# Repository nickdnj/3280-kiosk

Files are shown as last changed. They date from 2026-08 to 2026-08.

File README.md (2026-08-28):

# 3280 Kiosk

An interactive exhibit kiosk for the Vintage Computer Federation museum's
**Concurrent 3280**. A portrait display in a self-contained enclosure, mounted on
the front of the machine's closed factory door. Driven by **three physical
buttons only: BACK / HOME / NEXT. No touchscreen.**

**Rev 1 is a standalone product.** The kiosk is built, wired and bench-tested on
a table before it ever touches the 3280; the reversible mounting adapter is a
separate subsystem designed after that. The machine is not opened, not drilled,
not modified. → **[Rev 1 design study](mechanical/rev1-standalone-kiosk.md)** ·
**[interactive version](mechanical/rev1-design-study.html)**

> ⚠️ **This is a concept — our guiding light, not a shipped product.** Everything
> here describes where we're driving to. The on-screen app is a *concept-review
> build* (cabinet imagery is AI concept art); the hardware folders are still
> empty. Treat every artifact as "the target," not "the deliverable," until the
> team says otherwise.

This repo spans three disciplines:

| Area | Path | Status |
|---|---|---|
| On-screen app | `src/kiosk-app/` | Concept build — clickable, imagery is concept art |
| Button/kiosk controller | `src/controller/` | Concept / placeholder |
| Electronics | `electronics/` | v0 BOM + salvage recon list |
| Mechanical | `mechanical/` | **Rev 1 standalone-kiosk design study** (24″ display, ~15.4 × 28.7 × 3.5″) |

Team: **Software Project Team**, provisioned by AgentArchitect (2026-08-22).

## Going to the museum or the warehouse?

Field materials, all phone-readable:

- **[Measurement field sheet](mechanical/measurement-checklist.md)** — the ME-1
  checklist. Fill the blanks on site.
- **[Salvage shopping list](electronics/salvage-recon.md)** — what to scavenge,
  with monitor acceptance criteria and the powered test to run before de-casing.
- **[Rev 1 design study](mechanical/rev1-standalone-kiosk.md)** — the current
  mechanical design, drawn against measured cabinet dimensions.

> The cabinet is measured (71 × 24 × 34, box 67-7/8″). Monitor outlines, weights
> and thicknesses in the design study are **estimates from typical current
> product**, not measured units — confirm against the actual monitor before
> cutting anything.

## Planning docs

`docs/00-project-brief.md` → `01-prd.md` → `02-architecture.md` →
`03-ux.md` → `04-dev-plan.md`. Work is tracked as
[GitHub issues](https://github.com/nickdnj/3280-kiosk/issues) across five
milestones.

## Start

```bash
claude
```

New here? Read `docs/00-project-brief.md`. The PRD → architecture → UX → dev-plan
flow is complete; work is now execution against the issue list.

## Run the app locally

```bash
cd src/kiosk-app
python3 build-app.py          # rebuild index.html from assets/
open index.html               # or serve the folder
```

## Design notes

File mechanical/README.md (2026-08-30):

# Mechanical — enclosure & mounting

**Rev 1: the kiosk is a self-contained product.** An enclosure holding the
display, the Pi, the power and the three buttons — built, wired and bench-tested
on a table, then hung on the front of the 3280's **closed factory door** by a
mounting adapter designed later, as a separate subsystem.

The 3280 is not opened, not drilled, not modified.

## Start here

- **[`rev1-standalone-kiosk.md`](rev1-standalone-kiosk.md)** — the Rev 1 design
  study. Monitor sizing, buttons, depth, construction, serviceability, and the
  recommendation.
- **[`rev1-design-study.html`](rev1-design-study.html)** — the same study as an
  **interactive review tool**. Front elevation with a live 22/24/27/32 size
  switcher, kiosk front view, button plate, side section, rear. Open it locally
  (`open mechanical/rev1-design-study.html`) or use the published link in the
  project README.

**Recommendation: 24″-class display, buttons at 38″ AFF. Kiosk 15″ W × 30″ H ×
3-5/8″ D, ≈ 23.8 lb — a 3 mm black ACM face on a solid-pine box with a tacked
MDF back, the face plate CNC-cut to order rather than fabricated on site.**

The plate's window is cut **3/16″ smaller than the monitor's lit rectangle**, so
the ACM masks the last 3/32″ of picture on every side and **no bezel is ever
visible**: illuminated LCD in a crisp routed opening, and nothing else. A 1/4″
black foam light seal behind the plate kills the shadow line. There is no
shroud. That decision, and what it costs, is in
[`fab-rev1/README.md`](fab-rev1/README.md).

## Scope

- **The enclosure.** Face plate, structural box, removable rear panel, internal
  frame, VESA mount, ventilation, service access.
- **The buttons.** BACK / HOME / NEXT cut straight into the face plate,
  centreline **38″ AFF — set by the ADA §308 reach range, and the datum the whole
  kiosk is placed from.** 30 mm anti-vandal switches at 3.50″ centres.
- **The mounting adapter.** *Deliberately deferred.* The enclosure carries a flat
  rear interface zone and a known weight; that's all the adapter needs to inherit.
  It must be **reversible, non-destructive, removable and visually discreet** —
  this is a museum artifact, and that is a hard requirement.

## Reference — what the machine actually is

Only the **external** dimensions matter for Rev 1.

| | | Provenance |
|---|---|---|
| Cabinet overall | 71″ H × 24″ W × 34″ D | OEM 50-045R00 |
| Cabinet box, less feet | 67-7/8″ | measured, ME-1 |
| Feet | 3-1/8″ | derived |
| Outer door | ≈ 24.3″ W × 68.2″ H, ≈ 3″–71″ AFF | 3230 drawing + derived |
| Factory paint | P.E. #464 textured | 3230 drawing |

- **[`me1-findings.md`](me1-findings.md)** — the site visit. The machine has
  **two doors, not an open card cage**. Still the governing field record.
- **[`cabinet-spec-oem.md`](cabinet-spec-oem.md)** — Concurrent's published spec.
- **[`cabinet-drawings-3230.md`](cabinet-drawings-3230.md)** — Perkin-Elmer's
  mechanical drawings for the sibling 3230.
- **[`photos/`](photos/)** — site photographs.
- **[`measurement-checklist.md`](measurement-checklist.md)** — the ME-1 field
  sheet. Mostly satisfied; **C1 no longer gates anything** under Rev 1.

## Superseded for Rev 1 — kept for provenance, live again for Rev 2

Everything below designs the kiosk as a **replacement door** integrated into the
cabinet aperture. That concept is not dead — it is deferred to Rev 2 — but
nothing in Rev 1 should be built from it.

- [`monitor-selection.md`](monitor-selection.md) — the 27″ call. *Its go/no-go
  monitor criteria still apply.*
- [`display-approach-options.md`](display-approach-options.md) — hinged carrier panel.
- [`door-construction.md`](door-construction.md), [`fab/`](fab/) — the
  de-cased-panel fabrication route. **Rev 1 keeps the monitor cased.**
- [`dimensions-assumed.md`](dimensions-assumed.md),
  [`enclosure-buy-vs-build.md`](enclosure-buy-vs-build.md).
- [`drawings/`](drawings/) sheets 01–06, and [`drawings/superseded/`](drawings/superseded/).

## Cut files — ready to order

**[`fab-rev1/`](fab-rev1/)** holds the face plate as DXF, generated and
self-checked by [`make-cutfiles.py`](fab-rev1/make-cutfiles.py) from
[`_p1.py`](fab-rev1/_p1.py): **P1**, one piece, **15 × 30″**, with the switch
cutouts routed straight in.

**[`cutlist/`](cutlist/)** turns the same module into a Home Depot buy plan and
a nine-crosscut cut list; **[`build-kit/`](build-kit/)** turns it into a
22-page wordless build cookbook. One source of truth, three outputs.

⚠️ **P1 is not releasable yet.** Two numbers gate it — the ⌀30.5 mm switch
cutout, and the monitor's measured lit rectangle. The box is gated on neither.

## Can we just buy an enclosure? — no

**[`ikea-build/`](ikea-build/)** — *shelved 2026-08-29,* kept for one finding
that keeps mattering: **no off-the-shelf shallow cabinet can work.** ADA §307.2
allows the kiosk **4.000″ of total projection**; the shallowest wall cabinets
made are 6¾″ deep, and picture frames shallow enough to pass are thin MDF that
will not carry 24 lb or hold a panel-mount switch. Too deep or too flimsy, with
nothing in between.

The directory also holds a costed IKEA-pine variant and a 15-page illustrated
assembly manual. Neither is the build route — **the box is ½″ Baltic birch per
sheets 300 / 301 / 302**.

## Still to produce

- `cad/` — enclosure and internal frame models (source + STEP).

- `mounting.md` — the reversible adapter, after the kiosk bench-tests clean.

## The sequence

1. **Choose the monitor** — buy or salvage, run the power-cut test, and check
   it against the three fit limits (chin ≤ 0.92″, long-edge bezel ≤ 0.60″, body
   ≤ 2.12″). Then measure the **lit rectangle**: that is what P1's window is cut
   from. ← *gate, and now it gates the face plate too*
2. Build the enclosure. Bench, no 3280 involved.
3. Install monitor, Pi, buttons, wiring, software.
4. Bench-test as a complete kiosk.
5. **Then** design and build the reversible mounting adapter.
6. Rev 2, if desired, revisits the replacement-door concept.

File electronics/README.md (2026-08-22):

# Electronics — the kiosk's electrical hardware

Everything that carries a signal or a volt in the kiosk: the three buttons, the
display, the single-board computer, power, and the wiring that joins them.

## Scope

- **Buttons.** Three arcade/industrial momentary pushbuttons (BACK / HOME /
  NEXT), their harness, and pull-up/debounce approach.
- **Display.** Portrait panel — model, interface (HDMI/DSI), power, backlight,
  brightness for museum lighting.
- **Compute.** SBC selection, storage, and how it drives display + reads buttons
  (see `../src/controller/`).
- **Power.** Single-cord entry, distribution, on/off, surge, and safe shutdown.

## What's here now

- **[`salvage-recon.md`](salvage-recon.md)** — the warehouse shopping list:
  what to look for, acceptance criteria (especially for monitors), the powered
  test to run before de-casing anything, and what to write down.
- **[`bom.md`](bom.md)** — v0 bill of materials, salvage-first, marked
  Have / Salvage / Buy.

## Deliverables still to produce

- `bom.csv` — machine-readable BOM with part numbers once parts are chosen.
- `wiring/` — pinout tables and wiring diagrams (button → GPIO, display, power).
- `schematics/` — schematic + any adapter boards (KiCad preferred; export PDFs).
- `assembly.md` — how it goes together and how it's tested.

Empty for now — populated during the hardware design phase. Keep proprietary or
purchased datasheets out of git; link to them from `bom.md` instead.

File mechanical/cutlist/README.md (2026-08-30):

# The box — 15 × 30, whole numbers

> ⚠️ **Concept.** Nothing cut. Prices seen at Home Depot **West Long Branch,
> 2026-08-29**.

**Zero rips. Nine crosscuts. Every dimension a multiple of ¼″.**

```bash
python3 make-cutlist.py            # 23 checks, all passing
```

The box reads its geometry from **[`../fab-rev1/_p1.py`](../fab-rev1/_p1.py)** —
the same module the DXF and the print stencil are generated from. There is one
source of truth now; the box cannot disagree with the face plate.

---

## 1. Buy — $68.86, spares included

| | Model | Qty |
|---|---|---|
| **1×4 × 8 ft Kiln-Dried Whitewood** (actual .750 × 3.5) | 914681 | ×2 |
| **1×3 × 8 ft Kiln-Dried Whitewood** (actual .750 × 2.5) | 914649 | ×3 |
| **½″ × 2 × 4 MDF Project Panel** | 109097 | ×1 |
| Titebond II · 120 + 180 grit · #6 × 1¼ screws | | |

**Whitewood, because it is a true ¾″.** That is what makes the cut list land on
halves and quarters — a 0.719″ finger-jointed board gives a 13.562″ cavity
instead of 13.500″. The trade is straightness: whitewood arrives knottier and
more bowed, so **sight down every board in the rack** and reject the bent ones.
If you would rather have the straighter stock, `--ply 0.719` re-derives
everything for finger-jointed primed pine.

## 2. Cut — nothing is ripped

The board's **width becomes the box depth**. A 1×4 is 3.5″ wide, so the tube is
3.5″ deep by crosscut alone; the 1×3 gives the button rail, rear cleats and VESA
rails at its full 2.5″ width.

```
1x4, full 3.5" width     P2  3-1/2 x 30       x2
                         P3  3-1/2 x 13-1/2   x2
1x3, full 2.5" width     P7  13-1/2           x1
                         P8  28-1/2           x2
                         P9  28-1/2           x2
MDF, cut by Home Depot   P4  13-1/4 x 28-1/4
                         P10 4 x 3
```

**Home Depot cuts the MDF.** The rear panel is deliberately ¼″ undersize and
lands on a 2½″ ledge, so their ±1/8″ cannot matter. You never handle a sheet
good.

**Crosscut P2 first, dry-assemble, and measure the real cavity** before cutting
anything else.

## 3. The tightest number in the box — 1/16″, and it is not where you'd look

The face plate window is centred on the plate, and the **picture** is centred on
the window. So the **casing is not centred.** In portrait, a monitor's thick
"chin" bezel lands on a *side* edge, and centring the picture pushes the casing
sideways by half the chin-to-thin difference — **0.248″** on the nominal
monitor.

That turns a comfortable 0.315″ per side into **0.0665″ on the chin side.** It
fits. It is checked on every run. But it is the number that decides whether a
given monitor goes in the box at all, so it is a **buy criterion**, not a build
detail:

| | limit | nominal |
|---|---|---|
| thick bezel — the chin, a SIDE edge in portrait | **≤ 0.92″** | 0.85 |
| bezel on the long edges — top and bottom in portrait | **≤ 0.60″** | 0.35 |
| body thickness at its deepest | **≤ 2.12″** | 1.80 |

The chin budget shrinks as the panel grows: **0.97″** at a 23.6″ diagonal,
**0.92″** at 23.8″, **0.87″** at a true 24.0″. All three are realistic for a real
monitor, so nothing is excluded — but check the one you are buying.

`MON_OW` is an estimate until you own the monitor. **Measure the actual panel
before cutting P3.**

## 4. Build

1. **Tube** — P2 sides over P3 top and bottom. Glue and screw, **pilot every
   hole**; pine end grain splits.
2. **Button rail** — P7, front-flush, centreline **24″** below the top edge.
   It takes the press load so the face plate can't flex under a thumb.
3. **Rear cleats** — P8 ×2, **turned 90°** so they lie ¾″ deep and sit entirely
   behind the monitor rather than alongside it.
4. **Inserts** — 15 on P1's pattern, **½″ in from the edge**. At the old 5/8″
   a 0.375″ insert broke out of a ¾″ board edge; at ½″ it spans 0.3125–0.6875
   and sits entirely inside. **Epoxy them.**
5. **Rails** — P9 ×2 on the VESA centres. Monitor, Pi tray, wiring.
6. Switches into P1. Then the **foam light seal** onto the back of P1 — 1/4″
   black closed-cell neoprene, 1/8″ out from the window edge, all the way round.
7. P1 on, then the back panel.

> The face plate must **never** clamp the monitor. The P9 rails set the
> monitor's position 1/8″ behind the ACM; the foam is 3/16″ thick and lands at
> 33 % compression. If the plate is fighting the panel, move the rails.

**23.8 lb.** Enclosure **3.618″** deep, leaving the mounting adapter **0.382″**
of the ADA §307.2 4.000″ cap.

> ⚠️ **MDF is safe only because P9 exists.** The monitor hangs on the VESA rails;
> P4 is a cover and no fastener enters an MDF edge.

## 5. No front cleats — that was a bug fix

Every earlier version, **including the released drawing package**, put cleats
behind the face plate to receive P1's screws. They never fitted: the released
½″ wall plus 1.000″ cleat eats 1.500″ per side, and the monitor only has 1.250″
of margin. It fouled by 0.250″ per side, and the top cleat fouled the monitor's
top edge by the same.

All 15 of P1's holes already land in solid material without them — ten in the
side boards' front edges, two in the top and bottom boards, three in the button
rail. P5 and P6 are deleted. There is a permanent check that passes this plan
and **fails the released configuration**.

## 6. What this supersedes

The whole released drawing package is now stale — the envelope itself moved.

| | was | now |
|---|---|---|
| Plate | 15.370 × 28.690 | **15 × 30** |
| Window | 12.170 × 21.240 | **11½ × 20-9/16** — now *smaller* than the picture |
| Button datum below top | 25.440 | **26** |
| Kiosk bottom AFF | 34.750 | **34** |
| Mount holes in from edge | 0.625 | **0.500** |
| Enclosure depth | 3.250 | **3.618** |
| Front cleats P5 P6 | 1.000 sq | **deleted** |

Buttons stay at **38″ AFF** — that never moves, it is the ADA datum everything
else is placed from.

Rev 2b then changed the window again — **11½ × 20-9/16, smaller than the lit
area** — so the plate now masks the bezel instead of framing it. See
[`../fab-rev1/README.md`](../fab-rev1/README.md).

**The SendCutSend quote must be redone.** $61.43 was for 441 sq in; this is 450.

## 7. Alternatives

`--allow-rip`, `--stock ply`, `--board 5.5`, `--back tacked`, `--ply 0.719`.

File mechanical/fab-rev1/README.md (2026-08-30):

# Rev 2b cut file — 15 × 30, and the window now overlaps the LCD

> ⚠️ **Not released, and now gated on the monitor.** The window is cut from the
> monitor's **lit rectangle**, which nobody has measured yet. Print the stencil,
> build the box, buy the monitor, measure it, re-run, *then* order.

**One part.** 15 × 30″ in **3 mm aluminium composite (ACM), matte black both
sides**, CNC routed. Generated by [`make-cutfiles.py`](make-cutfiles.py) from
**[`_p1.py`](_p1.py)** — the single source of truth that the cut file, the
stencil and the box all read. Change geometry there and nowhere else.

**Every layout dimension is a multiple of 1/16″.** 23 of them, checked on each
run. The only number that isn't is the ⌀30.5 mm switch cutout, which is metric
and set by the hardware.

| | |
|---|---|
| **File** | [`P1-face-plate.dxf`](P1-face-plate.dxf) — preview: [`P1-face-plate.svg`](P1-face-plate.svg) |
| **Outside** | **15 × 30″**, R1/4 corners |
| **Screen window** | **11-1/2 × 20-9/16″**, R1/4, set 1-3/4 in from each side and 1-1/2 down from the top. **Provisional** — see below |
| **Buttons** | 3 × ⌀1.2008″ (30.5 mm) at 3-1/2″ centres, **x = 4, 7-1/2, 11**, centreline **26″** below the top edge |
| **Mounting** | 15 × ⌀3/16″ — five per side at **1/2″** in, two on the centreline, three on the button rail at y = 24″ |
| **Placement** | bottom **34″ AFF**, top **64″**, buttons **38″ AFF** |

## Ordering at SendCutSend

1. **Upload `P1-face-plate.dxf`.**
2. **Material:** *Aluminum Composite (ACM)* → **0.118″ (3 mm)** → **matte black**.
3. **Quantity:** 1.
4. **Secondary services:** none. Confirmed with SendCutSend's material page —
   ACM is *"not anodizable or powder coatable; the surface finish comes from the
   manufacturer,"* and **CNC routing is the only service offered for it**. So
   there is nothing to decline: the options simply aren't there.
5. **Engraving is not available on ACM.** Labels are a separate step — see below.

Well inside their 44 × 31″ instant-quote maximum. CNC routed to ±0.005″.

### Quoted 2026-08-29

| | | |
|---|---|---|
| **ACM Black .118″, no services** | **$61.43** | ships in ~3 days |
| 6061-T6 .125″, deburred, matte black powder | $214.72 | ships in ~2 weeks |

The aluminium version was priced and rejected. It is not a bad part — solid 6061
is stiffer and powder coat wraps the cut edges — but **the stiffness argument is
already answered by the button rail**, which takes the press load so the panel
can't flex under a thumb. Buying stiffness twice is not worth 3.5×, and the
budget is better spent on the monitor and the mounting adapter, both still open.
The extra 0.007″ of thickness was *not* the objection: it takes overall depth to
3.257″, still inside the ADA §307.2 cap of 4.000″.

## The window is now smaller than the picture

Until Rev 2b the window was cut **generous** — a quarter inch of slack per side
that landed on the monitor's own black bezel. Black on black; nothing shows.

That was wrong, and it is the kind of wrong you only see once it is built. A
bezel is not the same black as a matte ACM panel, it has a different sheen, it
usually carries a moulded logo and a power LED, and there is always a shadow
line at the transition. What you would have got is a monitor visible inside a
hole. What a museum instrument looks like is **illuminated LCD in a crisp routed
opening, and nothing else.**

So the rule is inverted. **The window is cut 3/16″ smaller than the lit
rectangle in each direction** — the ACM masks the outer **3/32″ of picture on
every side** and the bezel never appears at all.

The masked strip is about **8 pixels** of 1080 per side. At three to six feet
that is invisible; the kiosk UI has margins far larger than that anyway.

### What it costs

The face plate is no longer independent of the monitor. It used to be safe to
cut before the monitor arrived, because the monitor was aligned to the window by
the internal VESA frame. Now the window is derived *from* the monitor, and the
derivation is unforgiving: across the range of panels sold as "24 inch", the
right window height varies by **0.35″** — four times the whole overlap. Cutting
this window for the wrong panel either exposes bezel or crops visibly.

**So the monitor gate now comes first.** It always was first in the build
sequence; it just didn't block this part before.

### Measure it like this

1. Power the monitor. Display a **full-screen white image**.
2. Measure the **lit rectangle** with a tape — not the advertised diagonal, not
   the outside of the casing.
3. Put the two numbers into `ACT_W` / `ACT_H` in `_p1.py`, set
   **`ACT_MEASURED = True`**, and re-run. The window follows automatically,
   rounded to land on tape marks.

Until that flag is set, `make-cutfiles.py` stamps the SVG **NOT FOR RELEASE**
and prints a banner. That is deliberate.

Step **0** of the build cookbook is this measurement, with a drawing.

## The light seal — and why there is no shroud

Behind the plate, around the window, goes **1/4″ wide × 3/16″ thick black
closed-cell neoprene foam tape**, set **1/8″ out from the window edge**. About
65″ of it.

Its only job is to kill the light leak and the shadow line between the ACM and
the bezel. It is **not a gasket and not structure**:

- The **VESA rails set the monitor's position** — 1/8″ back from the ACM. The
  foam is 3/16″ uncompressed, so it lands at **33 % compression**: enough to
  seal, nowhere near enough to push the panel.
- **Never let the plate clamp the glass.** If the foam is doing work, the
  monitor is in the wrong place; move the rails, not the plate.
- **The foam must never touch the LCD.** The 1/8″ inset guarantees that: the
  picture ends 3/32″ out from the window edge, so the foam starts 1/32″ beyond
  the glass and lands wholly on the bezel. `_p1.py` checks both edges.

**No shroud.** A hood behind the window would add parts, collect dust and make
service worse, and it buys nothing a 1/8″ setback and a black plate don't
already give. Against a matte black face the opening reads as a deep black
window on its own.

## ⚠ And still confirm this number

**⌀30.5 mm is the cutout for a "30 mm" anti-vandal switch.** Most want
30.2–30.5 mm and cutting the larger size is the safe direction — the nut and
washer cover the slack. **But this is a one-piece part now, so a wrong cutout
means recutting the whole face.** Check it against the datasheet of the switch
you are actually buying, along with:

- **panel thickness range includes 3 mm**
- **actuation force ≤ 5 lbf** (ADA §309.4)

If your switch wants a different cutout, change `BTN_HOLE` in the script and
re-run.

**Do not order ahead of this check.** There are now **two** gates on P1: the
switch cutout above, and the measured lit rectangle. Both are cheap to clear and
neither is recoverable after the part is routed.

## Why one piece

An earlier version split this into a face plate plus a separate button plate.
That was over-engineered. The separate plate bought insurance against the switch
cutout, and paid for it in cost, stiffness and assembly:

- Cutting both a 12.17 × 21.24 window **and** an 11.87 × 3.00 button aperture out
  of one 3 mm sheet left a **1.35″ web** as the only thing joining the side rails
  below the screen. One piece leaves **2.25″** above the buttons and **2.65″**
  below — a much stiffer part.
- One part on the invoice instead of two, six fewer holes, no second set of
  cleats, and no plate to align square in an aperture.
- The wear argument didn't hold up: anti-vandal switches are rated for millions
  of cycles, and when one fails you replace **the switch**, through the same hole.

The insurance is better bought by **confirming the cutout before ordering** than
by designing around not knowing it.

## What the drawing assumes

- **The button centreline lands 26″ below the top edge.** With the kiosk bottom
  at **34″ AFF** that puts the buttons at **38″ AFF** — the ADA datum the whole
  design is placed from. Both numbers are now whole. Don't change the plate
  height without redoing that arithmetic; `_p1.py` checks it on every run.
- **Mount holes moved from 5/8″ to 1/2″ in from the edge.** At 5/8 a 0.375″
  brass insert broke out of a 3/4″ board's front edge. At 1/2 it spans
  0.3125–0.6875 and sits entirely inside. That was a real defect, not a tidy-up.
- **The screen window is deliberately undersize** — it laps 3/32″ over the
  picture on every side, so no bezel is visible. See above. This is the change
  that made P1 depend on the monitor.
- **The window is centred on the plate, so the picture is too — and the casing
  therefore is not.** In portrait, a monitor's thick "chin" bezel ends up on a
  **side** edge, and centring the picture shifts the casing sideways by half the
  chin-to-thin difference. On the nominal monitor that is 0.248″, which leaves
  only **1/16″** between the casing and the cavity wall on the chin side.
  It fits, but it is the tightest number in the box, and it turns the chin into
  a buy criterion: **chin ≤ 0.92″**. `make-cutlist.py` checks it.
- **The cleat row** — three holes between the window and the buttons — lands on a
  plywood rail that takes the press load, so the panel doesn't flex when a
  visitor pushes a button. It sits above the switch bodies, which protrude about
  an inch behind the plate.

## Cardboard mock-up — print it 1:1 first

**[`P1-face-plate-stencil.pdf`](P1-face-plate-stencil.pdf)** tiles this part
across **eight US Letter pages at full size**, plus an instruction sheet. Print it, tape the sheets on the
registration marks, cut the voids, and trace the shape onto cardboard.

**Print the PDF, not the HTML.** The page box is embedded at exactly 8.5 × 11,
so "Actual size" prints true 1:1. Printing HTML from a browser is where scale
errors come from. [`stencil-letter.html`](stencil-letter.html) is the source.

1. Print at **Actual size / 100%** — *not* "Fit to page" — and **Margins: None**.
2. **Measure the red bar on sheet 1. It must be exactly 4.000 inches.** If it
   isn't, the printer scaled the page; nothing downstream will line up.
3. Tape on the registration crosses in the shaded overlap bands (0.80″
   horizontal, 3.20″ vertical). The 1″ grid is the real check — lines must run
   straight across every joint and the printed `x,y` coordinates must agree on
   both sides of the tape.
4. Cut the heavy dashed outlines (window and buttons). The small circles are
   mounting holes — **mark only**. Cut the outside profile **last**.

Hold the cardboard against the 3280 with its **bottom edge 34″ above the
floor**; that puts the button centres at 38″ AFF. Proportion is the argument
this design turns on, and a photograph of cardboard on the real machine settles
it in a way no drawing can. Take one straight on from six feet and one from
about 45°.

Regenerate with `python3 make-stencil.py`.

## Labels

There is no text in the DXF, and **SendCutSend does not engrave ACM** — routing
is the only service they offer on it. So lettering is a separate step, and the
native answer is **cut vinyl from a sign shop**: this is sign material, and it is
how every road sign is lettered. Durable, cheap, and replaceable when a docent
decides BACK should have said PREVIOUS.

## Regenerating

```bash
python3 make-cutfiles.py
```

Prints a self-check on every run: contour closure, holes clear of the window,
feature spacing and minimum hole size against the 0.118″ material, the part
inside the service maximum, the window clearing every panel sold as "24 inch",
the window still lapping the picture on all four sides, the foam landing on
bezel rather than glass, and the button datum still landing at 26″.

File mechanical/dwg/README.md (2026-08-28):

# Rev 1 manufacturing drawing package

Twelve B-size (17 × 11) sheets, third-angle projection, ANSI-style title blocks.

**[`3280-kiosk-rev1-drawing-package.pdf`](3280-kiosk-rev1-drawing-package.pdf)** —
the whole package as one file. This is what you send to a shop. Fonts are
embedded, so it looks the same everywhere.

**[`index.html`](index.html)** — the same sheets in the browser, with a print
stylesheet (one sheet per page, Letter landscape, *Fit to page*).

| Sheet | | |
|---|---|---|
| **000** | Cover, drawing index, general notes | material and finish schedule, the ADA derivation, the museum constraint |
| **100** | General arrangement | front / side / top, plus the kiosk drawn on the 3280 with the ADA reach band |
| **101** | Exploded view and BOM | 21 numbered items, balloons, source sheet per part |
| **102** | Section A-A | rotated 90° CW; internal stack and the full depth chain |
| **200** | **P1 face plate** | the cut drawing — fully dimensioned, feature schedule |
| **300** | P2 side panel, P3 top/bottom | plus a horizontal section through the monitor zone |
| **301** | P4 rear panel, P9 VESA rail, P10 Pi tray | slot detail and the shim-to-suit note |
| **302** | P5–P8 cleats and button rail | insert locations and the clamp-and-spot method |
| **400** | Hole and fastener schedule | every hole tagged, located, and matched to an item |
| **500** | Electrical | power distribution and the button circuit, with GPIO assignment |
| **600** | Assembly sequence | twelve steps, bench test before the machine is touched |
| **700** | Inspection dimensions | nominal, tolerance, method, and why each one matters — with sign-off |

## Regenerating

```bash
python3 make-package.py     # writes 000.svg … 700.svg
python3 check-sheets.py     # nothing outside the printable area
../make-pdfs.sh             # rebuild the PDF deliverables
```

The SVGs are the reviewable artifact — they diff cleanly in git, so a revision
shows up as changed geometry rather than a changed blob. **The PDF is the
handoff.** Rebuild it when you issue a revision, not on every commit.

All geometry lives in [`_geom.py`](_geom.py), which mirrors
[`../fab-rev1/make-cutfiles.py`](../fab-rev1/make-cutfiles.py). Change a
dimension there and re-run both — the DXF and the drawings cannot drift apart.
[`_sheet.py`](_sheet.py) is the sheet framework: frame, zones, title block,
dimensions, leaders, balloons, section hatching.

## Status

**Concept package — not released for production.** Two things gate release:

1. **⌀30.5 mm** on sheet 200 is nominal for a 30 mm anti-vandal switch. Verify it
   against the datasheet of the switch actually bought. This is a one-piece part.
2. **The monitor.** Sheet 301's depth is shimmed to suit, and the go/no-go
   criteria on sheet 700 — powers itself back on after a mains cut, matte only —
   are not optional.

The mounting adapter is deliberately **not** in this package. See sheet 000
note 10.

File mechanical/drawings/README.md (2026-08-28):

# Drawings

> ## ⛔ SUPERSEDED FOR REV 1
> The kiosk is no longer a replacement door integrated into the cabinet. It is a
> **self-contained enclosure surface-mounted on the closed factory door** — see
> [`../rev1-standalone-kiosk.md`](../rev1-standalone-kiosk.md) and the
> [interactive design study](../rev1-design-study.html).
> This document describes the **Rev 2** concept and is kept for provenance.
> Don't build from it.

All six sheets are generated from **one shared geometry block** in
[`make-drawings.py`](make-drawings.py). Change a dimension there and re-run:

```bash
cd mechanical/drawings
python3 make-drawings.py        # 01–06
python3 make-monitor-fit.py     # 07
```

| | Sheet | What it settles |
|---|---|---|
| 01 | [Front elevation](01-front-elevation.svg) | The whole thing at real scale; ADA band, screen and button heights |
| 02 | [Carrier panel](02-carrier-panel.svg) | Every feature dimensioned, with a schedule — the fabrication sheet |
| 03 | [Plan section](03-plan-section.svg) | Depth budget, swing envelope, **the C1 requirement** |
| 04 | [Door replacement](04-door-replacement.svg) | How it mounts, and why it's reversible |
| 05 | [Assembly stack](05-assembly-stack.svg) | Carrier panel + cased monitor + Pi |
| 06 | [Recessed vs proud](06-recessed-vs-proud.svg) | The open aesthetic choice — for the docents |
| 07 | [Monitor fit](07-monitor-fit.svg) | Why 27″ and not 24″ |

## Geometry these are built on

```
cabinet     24.00" W x 71.00" H x 34.00" D      OEM 50-045R00
base         3.125"                             derived (71.00 - 67.875 measured)
opening     19.75" clear                        measured
frame offset 2.125" uniform, all four sides     assumption, 2026-08-27
aperture    19.75" x 63.625"   (5.25" AFF)      derived
door        24.30" x 68.175"   (2.98" AFF)      derived, 0.15" overhang all round
monitor     27" 16:9 portrait, 13.94 x 24.68    chosen
buttons     34" AFF     screen centre ~49" AFF  chosen
C1 required 2.48"                               STILL UNMEASURED
```

⚠️ **[`superseded/`](superseded/)** holds the pre-measurement set. Don't build
from those.

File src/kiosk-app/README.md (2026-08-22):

# Kiosk App — on-screen UI (concept build)

> **Concept, not shipped.** This is the concept-review build we're driving
> toward. It's clickable and real, but the cabinet imagery is AI concept art and
> the screen copy is an early draft. A visible "Concept" marker sits on the
> kiosk render and the enlarged view — keep it until the piece is built.

The portrait touch-free display software for the Concurrent 3280 exhibit kiosk.
Operated by **three physical buttons only** (BACK / HOME / NEXT) — there is no
touchscreen. A docent (or visitor) steps through a short deck of screens: the
machine's story, what it did, and a look inside the real card cage.

## What's here

- `index.html` — the built, fully self-contained app (all images inlined as
  base64 data URIs). This is the file the kiosk actually loads. ~4.8 MB.
- `build-app.py` — the builder. Reads the raw assets under `assets/`, inlines
  them, and writes `index.html` by token replacement. **Edit content here and
  rebuild — do not hand-edit `index.html`.**
- `assets/` — source images (renders, poster art, montage photos, logos) at
  web resolution, before inlining.

## Build

```bash
cd src/kiosk-app
python3 build-app.py      # regenerates index.html from assets/ + the CARDS deck
```

## Origin

Started life as a shareable **concept-review Artifact** (published to
claude.ai/code) so the docent team — led by Rick Lewis — could react to the
idea before any hardware existed. Rick's review shaped the current content spec:
cut copy to ~30%, 3–5 short bullets per screen, a strong graphic, big
sans-serif type readable at 3–6 ft, and technical facts contextualized for a
general audience. See `docs/` for the full brief.

## Next (for the software team)

- Decouple content from the single HTML blob (data file + template) so non-devs
  can edit screens.
- Kiosk hardening: fullscreen, no cursor, no scrollbars, disable gestures/context
  menu, auto-restart on crash, attract-loop / idle reset to HOME.
- Wire the on-screen nav to real GPIO buttons via `../controller/`.
- Optional anonymous usage tracking (Rick's ask) — which screens get viewed.

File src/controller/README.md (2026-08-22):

# Controller — buttons → app bridge

The software that runs on the kiosk's single-board computer: it launches the
kiosk app in a locked-down fullscreen browser and maps the three physical
buttons to app navigation.

## Responsibilities

- **Boot to kiosk.** On power-up, bring up the display, hide all OS chrome, and
  launch `../kiosk-app/index.html` fullscreen (kiosk/kiosk-mode browser).
- **Read the buttons.** Debounced GPIO input for BACK / HOME / NEXT.
- **Drive navigation.** Translate button presses into app actions (previous
  screen / return to HOME / next screen). Likely via synthetic key events or a
  tiny local WebSocket the app listens on.
- **Stay up.** Watchdog / auto-restart on crash; idle timer that returns to
  HOME after N minutes of no input (attract state).

## Undecided (for the architecture phase)

- Compute platform: Raspberry Pi (4/5) vs. other SBC. Drives GPIO choice,
  power budget, and the mounting in `../../electronics/` and `../../mechanical/`.
- Button interface: direct GPIO vs. a USB HID adapter.
- App↔controller transport: injected key events vs. local socket.

Nothing is built here yet — this folder is a placeholder the software team fills
in after the architecture doc lands.

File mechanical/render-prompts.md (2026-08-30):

# Image-generation prompts — kiosk concept renders

> ⚠️ **Concept art.** Anything produced from these is a *visualisation of the
> target*, not a photograph of a built object. Label it that way wherever it is
> used, per the project's concept rule.

Proportions below are derived from [`fab-rev1/_p1.py`](fab-rev1/_p1.py). Image
models follow **percentages and ratios** far better than inch dimensions, so
every prompt states both.

**The single most important line in all of these: the kiosk is exactly twice as
tall as it is wide.** If a render comes back squarer than that, it is wrong and
everything else about it will look wrong too.

---

## Shared spec — paste this at the top of any of the four prompts

```
SUBJECT: a small wall-mounted interactive museum kiosk. Self-contained
rectangular enclosure. NOT a tablet, NOT a touchscreen, NOT a floor-standing
totem.

PROPORTIONS — follow these exactly:
- The enclosure is 15 inches wide by 30 inches tall by 3-5/8 inches deep.
- It is EXACTLY TWICE AS TALL AS IT IS WIDE. A precise 1:2 rectangle.
- Depth is about a quarter of the width — a shallow slab, not a box.
- Corners are softly rounded, radius about 1.7% of the width. Nearly square.

MATERIALS:
- Front face: matte black aluminium composite panel, 3 mm, CNC routed.
  Dead flat, completely non-reflective, fine even satin texture. No gloss,
  no mirror, no highlights. Crisp machined edges.
- Body: solid pine, painted satin black, faint wood grain readable through
  the paint under raking light.
- Fasteners: small black button-head machine screws, flush.

LIGHTING AND CAMERA: soft even studio light, one large softbox front-left and
a subtle fill right. Neutral seamless mid-grey background. Straight-on
orthographic framing, camera centred on the object, no perspective distortion,
no wide angle. Sharp throughout. Photorealistic product photography.

DO NOT INCLUDE: any logo, brand mark, lettering or label on the enclosure;
any glossy or reflective surface; a touchscreen; more or fewer than three
buttons; visible cables; visible seams other than those described; people;
a floor stand or pedestal.
```

---

## 1 · FRONT

```
[paste the shared spec, then:]

FRONT VIEW, straight on.

A matte black rectangular face plate fills the whole front, 15 x 30 inches,
exactly twice as tall as wide.

SCREEN OPENING: a single portrait rectangular cutout, 77% of the enclosure
width, centred left to right with equal 11.5% margins. Its top edge sits 5% down
from the top of the enclosure; its bottom edge sits 26.5% up from the bottom.
Behind it a portrait computer monitor is switched on, sitting about 1/8 inch
back. CRITICAL: no monitor bezel, frame, chin, logo or power LED is visible
anywhere — the face plate laps over the edge of the picture, so the cutout is
filled edge to edge with live illuminated image right up to the routed edge.
The opening reads as a clean machined window in solid panel with a shallow
shadowed reveal. It must not look like a monitor sitting inside a hole.

WHAT IS ON THE SCREEN: a portrait museum exhibit page. Large white sans-serif
headline across the upper third, three or four short lines of white body text
below it, generous spacing, near-black background. Softly self-illuminated,
legible, not blown out. Keep the text generic and unreadable at small size.

BUTTONS: exactly three round pushbuttons in a horizontal row low on the face,
below the screen opening. Centreline sits 13% up from the bottom of the
enclosure. They are 30 mm brushed stainless steel anti-vandal buttons —
diameter about 8% of the enclosure width — with flush domed heads and a thin
knurled ring where each meets the panel. Spacing between centres is 23% of the
width, so the outer two sit well inboard of the edges. All three identical and
unlabelled.

SCREWS: fifteen very small black button-head screws around the perimeter of
the face plate, set 3% in from the edge — five evenly spaced down each long
side, one top centre, one bottom centre, and a row of three just above the
buttons. Subtle, flush, easy to miss.
```

---

## 2 · BACK

```
[paste the shared spec, then:]

REAR VIEW, straight on.

The back of the same 15 x 30 inch enclosure — again exactly twice as tall as
wide.

A satin black painted solid pine frame about 3/4 inch wide runs around the
whole perimeter. Set INSIDE it and slightly RECESSED is a flat rear panel of
1/2 inch MDF, painted the same satin black, with a fine uniform surface and no
grain. The recess is shallow — about 1/2 inch — and reads as a clean deliberate
step with a soft shadow line, not a gap.

FASTENERS: six small knurled black thumbscrews holding the rear panel to the
frame — three evenly spaced down each long side, none top or bottom. Knurled
heads standing slightly proud, clearly meant to be turned by hand.

ONE OPENING ONLY: a small rectangular fused IEC C14 power inlet, low on the
rear panel and slightly left of centre, black, flush-mounted, with its three
recessed pins visible.

Otherwise the back is completely plain. No vents, no labels, no cables, no
brackets, no other holes.
```

---

## 3 · SIDE

```
[paste the shared spec, then:]

SIDE VIEW (left profile), straight on.

A tall narrow slab. The silhouette is 30 inches tall and only 3-5/8 inches
deep — a depth-to-height ratio of about 1:8. Emphasise how SHALLOW it is: this
is a flat panel with a little depth, not a cabinet.

Reading front to back across that 3-5/8 inches:
- At the very front, a crisp 1/8 inch black edge — the aluminium composite
  face plate, its machined edge catching a thin highlight.
- Then the painted satin black pine body making up nearly all the depth, with
  faint wood grain showing through the paint under raking light.
- At the very back, a fine shadow line where the recessed rear panel sits.

Softly rounded vertical corners top and bottom. No fasteners visible from
this angle. No mounting hardware — the back is flat and bare.

Light it from the front-left so the front edge and the body separate clearly
and the shallow depth is unmistakable.
```

---

## 4 · INSTALLED IN CONTEXT (optional, and the most useful one)

```
[paste the shared spec, then:]

THREE-QUARTER VIEW of the kiosk mounted on the front of a large vintage
minicomputer cabinet, in a museum gallery.

THE CABINET behind it: a 1970s-80s minicomputer, about 6 feet tall, 2 feet
wide and just under 3 feet deep. Beige-tan textured factory paint, slightly
aged. A tall louvered front door with fine horizontal vent slots. Plain,
industrial, no visible branding. It stands on the floor on a low plinth.

THE KIOSK is mounted flat on the closed front door of that cabinet, centred
left to right, its bottom edge about waist height — 34 inches above the floor,
so the buttons fall at 38 inches. The kiosk occupies roughly the middle of the
cabinet's height, with the tan machine clearly visible above and below it.
The kiosk is visually subordinate: the historic machine dominates the frame.

The kiosk's screen is on, showing a portrait exhibit page with large white
text on near-black.

Museum lighting: soft overhead, gentle falloff, a polished concrete or
plain floor. A neutral gallery wall behind. Photorealistic, eye-level camera
at about 6 feet away, slight angle from the left. No people.
```

---

## Notes

**If the model gets the proportion wrong** — and it usually will on the first
try — reply with only this: *"The enclosure must be exactly twice as tall as it
is wide, a precise 1:2 rectangle. Regenerate with that corrected and everything
else unchanged."*

**Finish colour is not decided.** These prompts assume satin black throughout,
which makes the kiosk read as one object. Two alternatives worth rendering
before anyone commits — it is a curatorial call, not an engineering one:

- *Tan body:* replace every "satin black painted solid pine" with **"beige-tan
  painted solid pine, matching the vintage cabinet behind it"**. The box
  disappears into the machine and only the black face and screen read.
- *Natural wood body:* replace it with **"natural pine with a clear satin
  finish, warm and lightly grained"**. Reads as deliberately maker-built.

The face plate stays matte black in all three — that part is ordered.

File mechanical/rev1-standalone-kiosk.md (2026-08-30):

# Rev 1 — Standalone Kiosk

**The kiosk is now its own product.** A self-contained enclosure holding the
display, the Pi, the power and the three buttons — built, wired and bench-tested
on a table, then hung on the front of the 3280's closed factory door by a
mounting adapter designed *later*, as a separate subsystem.

The 3280 is not modified. It is not opened. It is not part of the build.

> **Interactive design study:** [`rev1-design-study.html`](rev1-design-study.html)
> — front elevation with a live size switcher, kiosk front view, side section,
> and the comparison tables below.

**Recommendation up front: 24″-class display (23.8″ actual), finished kiosk
15″ W × 30″ H × 3-5/8″ D, ≈ 23.8 lb.**

> ⚠️ **Superseded numbers below.** This study sized the kiosk at 15-3/8 ×
> 28-11/16 × 3-1/4 on a ½″ Baltic birch box. The envelope has since been rounded
> to a whole **15 × 30** on a solid-pine box with a tacked MDF back, and the
> window re-derived to lap over the picture. The reasoning here still holds; the
> live dimensions are in [`fab-rev1/_p1.py`](fab-rev1/_p1.py), which every other
> artifact is generated from.

**Placement: buttons at 38″ AFF — and the buttons are the datum.** ADA reach sets
the button height; the button height sets where the kiosk sits; everything else
follows. Kiosk bottom **34″**, top **64″**, 7.15″ of headroom under the door.
See §5.

---

## 1. Why the pivot

Everything in `mechanical/` before this document designed a **replacement door**:
our panel hung on the 3280's original hinges, sized to the cabinet aperture,
gated on an unmeasured closing clearance (C1).

That design has four problems Rev 1 doesn't:

| Integrated door | Standalone kiosk |
|---|---|
| Can't be tested until it's on the machine | Bench-testable start to finish |
| Blocked on C1, still unmeasured | C1 is irrelevant |
| Reuses original hinges — load on an artifact | Load path is a designed, reversible adapter |
| Failure means the machine has no door | Failure means a box comes off the wall |

The old work is not wrong and is not deleted. It is **superseded for Rev 1** and
is a live candidate for Rev 2.

## 2. What Rev 1 keeps from the measured work

Only the **external** dimensions matter now:

| | | Provenance |
|---|---|---|
| Cabinet overall | 71″ H × 24″ W × 34″ D | OEM 50-045R00 |
| Cabinet box, less feet | 67-7/8″ | measured, ME-1 |
| Feet | 3-1/8″ | derived (71 − 67.875) |
| Outer door | ≈ 24.3″ W × 68.2″ H, ≈ 3″–71″ AFF | 3230 drawing + derived |
| Factory paint | P.E. #464 textured | 3230 drawing |

**Everything internal is out of scope** — the aperture, the inner perforated
panel, the card cage, the rack rails, C1. The kiosk sits on a flat ≈24″-wide
door face and never learns what's behind it.

**The kiosk should not be 24.3″ wide.** It is an interpretation device added to a
historic machine, and it should read that way. Subordinate, not flush.

---

## 3. Monitor size study

16:9, run portrait. Nominal sizes are marketing; the table uses **actual**
diagonals (a "24-inch" panel is 23.8″).

Bezel allowance: +0.35″ on three sides, +0.85″ chin — typical of a current thin-
bezel monitor. Face-plate reveal: 1.25″ all round. Button band: 0.75″ gap +
4.00″ band + 1.25″ bottom border.

### Screen geometry

| | **22″** | **24″** ✅ | **27″** | **32″** |
|---|---|---|---|---|
| Actual diagonal | 21.5″ | **23.8″** | 27.0″ | 31.5″ |
| Landscape active | 18.74 × 10.54 | **20.74 × 11.67** | 23.53 × 13.24 | 27.45 × 15.44 |
| Portrait active (W × H) | 10.54 × 18.74 | **11.67 × 20.74** | 13.24 × 23.53 | 15.44 × 27.45 |
| Portrait outline, cased | 11.74 × 19.44 | **12.87 × 21.44** | 14.44 × 24.23 | 16.64 × 28.15 |

### Resulting kiosk

| | **22″** | **24″** ✅ | **27″** | **32″** |
|---|---|---|---|---|
| Finished kiosk W × H | 14.24 × 26.69 | **15.37 × 28.69** | 16.94 × 31.48 | 19.14 × 35.40 |
| Share of 24.3″ door width | 59% | **63%** | 70% | 79% |
| Share of 71″ cabinet height | 38% | **40%** | 44% | 50% |
| Kiosk top, buttons at 38″ AFF | 61.4″ | **63.4″** | 66.2″ | 70.2″ |
| Headroom under the 71.15″ door top | 9.71″ | **7.71″** | 4.92″ | **1.00″** |
| Highest button the geometry allows | 47.7″ | **45.7″** | 42.9″ | **39.0″** |
| Screen centre | 50.5″ AFF | **51.5″ AFF** | 52.9″ AFF | 54.8″ AFF |
| Est. total weight | ~20 lb | **~23 lb** | ~27 lb | ~34 lb |
| Min. enclosure depth | 2.7″ | **2.9″** | 3.1″ | 3.4″ |
| Pixel density (1080 px across) | 102 ppi | **93 ppi** | 82 ppi | 70 ppi |
| Panel tech at this size | IPS | **IPS** | IPS | **often VA** |

**No size has a hard geometric problem.** With the buttons at a properly-chosen
38″ (§5) all four fit the door. What separates them is how much placement freedom
each one leaves: the 22″ and 24″ can put the buttons anywhere in the comfortable
34–44″ band, the 27″ loses the top inch of it, and the **32″ loses half of it**
and keeps only an inch of headroom — inside normal build tolerance.

*Earlier drafts of this study called the 32″ a geometric failure. That was an
artefact of an arbitrary 40″ button height, not a property of the machine.*

### Readability check

The governing constraint is cap height, not resolution. Comfortable reading at
6 ft wants roughly **0.35″ cap height** — about a 0.5″ em.

On the 24″ (20.74″ tall across 1920 px) that's a **46 px** body size, giving
~47 characters per line at 1080 px wide. That is a good measure for the 3–5
bullets the content bar allows. The 22″ lands at ~42 characters — workable, but
it starts to constrain the writing.

**Resolution is not a differentiator.** All four are legible at 3–6 ft; a 1080p
24″ at 93 ppi is crisp at arm's length and dead sharp at exhibit distance. Don't
pay for 1440p unless it's what the salvage pile offers.

---

## 4. Recommendation — 24″

**Proportion is the deciding argument.** At 15.4″ wide the kiosk is 63% of the
door — clearly an added object, clearly not trying to be the machine. The 27″ at
70% and the 32″ at 79% start to read as a monitor wearing a cabinet, which is
exactly the impression a museum exhibit should not give.

**Weight is the second argument, and it may be the more important one.** The
mounting adapter is undesigned and unconstrained. It has to carry the kiosk off
a hollow sheet-metal door **without a single fastener into the artifact**.
23 lb of strap-and-bracket load is a solvable problem. 34 lb is where you start
having to transfer load to the cabinet frame, and the mount stops being simple.

**Availability.** 24″ 1080p IPS is the highest-volume monitor ever made. It's
the most likely thing in the warehouse, the cheapest thing to buy, and the
easiest thing for a docent to replace in 2033 without calling anyone.

**Depth.** 2.9″ minimum vs. 3.1″ for the 27″ — small, but it compounds with the
mount, and every eighth of an inch the kiosk stands off the machine is visible.

### If a 27″ falls out of the salvage pile

Take it. It is not a bad answer — it's a *slightly worse* answer, and the
enclosure design is parametric enough that switching costs one face plate. The
27″ upgrades the screen centre to a slightly better 54.9″ and buys real estate
for images. Just budget the extra 4 lb into the mount.

**22″ is the fallback if the mount turns out to be harder than expected.**
20 lb is genuinely easy to hang.

**32″ is out — but not on geometry.** It fits with an inch to spare. It goes on
weight (~34 lb against a mount that has no fasteners into the artifact), on
proportion (79% of the door), on the VA-panel risk — visitors approach an exhibit
from the side, and a VA panel at 45° looks bad in exactly that situation — and on
the placement freedom it costs.

### Two go/no-go criteria carried over

1. **It must power itself back on after a mains cut.** The exhibit is on an AC
   timer (EL-4). Many monitors return to standby and need a button press —
   that's a black screen every morning. Test before committing: switched strip,
   kill power, restore, confirm it comes back with no input.
2. **Matte only.** Overhead lights and daylight; glossy panels mirror them.

---

## 5. Button placement — ADA drives the geometry

Three controls, no touchscreen: **BACK · HOME · NEXT**. They are the **datum**:
where a visitor's hand goes decides where the kiosk sits, and everything above it
follows.

### The rule

**ADA 2010 §308 puts operable parts between 15″ and 48″ above the finished
floor.** Unobstructed forward reach and unobstructed side reach give the same 48″
maximum, so the approach doesn't change the number. The 3280's face is flat and
floor-standing with no knee clearance underneath, so a visitor in a wheelchair
makes a parallel approach and reaches sideways — still 48″.

| Provision | Requirement | Where it lands here |
|---|---|---|
| §308.2.1 / §308.3.1 unobstructed reach | 15″ min, 48″ max AFF | Sets the legal window for the button centreline |
| §309.4 operable parts | one hand; no tight grasping, pinching or twisting; **≤ 5 lbf** | A 30 mm anti-vandal momentary switch is typically well under 1 lbf — **check the actuation force on the spec sheet**, some heavy industrial switches are stiff |
| §305 clear floor space | 30″ × 48″ at the control | **A museum floor requirement, not an enclosure one.** Confirm the approach is kept clear when the exhibit is sited |
| §307.2 protruding objects | leading edge above 27″ → **4″ max** projection | Constrains the mount — see below |

**48″ is a ceiling, not a target.** Designing at the maximum satisfies the letter
of the standard and serves tall standing adults. It fails seated visitors and
children, who are the people the reach range exists for.

### Rev 1 target — 38″ AFF

- **10″ below the ADA maximum.** That margin absorbs mount tolerance, floor
  variation, and the fact that nobody has built this yet.
- **At or just above elbow height for a shorter standing adult**, and a natural
  reach-down for a taller one.
- **Comfortably inside a seated visitor's reach**, and reachable by a child of
  about eight.

**It improves the screen, too.** Buttons at 38″ put the 24″ screen centre at
**51.5″**. Adult seated eye height is roughly 47–51″, so the screen is very nearly
centred on a seated visitor, while a standing adult looks down about 11° — normal
reading posture. *The ADA-driven placement is better for everyone than the 40″
this study first drew.*

### The placement math

The button centreline sits **3.25″** above the bottom of the enclosure
(1.25″ bottom border + half the 4.00″ band), and the door face runs from about
3″ to **71.15″** AFF. For a button height `B` and a kiosk height `KH`:

```
kiosk bottom = B − 3.25″
kiosk top    = B + KH − 3.25″  ≤  71.15″
             →  B ≤ 74.40″ − KH
```

| | **22″** | **24″** ✅ | **27″** | **32″** |
|---|---|---|---|---|
| Kiosk height | 26.69″ | **28.69″** | 31.48″ | 35.40″ |
| Highest button the geometry allows | 47.7″ | **45.7″** | 42.9″ | 39.0″ |
| Legal button window | 15–47.7″ | **15–45.7″** | 15–42.9″ | 15–39.0″ |
| Of the 34–44″ comfort band | all | **all** | 34–42.9″ | **34–39.0″** |
| Headroom at 38″ buttons | 9.71″ | **7.71″** | 4.92″ | **1.00″** |

### ⚠ What it costs the mount

With the buttons at 38″ the kiosk's bottom edge sits at **34.75″ AFF** — above
the 27″ threshold — so **§307.2 caps the projection into a circulation path at
4″**. With the recommended 3 mm ACM face (§7) the enclosure is 3.25″ deep,
**leaving 0.75″ for the mounting adapter** — a plywood face instead would cut
that to 0.5″.

**Worth asking, not worth assuming.** §307.2 exists to stop someone with a cane
walking into an object their sweep misses. The 3280 is floor-standing and
cane-detectable, and a visitor is stopped by the cabinet before the kiosk is in
reach — so the hazard the rule targets may not apply here. **That is the museum's
accessibility coordinator's call, not ours.** Design the adapter to 4″ total, and
ask.

### Hardware and layout

```
        ┌──────────── 15.37" ────────────┐
        │                                │
        │   ( BACK )  ( HOME )  ( NEXT ) │  ← 4.00" band
        │      └────3.50"────┘           │
        └────────────────────────────────┘
                 centreline 38" AFF
```

| Decision | Call | Why |
|---|---|---|
| Switch | 30 mm anti-vandal stainless, momentary, 30.5 mm hole | Big public target, industrial durability, ~$10, standard hole means any replacement fits. **Verify ≤ 5 lbf** per §309.4 |
| Spacing | 3.50″ centre-to-centre, 7.18″ overall span | Room for a legible engraved label under each; far enough apart that a mis-press is a mis-press, not a fat finger |
| Height | Centreline **38″ AFF** | See above |
| Location | **Cut straight into the face plate**, below the monitor | ↓ |
| Surface | Flat, in the plane of the face — **not** angled | ↓ |
| Labels | Engraved / cut into the plate, not stickers | Stickers peel; this is a 10-year exhibit |

**Consider making the three tactilely distinguishable** — different cap shapes, or
a tactile mark on HOME. Not required by §309, but it costs nothing at purchase
time and it helps visitors with low vision far more than a label does.

**Why they're in the face plate, not on their own plate.** An earlier version put
them on a separate plate behind an aperture, as insurance against getting the
switch cutout wrong. **That was over-engineered.**

*Stiffness was the real cost.* Cutting both a 12.17 × 21.24 window **and** an
11.87 × 3.00 aperture out of one 3 mm sheet left a **1.35″ web** as the only
material joining the side rails below the screen. One piece leaves **2.25″ above
the buttons and 2.65″ below**. It also meant a second part on the invoice, six
more holes, a second set of cleats, and a plate to align square in an aperture.

*And the wear argument didn't hold.* Anti-vandal switches are rated for millions
of cycles, and when one fails you replace **the switch**, through the same hole.
The plate only needs replacing if the hole itself is damaged, which essentially
doesn't happen.

The insurance is better bought by **confirming the cutout before ordering** than
by designing around not knowing it.

**A cleat row sits between the window and the buttons** — three fixings onto a
plywood rail, so the panel takes the press load instead of flexing every time
somebody pushes a button. It clears the switch bodies, which stand about an inch
proud behind the plate.

**Why not angled.** An angled lower surface adds a bevelled joint, adds depth at
the bottom of the enclosure, and complicates the mount's load path. At 38″ AFF a
flat vertical face is comfortable for a standing adult. Note it as a Rev 2
option if observation says otherwise.

**No visible fasteners on the front.** The face plate is captured from behind.
Nothing on the visitor-facing surface is a screw a bored twelve-year-old can
turn.

## 6. Enclosure depth

**Target: 3.25″ with the recommended 3 mm ACM face (§7). Floor: 3.0″.
2.5″ is not realistic.** A plywood face instead makes it 3.5″.

Side-section stack, front to back:

```
  0.118"  face plate — 3 mm ACM on internal cleats
  0.10"   bezel clearance
  1.80"   monitor body at its thickest (VESA boss / driver hump)
  0.73"   air + service gap
  0.50"   rear panel
 ───────
  3.25"   finished depth      (3.50" if the face is 1/2" plywood)
```

### What actually forces the depth

1. **The monitor's thickest point — 1.6″ to 2.3″.** Non-negotiable, and the only
   real number in the stack. This is why the enclosure gets deeper with screen
   size even though the panel itself doesn't.
2. **Cable bend at the monitor's connectors — 0.75″ to 1.75″.** This is the one
   you can design away, and it's the difference between 3.5″ and 4.5″. Route the
   HDMI and DC leads **downward into the button bay** instead of straight back,
   and use right-angle plugs. The button bay has 4″ of free depth in a 5″-tall
   band and nothing in it but the Pi.
3. **Face plate + rear panel.** A 3 mm ACM face and a 1/2″ ply rear come to 0.62″
   together; a plywood face makes it 1.0″ — **and that 3/8″ comes straight out of
   the mounting adapter's budget.**
4. **The mounting adapter**, TBD, adds to the *stand-off*, not the enclosure.

### What does NOT force the depth

**The Raspberry Pi.** A Pi 4 is 0.65″ tall. It does not live behind the monitor —
it lives in the button bay below it, on a slide-out tray, where there is 4″ of
depth doing nothing. Anyone who designs this enclosure around fitting a Pi behind
the panel will build it an inch too deep.

**The monitor stays cased.** De-casing buys ~1.2″ of depth and costs the panel's
EMI shielding, its thermal design, its warranty, its power board's enclosure, and
any hope of a volunteer replacing it. Not worth it. This reverses the earlier
de-cased-panel route in [`door-construction.md`](door-construction.md).

| Depth | Verdict |
|---|---|
| 2.5″ | **No.** Requires a sub-1.4″ monitor, a 1/8″ face, and zero service gap. |
| 3.0″ | Achievable at 22–24″ with a slim monitor, right-angle cables, down-routing. No margin. |
| **3.25″** | **The design target**, with a 3 mm ACM face. Works at 22/24/27 with 0.7″ of service air, and leaves **0.75″ for the mount** under the 4″ cap. |
| 3.5″ | What a plywood face costs you. Still fine — the mount's budget drops to 0.5″. |
| 4.0″ | Needed for 32″, or any monitor with a rear-facing connector cluster and straight cables. **Leaves nothing for the mount.** |

---

## 7. What it's made of, and where to buy it

### First — what these materials actually are

| | | |
|---|---|---|
| **ACM** | *aluminium composite · "Dibond"* | Two thin sheets of aluminium glued either side of a plastic core — a metal sandwich about **1/8″ thick**. Stiff, dead flat, colour baked on at the factory. **Nothing to sand, nothing to paint.** Every storefront and road sign is this stuff. |
| **HPL** | *high-pressure laminate · "Formica"* | The material on a kitchen counter. **It is not a board** — it's a 1/32″ skin with no stiffness of its own, so it has to be glued onto plywood or MDF first. That is the word "bonded" doing a lot of quiet work. |
| **Compact laminate** | *solid phenolic · Trespa, Fundermax* | The same material as Formica, pressed thick enough to stand on its own (1/4″–1/2″). Restroom partitions, lab benches. Beautiful and permanent, but heavy and sold in architectural quantities. |
| **Baltic birch** | *void-free plywood* | Very good plywood — many thin layers, no hidden gaps. Machines beautifully. But it's wood: to look finished it wants sanding, sealing and spraying, and **that is where volunteer builds come unstuck.** |

### The three routes

| | **A — Plywood, cut and sprayed** | **B — Plywood box, ACM front** ✅ | **C — Modify a bought enclosure** |
|---|---|---|---|
| What you do | CNC-cut 1/2″ Baltic birch, rabbet corners, spray satin graphite | Same plywood box, but the **visible front is 3 mm black ACM**, cut to shape, screwed to internal cleats | Buy a signage or instrument housing and cut it for the panel |
| The hard part | **The finish.** Ply edges telegraph; a brushed coat reads homemade from ten feet | **There isn't one.** The face arrives already finished | **Nothing off the shelf is 15″ × 29″ × 3-1/4″ portrait** |
| Needs | CNC access *and* somewhere to spray | Ordinary woodworking — the front is cut by someone else | Luck |
| Material | ~$80–140 | ~$120–200 | $150–400 |
| Weight | ~13 lb enclosure | **~12 lb** — ACM is lighter than the ply front it replaces | 30 lb+ in steel |

**Recommend B.** The single biggest risk in a volunteer-built enclosure is the
**finish**, and B removes it from the critical path entirely: the visible surface
arrives flat and durable, and the crew builds a plywood box behind it — a thing
any woodworker gets right on the first try.

### The move that actually makes this easy — don't buy a sheet, send the file

**[SendCutSend](https://sendcutsend.com/materials/acm/) will CNC-route the face
plate out of 3 mm matte black ACM and mail it to you.** Upload the drawing file,
they cut to **±0.005″**, ships in 2–4 days. Maximum part is **30″ × 44″** — our
face plate is 15.4 × 28.7, well inside.

This takes the hardest job away from the volunteer crew: **no CNC access needed
at CDL, no 4 × 8 sheet to buy and mostly throw away, no jig for the screen
window, and the three button holes arrive cut to size.**

### One small thing that decides the material

Panel-mount buttons have a **maximum panel thickness** — model-specific, commonly
6–11 mm. **3 mm ACM clears every one of them.** A 1/2″ plywood-and-Formica face
is 12.7 mm, at or over the limit for most switches, meaning counterboring the
back of all three holes by hand.

**Two limits on ACM worth knowing:** it can't be tapped or bent, so fastening goes
through clearance holes into threaded inserts in the plywood cleats (already the
plan); and cut edges show the black plastic core — invisible on black, a visible
dark line on white, so order it **black both sides**.

### Shopping list

| Part | What to order | Where | Rough cost |
|---|---|---|---|
| Face plate | 3 mm ACM, **matte black both sides**, one piece with the button holes cut in | [SendCutSend](https://sendcutsend.com/materials/acm/) | quote on upload, qty 1 |
| Box — sides, top, bottom, rear | 1/2″ Baltic birch, ~8 sq ft | [MakerStock](https://makerstock.com/collections/baltic-birch-plywood) · [Cherokee](https://www.cherokeewood.com/store/1-2-baltic-birch-plywood-cut-to-size/) · [Jeff Mack](https://jeffmacksupply.com/en-us/products/1-2-thick-baltic-birch-select-a-size) | $40–90 |
| Buttons × 3 | 30 mm anti-vandal, momentary, stainless. **Check the datasheet for panel range including 3 mm and actuation force ≤ 5 lbf** (§309.4) | [APEM AV](https://www.apem.com/panel-switches/pushbutton-switches/av-anti-vandal-pushbutton-switches) · [RJS](https://www.rjselectronics.com/category/panel-mount/pushbutton-metal-switches/metal-pushbutton-switches-anti-vandal/) · [Adafruit](https://www.adafruit.com/category/235) | $25–40 |
| Threaded inserts | #8 for plywood, ×15 — **never screw into a plywood edge** | McMaster-Carr | ~$12 |
| Rear-panel fasteners | Quarter-turn or captive thumbscrews, ×6 | McMaster-Carr | $20–30 |

**Other ACM sources:** [Curbell Plastics](https://www.curbellplastics.com/product-category/material/aluminum-composite-material-acm/dibond-panels/) ·
[OnlineMetals](https://www.onlinemetals.com/en/buy/3mm-aluminum-composite-panel-black/pid/mp-00040256) ·
[Midwest Airbrush](https://www.midwestairbrush.com/collections/acm-aluminum-panels-black) (small pieces).
**HPL:** [Wilsonart vertical grade, black matte](https://www.amazon.com/Wilsonart-Sheet-Laminate-Vertical-Grade/dp/B01FV20Z6A) ·
[Ledgeband](https://ledgeband.com/collections/laminate-sheets).
**Compact:** [Fundermax](https://fundermax.us/product/interior-thin-laminate-panels/) ·
[Wilsonart Compact](https://www.wilsonart.com/laminate/specialty-laminate/compact).

Costs are estimates — confirm at the link. Curbell and OnlineMetals block
automated requests; they load fine in a browser.

### ✅ The cut files exist — [`../fab-rev1/`](../fab-rev1/)

**One part.** `P1-face-plate.dxf` — 15.37 × 28.69″, screen window 12.17 × 21.24,
three ⌀30.5 mm button holes at 3.50″ centres, fifteen ⌀0.1875 mounting holes.

Upload it, pick **ACM → 0.118″ (3 mm) → matte black**, quantity **1**. No
secondary services. Full ordering notes in
[`../fab-rev1/README.md`](../fab-rev1/README.md).

**The window is 0.25″ oversize per side on purpose** — "24 inch" covers
23.6″–24.0″ diagonals and this clears all of them without cropping, with the
margin falling on the monitor's own black bezel. The monitor is aligned *to the
window* on an internal VESA frame, which is why P1 is safe to cut before the
monitor arrives.

**⚠ Confirm ⌀30.5 mm against your switch's datasheet before ordering.** It's the
only dimension here tied to a part nobody owns yet, and since this is now a
one-piece part, getting it wrong means recutting the whole face.

## 8. Serviceability

Everything must be replaceable by a museum volunteer with a screwdriver.

| Part | How it comes out |
|---|---|
| **Rear panel** | Captive thumbscrews or 1/4-turn fasteners into threaded inserts. No loose hardware to drop inside a museum artifact. |
| **Monitor** | On a VESA 100 plate bolted to the internal frame. Rear panel off → four bolts → monitor out backwards. **The face plate never comes off.** |
| **Raspberry Pi** | Slide-out tray in the button bay. Unplug two, slide out. |
| **Buttons** | Button plate is captured from behind. Rear panel off → plate drops in. Switches are standard 30.5 mm hole. |
| **Power** | One appliance inlet at the bottom rear. One cord leaves the kiosk. |

**The rule:** nothing that fails routinely should require touching the face plate
or the mount. The kiosk should never have to come off the 3280 for service.

---

## 9. Attachment interface — deliberately not designed

The rear of the enclosure carries a flat, unobstructed **mounting interface
zone**, marked on the drawings as:

> **REVERSIBLE 3280 MOUNTING ADAPTER — DESIGN TBD**

Constraints it will have to satisfy, recorded now so the enclosure doesn't
foreclose them:

- **Reversible, non-destructive, removable, visually discreet** (MR2). No holes,
  no cuts, no permanent modification to the door or the cabinet.
- Must carry ~23 lb in shear plus the moment from a ~1.75″ centre-of-mass
  stand-off, with a safety factor for someone leaning on it.
- **Total projection from the door face should be ≤ 4″** (ADA §307.2 — the kiosk's
  leading edge is at 34.75″ AFF, above the 27″ threshold). With the recommended
  3 mm ACM face the enclosure is 3.25″, so **the adapter's budget is 0.75″**. See §5 — whether the rule binds here is a
  question for the museum's accessibility coordinator, but design to it and ask.
- Candidates, unevaluated: edge brackets hooking the door's return flange;
  compression straps around the cabinet; a full-door backing plate captured at
  top and bottom; clamps on the door's existing hardware.
- Anything that loads the original **hinges** needs to be checked against them.

**Deliberately deferred.** The enclosure's job is to have a flat back and a known
weight. That is enough for the adapter to be designed against later, and
designing it now would be guessing.

---

## 10. Sequence

1. **Choose the monitor** — buy or salvage, run the power-cut test. ← *gate*
2. **Build the enclosure** — bench, no 3280 involved.
3. **Install** monitor, Pi, buttons, wiring, software.
4. **Bench-test as a complete kiosk** — run it for a week on a table.
5. **Then** design and build the reversible mounting adapter.
6. **Rev 2**, if desired, revisits the replacement-door concept.

Steps 1–4 have no dependency on the 3280 at all. **C1 no longer gates anything**,
and neither does the door height, the aperture, or the inner panel.

---

*Recorded 2026-08-28. Supersedes for Rev 1: the 27″ call in
[`monitor-selection.md`](monitor-selection.md), the hinged-carrier route in
[`display-approach-options.md`](display-approach-options.md), the de-cased-panel
route in [`door-construction.md`](door-construction.md) and [`fab/`](fab/), and
drawings 01–06 in [`drawings/`](drawings/). Those describe the Rev 2 concept.*

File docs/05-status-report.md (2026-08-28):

# 3280 Kiosk — Project Status Report

**As of 2026-08-28** · repo [nickdnj/3280-kiosk](https://github.com/nickdnj/3280-kiosk)
· written as a **handoff for a team joining in parallel**

> ## ▲ Rev 1 pivot — 2026-08-28
> **The mechanical design changed after this report was written.** The kiosk is
> no longer a replacement door integrated into the cabinet; it is a
> **self-contained enclosure surface-mounted on the closed factory door**, built
> and bench-tested standalone, with the reversible mount deferred to its own
> subsystem. Read
> [`../mechanical/rev1-standalone-kiosk.md`](../mechanical/rev1-standalone-kiosk.md)
> **before** acting on anything mechanical below.
>
> What this changes: **C1 no longer gates anything.** The 27″ recommendation
> becomes **24″**. The aperture, inner panel and hinge reuse are all out of scope.
> Everything below about the software track, the measured external dimensions,
> the provenance levels and the traps is unaffected.

---

## 0. Read this first

An interactive exhibit kiosk built into the Vintage Computer Federation's
**Concurrent 3280** minicomputer. A portrait screen where the machine's door is,
driven by **three physical buttons — BACK / HOME / NEXT. No touchscreen.**

**Phase:** planning complete, execution barely started. 39 GitHub issues, **0
closed**. One site visit done.

**The single most important thing to know:** the machine is **not** what the
concept art shows. Roughly half the mechanical documentation in this repo was
written before we measured it and is **superseded**. §6 tells you exactly which
files to ignore. Read that before you read anything else in `mechanical/`.

**Everything mechanical is blocked on one unmeasured dimension** (§5). Everything
in the **software track is unblocked, untouched, and safe to work in parallel**
(§8).

---

## 1. The product

A docent or visitor steps through a short deck of screens telling the machine's
story. Swing the display open and the real hardware is behind it.

| | |
|---|---|
| Interaction | 3 buttons only. No touch, no keyboard, no network dependence |
| Display | Portrait, ~27″ |
| Compute | Raspberry Pi 4, Chromium kiosk, offline in production |
| Content bar | ~30% of web copy, 3–5 bullets/screen, big sans-serif, readable at 3–6 ft, verified facts only |
| Hard constraint | The 3280 is a **museum artifact** — all mounting reversible, non-destructive |
| Success | Ownership transfers to the museum. "Nick-in-the-loop forever" = failure |

Docent review (Rick Lewis) set the content bar and approved the concept:
*"YES YES YES. This is just the job."* That approval was against art that has
since turned out to misrepresent the machine — see §7.

---

## 2. What we know about the machine

**Provenance matters here.** Four different confidence levels:

### Measured — tape on the machine, 2026-08-26

| Dimension | Value | Confidence |
|---|---|---|
| Cabinet **box** height (excl. feet) | **67-7/8″** | Good |
| Front opening, clear width | **~19.75″** (19.5–20) | Good |
| Outer door width | ~23–24″ | Poor — couldn't see both tape ends |
| Two vertical runs | ~48″ and ~32″ | Readings clear, **what they span is unknown** |

### OEM — Concurrent *3280/Micro3200 Product Overview*, 50-045R00, Aug 1989, pp.73–74

| | |
|---|---|
| Cabinet | **71″ H × 24″ W × 34″ D**, ≈5.7 ft² |
| Internal stack | power → fan → CPU + 18 S-bus slots → intermediate duct → I/O chassis → fan |

Height reconciles exactly: **67-7/8″ box + 3-1/8″ feet = 71″**. A 1989 catalogue
and a warehouse tape agreeing to an eighth is strong mutual confirmation.

### Sibling model — Perkin-Elmer 3230 *Installation & Maintenance*, 47-004 R21, 1982, ch.3

The 3230 is a 56″ rack, not our 71″ cabinet — **family evidence, not gospel.**

| | |
|---|---|
| **19″ EIA rack** | Panel space 1292 mm (50.87″) × **482.6 mm (19.00″)**; 28″ upright-to-upright |
| Door | Part **13.045 F01**, 54.32″ × 24.3″, two spring latches at top, foam gasket, vertical louvers |
| **Paint** | **P.E. #464 TEXTURED** — factory spec. Texture matters as much as hue |
| Materials | CRS .104″ structure, .047″ skins |
| Cooling | Bottom blower 450 CFM, right-side plenum, five removable covers (solid / perforated) |

### Derived — from a uniform frame offset (working assumption, 2026-08-27)

```
frame offset = (24.00 − 19.75)/2 = 2.125"  uniform on all four sides
aperture     = 19.75" × 63.625"    (5.25" – 68.88" AFF)
door         = 24.30" × 68.175"    (2.98" AFF), 0.15" overhang all round
```

Self-consistent: door height 68.175″ = box 67.875″ + 2 × 0.15″, *the same
overhang the door has in width*. Two independently sourced numbers agreeing.

### Not known

- **C1 — the closing clearance.** See §5. This is the blocker.
- What the 48″ and 32″ readings measure
- Hinge type and spacing; latch mechanism
- Whether rack rails are present with a free run
- Floor → aperture bottom, confirmed rather than derived

---

## 3. The finding that changed the project

**The 3280 has two doors. There is no open card cage.**

- **Outer:** tan **louvered** door, hinged, dark trim strip, "SYSTEM #1" label
- **Inner:** **perforated zinc-plated steel** panel on a piano hinge
- **Behind:** the card cage, with Concurrent power-supply modules down one side

Every drawing produced before the site visit shows an **open front opening with a
visible card cage** and a fixed frame spanning it. **That geometry does not
exist** — the AI concept render invented it.

Consequences:

- **Mounting is solved.** Remove the outer door, store it, hang the kiosk panel
  on its hinges. More reversible than clamping rails or gripping a frame lip,
  because a cover door is *built* to come off. ME-2 and ME-3 (reversible mount,
  fixed frame) largely collapse.
- **Exposed-board risk is moot.** The boards already sit behind perforated steel.
  ME-10 / the deferred plexiglass is unnecessary.
- **MR3 breaks.** "Viewing area around the display" meant seeing the machine
  around the screen. There's a steel panel there. Partially recovered by a
  **viewing cutout in the lower third** of the door — it's 68″ tall, so there's
  room. **This is a docent decision, not an engineering one.**

---

## 4. The design as it stands

```
Remove the outer louvered door  →  store it
Carrier panel (24.30" × 68.175") hangs on the original hinges
  ├── 27" IPS 1440p matte monitor, cased, portrait, VESA 100×100
  ├── button plate below — 3 buttons + 2 spare blanks, centre 34" AFF
  ├── viewing cutout, lower third
  └── Raspberry Pi 4 behind the monitor
```

Screen centre ≈ **49″ AFF**. Buttons at 34″ AFF sit mid-band in the 15″–48″ ADA
reach range.

### Decisions, including the ones we reversed

| Decision | Reversed from | Why |
|---|---|---|
| **Cased monitor, kept whole** | De-cased bare LCD panel | De-casing is one-way and risks a good panel. A cased monitor is **docent-replaceable**, and its own housing solves the enclosure and thermal requirements |
| **27″** | 24″ | The door is 24.3″ wide, not the 14.5″ we'd assumed. A 24″ portrait panel is 12.5″ — 51% of the door |
| **Replace the existing door** | Fabricate a fixed frame | The machine already has a hinged, removable door of the right size |
| **1 panel or none to fabricate** | 4-part laser-cut aluminium package | Cascade of the above |

**27″ specifically:** IPS is near-mandatory (visitors approach off-axis, and 32″
is often VA); 1440p is 109 PPI and a Pi 4 rotates it comfortably where 4K is
sluggish; ~12 lb on original hinges vs ~17 lb for 32″.

### Two easily-missed selection criteria

1. **The monitor must power itself back on after a mains cut.** The exhibit runs
   on an AC timer. Many monitors wake into standby — that's a black screen every
   morning. **Go/no-go.**
2. **Matte only.** Museum lighting mirrors off glossy panels.

---

## 5. The blocker

**C1 = distance from the outer door plane to the inner perforated panel.**

Required: **≥ 2.48″** (carrier panel 0.125 + monitor body 1.85 + 0.5 clearance).

Not measured. No catalogue carries it. It decides **recessed vs. proud**
mounting — and the proud variant needs almost none, so a bad C1 doesn't kill the
project, it just changes how it looks.

Measure it at top, middle and bottom of the aperture and design to the smallest.

**Also worth one tape each:** the door height (confirms §2's derivation), the
foot height (currently derived), and whether rack rails have a free run.

---

## 6. ⚠️ Repo map — current vs. superseded

**Roughly half of `mechanical/` is obsolete but still present.** Do not build
from the right-hand column.

### Current

| File | What it is |
|---|---|
| `mechanical/me1-findings.md` | **The site visit. Read first.** |
| `mechanical/monitor-selection.md` | Why 27″, with the fit maths |
| `mechanical/cabinet-spec-oem.md` | Concurrent's published cabinet spec |
| `mechanical/cabinet-drawings-3230.md` | Perkin-Elmer mechanical drawings, sibling model |
| `mechanical/drawings/01…07` | Full drawing set, measured geometry |
| `mechanical/drawings/make-drawings.py` | **Generates 01–06 from one geometry block.** Edit params, re-run |
| `mechanical/measurement-checklist.md` | Field sheet; C1 and door height are what's left |
| `mechanical/photos/` | Site photographs |
| `docs/00`–`04` | Brief, PRD, architecture, UX, dev plan — **still broadly valid** |
| `src/kiosk-app/` | Working concept app + builder. **Untouched, valid** |

### Superseded — ignore

| File | Why |
|---|---|
| `mechanical/dimensions-assumed.md` | Pre-measurement guesses. Wrong cabinet, wrong door |
| `mechanical/door-construction.md` | De-cased-panel build spec. Obsolete route |
| `mechanical/fab/` (DXFs, generator, DRAWING-PACKAGE.md) | 4-part laser-cut package for a door we're no longer building |
| `mechanical/enclosure-buy-vs-build.md` | Moot — the cabinet supplies the enclosure |
| `mechanical/display-approach-options.md` | Decision made (Option C). Historical |
| `mechanical/drawings/superseded/` | Pre-measurement drawings |

**Also stale:** the 39 GitHub issues were written against the pre-measurement
plan. **ME-2, ME-3, ME-10 are likely moot; ME-4 changed completely.** Nobody has
reconciled the issue list with §3–§4 yet — *that is itself available work.*

---

## 7. Traps

Things that already cost us time:

1. **The AI concept renders are wrong about the machine.** They show an open card
   cage that doesn't exist, and dimensions off by 1–1.5″. They're flagged as
   concept art throughout, but they drove real design decisions for days.
2. **We designed a 14.5″ door for a 19″ opening** when the actual usable face is
   a 24.3″ door. Everything downstream — monitor size, panel layout, fab package
   — inherited that error.
3. **A measurement can be right and still mislead.** The 67-7/8″ height looked
   like it contradicted the OEM's 71″. It didn't — one was the box, one included
   the feet. Always ask *what* was measured, not just the number.
4. **Sibling-model documentation is not the machine.** The 3230 data is good
   evidence and clearly labelled as such, but it's a 56″ rack, not our 71″ cabinet.

---

## 8. Work available in parallel

The **software track is completely untouched and completely unblocked.** It has
no dependency on the cabinet, the monitor choice, or C1.

### Safe to take — no collision

| Issue | Story |
|---|---|
| #2 SW-A1 | Split the screen deck out of `build-app.py` into a `content.json` data file |
| #3 SW-A2 | Encode the 8-screen deck (UX §4) in that data file |
| #5–8 SW-B | Kiosk runtime: fullscreen/no chrome, key nav, idle→Home reset, "more" scaffolding |
| #12–17 SW-D | Pi OS image: boot-to-kiosk, read-only root, USB content mount, watchdog, golden image |
| #18–19 SW-E | Usage logging + summary |
| #9–11 SW-C | GPIO service, uinput key mapping — needs a Pi and buttons, not the cabinet |

`src/kiosk-app/` is a **real working app** (`build-app.py` emits a self-contained
`index.html`). Content is currently hardcoded in the Python; SW-A1 is the natural
first task and unblocks everything else in the deck.

### Do not take — actively in flight

- `mechanical/` and `mechanical/drawings/` — being reworked as measurements land
- Anything gated on C1
- Reconciling the GitHub issue list is *available* but coordinate first, since
  it touches the same milestones

### Conventions that matter

- **Commit only files you changed** — `git add <paths>`, never `git add -A`
- Docs-first: PRD → architecture → UX → dev plan → issues → build
- No demo fallback: show error states, not demo data
- Everything is labelled **concept** until built and installed
- Authoritative knowledge base is the wiki at `~/Workspaces/wiki/`
  (`projects/concurrent-3280-museum/`); propose changes via wiki-ingest, never
  write it directly

---

## 9. Sources

- Concurrent, *3280 and Micro3200 Families Product Overview*, 50-045R00, Aug 1989 —
  [bitsavers](https://bitsavers.org/pdf/interdata/32bit/3280/50-045R00_3280_ProdOverview_1989.pdf)
- Perkin-Elmer, *Model 3230 Processor Installation and Maintenance Manual*,
  47-004 R21, 1982 —
  [bitsavers](https://bitsavers.org/pdf/interdata/32bit/3230/47-004R21_3230_Maint_1982.pdf)
  ([OCR text](https://archive.org/stream/bitsavers_interdata30Maint1982_46790039/47-004R21_3230_Maint_1982_djvu.txt))
- Datapro, *Concurrent Computer Corporation Supermini Systems*, M11-230-101, Feb 1986 —
  [bitsavers](http://bitsavers.org/pdf/datapro/datapro_reports_70s-90s/Concurrent/M11-230-10_8602_Concurrent_3200.pdf)
- Site photographs, 2026-08-26 — `mechanical/photos/`
- Docent concept review — the shared artifact, updated 2026-08-27

---

*Written 2026-08-28. The machine in the warehouse is the authority; where this
document and the machine disagree, the machine wins.*

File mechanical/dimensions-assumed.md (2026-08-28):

# Assumed Dimensions — v0 (pre-measurement)

> ## ⛔ SUPERSEDED FOR REV 1
> The kiosk is no longer a replacement door integrated into the cabinet. It is a
> **self-contained enclosure surface-mounted on the closed factory door** — see
> [`rev1-standalone-kiosk.md`](rev1-standalone-kiosk.md) and the
> [interactive design study](rev1-design-study.html).
> This document describes the **Rev 2** concept and is kept for provenance.
> Don't build from it.

> ## ⚠️ SUPERSEDED IN PART — see [`me1-findings.md`](me1-findings.md)
> Site visit 2026-08-26 found the cabinet has **two doors (louvered outer +
> perforated inner)**, not the open card-cage opening every drawing here assumes.
> Height reads ≈67-7/8″ (not 69.5″); opening width ≈18.5–19″ (as assumed).
> **The door geometry mostly survives; the thing it mounts to does not.**
>
> **Status: CONCEPT / ASSUMED.** Nothing on this page has been measured. Every
> number is derived from the AI concept render plus standard 19″ rack practice,
> published so the design can be discussed, shopped for, and sanity-checked
> *before* the site visit. **ME-1 replaces this file with measured reality.**
> Do not cut material against these numbers.

**Reads with:** [`measurement-checklist.md`](measurement-checklist.md) ·
[`../docs/01-prd.md`](../docs/01-prd.md) §9 (MR1–MR19) ·
[`../docs/02-architecture.md`](../docs/02-architecture.md) §8

---

## 1. Where these numbers come from

| Source | Confidence | What it gives us |
|---|---|---|
| AI concept render (`kiosk-concept.jpg`) | **Low** — art, not a drawing | Cabinet 23.0″ W × 69.5″ H; door proportions; left hinge |
| EIA-310 19″ rack standard | **High** — if the 3280 is a 19″ rack | Rail spacing 17.75″ clear, hole centers 18.312″, 1U = 1.75″ |
| 24″ 16:9 panel geometry | **High** — arithmetic | Active area 20.92″ × 11.77″ → portrait 11.8″ W × 20.9″ H |
| Component depths (Pi 4, LCD, arcade buttons) | **Medium** — datasheet typicals | 2.5″ door depth budget |

The render's own two callouts (23.0″ × 69.5″) are the only "dimensions" we have,
and the render is not orthographic — its horizontal and vertical scales disagree
by ~40%. **Treat 23.0 × 69.5 as a claim to verify, not a measurement.**

---

## 2. Drawings

| | Drawing | What it settles |
|---|---|---|
| 01 | [Cabinet front elevation](drawings/01-front-elevation.svg) | Door size and where it sits; ADA button height |
| 02 | [Door front layout](drawings/02-carrier-panel.svg) | Every face dimension of the door; weight budget |
| 03 | [Plan section — swing & clearance](drawings/03-plan-section.svg) | Depth budget; **the C1 clearance risk**; swing envelope |
| 04 | [Reversible mount candidates](drawings/04-door-replacement.svg) | Three no-drill options and what to check for each |
| 05 | [Door assembly — exploded](drawings/05-assembly-stack.svg) | The build stack, depth budget, thermal path — see [`door-construction.md`](door-construction.md) |

Cabinet front elevation

---

## 3. The assumed dimension set

### Cabinet

| Ref | Dimension | Assumed | Basis |
|---|---|---|---|
| A1 | Overall width | **23.0″** | Render callout |
| A2 | Overall height incl. feet | **69.5″** | Render callout |
| A3 | Overall depth | **26″–36″** | Typical 19″ rack cabinet — **wide open, must measure** |
| A4 | Top cap height | 4.5″ | Proportion estimate |
| A5 | Plinth + feet height | 8.0″ | Proportion estimate |
| A6 | Front opening, clear width | **19.0″** | 23.0″ less ~2.0″ frame each side |
| A7 | Front opening, clear height | **57.0″** | 69.5 − 4.5 (cap) − 8.0 (plinth/feet) |
| A8 | Opening bottom, AFF | **8.0″** | = A5 |
| A9 | Opening top, AFF | **65.0″** | = A8 + A7 |

### Display (24″ target — MR12)

| Ref | Dimension | Assumed |
|---|---|---|
| D1 | Panel class | 24″ 16:9, run portrait |
| D2 | Active area | **11.77″ W × 20.92″ H** (1080 × 1920) |
| D3 | Panel outline (glass + backlight frame) | ~12.4″ × 21.6″ — **measure the real panel** |
| D4 | Panel thickness, de-cased | ~0.6″ (edge-lit LED) |

*27″ stretch option:* active 13.24″ × 23.53″, door grows to ~15.9″ × 32.7″.
Only viable if the measured clear opening is **≥ 21″**. At 19″ it leaves 1.5″ of
viewing window each side, which loses the concept's "window around the screen".

### Door

| Ref | Dimension | Assumed | Note |
|---|---|---|---|
| B1 | Door overall | **14.5″ W × 30.0″ H** | Derived from D2 outward |
| B2 | Black bezel block | 12.8″ × 21.9″ | 0.5″ reveal around active |
| B3 | Tan face margin, sides | 0.85″ each | |
| B4 | Badge band (top) | 2.0″ | "CONCURRENT" |
| B5 | Reveal below screen | 0.6″ | |
| B6 | Button plate | 12.8″ W × 4.0″ H | 3 buttons @ 3.2″ c-c + 2 spare blanks |
| B7 | Bottom rail | 1.5″ | |
| B8 | **Door depth, bezel face → rear shroud** | **≤ 2.5″** (stretch 2.0″) | See §5 |
| B9 | Door weight | **~14.5 lb** | ~100 in-lb at the hinge — see [`door-construction.md`](door-construction.md) §7 |

### Placement

| Ref | Dimension | Assumed | Why |
|---|---|---|---|
| P1 | Door bottom, AFF | **26.0″** | Upper-middle per ME-3 |
| P2 | Door top, AFF | 56.0″ | = P1 + B1 |
| P3 | **Button plate center, AFF** | **29.5″** | |
| P4 | Screen active center, AFF | ~43″ | Comfortable standing/seated compromise |
| P5 | Viewing window below door | 18.0″ | Card cage stays visible — the good part |
| P6 | Viewing window above door | 9.0″ | |

---

## 4. What this already resolves

**PRD open question 4 — "does the door-mounted button plate meet ADA reach, or do
we need a separate low plate?"**

Under these assumptions: **yes, comfortably, and no low plate is needed.**

The door can sit anywhere from `door bottom = 21.5″ AFF` (vertically centered in
the opening) to `35.0″ AFF` (flush with the opening top) and still put the button
plate center between **25.0″ and 38.5″ AFF** — the whole range fits inside the
15″–48″ ADA reach band with ≥ 9″ of margin at either end. At the recommended
26.0″ door bottom the buttons land at 29.5″ AFF, near the middle of the band.

This holds as long as A5 (plinth + feet ≈ 8″) and B1 (door ≈ 30″ tall) survive
measurement. If the real plinth is much taller, re-check. **Confirm A5 and A8 on
site and this question closes.**

---

## 5. Depth budget — and the one number that can break the design

| Layer | Depth |
|---|---|
| Bezel face + black bezel | 0.25″ |
| Bare LCD panel | 0.60″ |
| Standoff / air gap | 0.40″ |
| Controller board + Pi 4 | 1.00″ |
| Vented rear shroud | 0.25″ |
| **Total** | **2.50″** |

**Buttons, not the panel, set the floor.** A 30 mm arcade body needs ~1.4″ behind
the plate; 24 mm bodies need ~1.1″. Both fit inside 2.5″ — but if depth gets
tight, downsizing the buttons is the cheapest 0.3″ available.

### C1 — the critical measurement

**C1 = distance from the cabinet's front face plane to the frontmost object
inside the opening** (board edge, connector, ribbon cable, card-puller handle).

**Rule: C1 ≥ door depth + 0.5″.** Assumed here: C1 = 3.0″.

If C1 measures under 3.0″, the door has to change. Escalation ladder, cheapest
first:

1. **24 mm buttons** instead of 30 mm — buys ~0.3″.
2. **Move the Pi off the door**, run a ribbon/HDMI over the hinge — buys ~0.5″,
   but breaks A7.2 (power-only across the hinge) and MR18. Costs reliability.
3. **Stand the door proud** of the front face on the frame — the door no longer
   sits near-flush, which weakens MR19 but is otherwise harmless.
4. **Recess the frame between the boards** rather than over them — only possible
   if the opening has a usable inset.

Measure C1 at **top, middle and bottom** of the opening and design to the
smallest of the three. Cabinets rack out of true and cabling migrates forward
over forty years.

---

## 6. Mounting — three candidates, decided on site

See [drawing 04](drawings/04-door-replacement.svg). Ranked:

**A — 19″ rack rail (preferred).** If the 3280 has EIA-310 rails with a free run,
the fixed frame becomes a **19″ rack panel (~32U)** bolted on with cage nuts and
rack screws. Standards-based, zero modification, fully reversible, and the frame
stock is an off-the-shelf blank. *Risk: the card cage probably occupies the
rails — we need a free run above and/or below it.*

**B — Straddle / clamp bracket.** Brackets wrap the cabinet's front frame lip and
tighten with nylon-tipped thumbscrews. Works regardless of rail availability.
*Needs a graspable lip; nylon or felt at every contact point.*

**C — Existing fastener points.** Reuse original threaded holes or removed
door-hinge points. Cleanest result, loads into real structure. *Entirely
dependent on what's actually there; thread sizes may be obsolete.*

Combining is fine — rail-mount the top, straddle-clamp the bottom.

**Non-negotiable for all three:** no new holes, no adhesive on original surfaces,
nylon or felt at every contact point, and every original fastener removed gets
**bagged and labelled**.

---

## 7. Open risks carried into ME-1

| # | Risk | Closes with |
|---|---|---|
| R1 | **C1 too small — door can't close** | C-series measurements |
| R2 | Cabinet isn't a 19″ rack / rails occupied | B-series |
| R3 | Opening narrower than 19″ → 24″ panel crowds the window | A6, A7 |
| R4 | Plinth taller than assumed → ADA math shifts | A5, A8 |
| R5 | No graspable lip and no free rail → mounting redesign | B, E series |
| R6 | Salvaged panel outline bigger than D3 → door grows | Panel measurement (EL-5) |

---

*Superseded by measured data after ME-1 ([issue #26](https://github.com/nickdnj/3280-kiosk/issues/26)).
When that lands, this file gets a "MEASURED" column beside "ASSUMED" and the
deltas get called out.*

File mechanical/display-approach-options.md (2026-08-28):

# Display Approach — Three Live Options

> ## ⛔ SUPERSEDED FOR REV 1
> The kiosk is no longer a replacement door integrated into the cabinet. It is a
> **self-contained enclosure surface-mounted on the closed factory door** — see
> [`rev1-standalone-kiosk.md`](rev1-standalone-kiosk.md) and the
> [interactive design study](rev1-design-study.html).
> This document describes the **Rev 2** concept and is kept for provenance.
> Don't build from it.

> **Decision status: OPEN.** This is now the top-level mechanical decision, above
> the enclosure question. All three options still need C1 (ME-1 §C), but they
> differ enormously in risk, cost and who can maintain the thing in five years.

**Reads with:** [`door-construction.md`](door-construction.md) ·
[`enclosure-buy-vs-build.md`](enclosure-buy-vs-build.md) ·
[`fab/`](fab/) · [`../docs/01-prd.md`](../docs/01-prd.md) §9

---

## At a glance

Option comparison

Drawn to the assumed cabinet geometry — proportions are real, unlike the AI
concept art elsewhere in the repo. Regenerate with
`python3 drawings/make-option-comparison.py`.

**The headline finding:** A, B and C1 look *almost the same from the front.* If
the monitor is recessed behind a bezel-sized cut, Option C reads as the approved
concept. Only C2 — monitor bolted proud of the panel — looks visibly different.

## The three

| | Approach | Display | Enclosure |
|---|---|---|---|
| **A** | Custom door | **De-cased** bare LCD panel | Fabricated: P1 face + P2 shroud |
| **B** | Buy + modify | **De-cased** bare LCD panel | Leviton structured-media can |
| **C** | **VESA carrier panel** | **Cased commercial monitor, intact** | The monitor's own housing |

C splits into **C1 (recessed)** and **C2 (proud)** — same architecture, very
different result on the one axis that matters to the docents.

A and B differ only in where the box comes from. **C is a different architecture.**

---

## Option C — cased monitor on a hinged carrier panel

Don't de-case anything. Leave the monitor whole, **VESA-mount it to a flat tan
carrier panel**, hinge that panel to the fixed frame, and put the three buttons
on a small plate below it.

```
fixed frame (reversibly mounted, unchanged)
   └── hinged carrier panel — flat tan sheet, left hinge
         ├── VESA 100 x 100 pattern  → commercial monitor, portrait
         ├── button plate below the screen
         └── Pi on the back
```

### What it eliminates

- **De-casing the monitor (EL-5)** — the highest-risk step in the electronics
  track, and irreversible
- **The screen window cut** — the single hardest fabrication operation
- **P2 shroud, P4 brackets** — the monitor's own housing satisfies MR18
- **Thermal design** — the monitor cools itself, as designed and tested by its
  manufacturer
- Panel retention, foam gasketing, window-to-active-area tolerance stack

If the monitor mounts on the **front** of the carrier panel, the panel needs only
an outline, four M4 VESA holes, button holes and hinge holes — **all round holes,
drillable by hand in an afternoon.** No laser, no job shop, no CDL.

### What it costs

**Aesthetics.** A modern black monitor bolted to a 1985 minicomputer reads as
"someone stuck a monitor on it." The docent-approved concept is about the kiosk
*belonging* to the machine — tan frame, black bezel, CONCURRENT badge (MR13).
This is the real loss.

*Mostly recoverable:* cut the carrier panel with a window sized to the monitor's
**bezel outline** and let the monitor sit behind it, so only the screen shows.
That restores the built-in look — and the tolerance is forgiving, because the
monitor's own bezel overlaps the cut. Nothing like the ±0.03″ a bare panel needs.
Add a tan surround and it reads close to the concept.

**Depth.** Roughly a wash. A thin 24″ monitor is ~0.4″ at the bezel and
~1.7–2.2″ at the electronics hump. Recessed into a window, only the hump sits
back — about the same as the 2.5″ custom door.

**MR19 (low profile).** Genuinely given up if the monitor sits proud rather than
recessed.

**Visitor-reachable OSD buttons.** A cased monitor has power and menu buttons.
Cover them with the surround or disable them (NFR3).

### What it wins that the others can't

**Serviceability, and it is not a small thing.** A commercial monitor dies in
2031 and a docent buys another one and bolts it on. A de-cased panel bonded into
a bespoke door cannot be replaced by anyone but us.

The project charter says: *"every project must hand operational ownership to its
actual user before it ships — Nick-in-the-loop forever means the project failed."*
Option C is the only one of the three that honours that for the display.

It also makes salvage-first **easier**, not harder — any working monitor with a
VESA pattern qualifies, and there's no de-casing risk to gamble a good panel on.

---

## Comparison

| | A — custom door | B — buy + modify | **C — VESA carrier** |
|---|---|---|---|
| De-casing risk | ⚠️ one-way | ⚠️ one-way | ✅ **none** |
| Hardest fab op | Window cut, lasered | Window cut, in a formed box | ✅ **round holes** |
| Parts to fabricate | 4 | 1 | ✅ **1, hand-drillable** |
| Thermal | Designed + soak-tested | Designed + soak-tested | ✅ **self-solved** |
| MR18 enclosure | Designed | Designed | ✅ **self-solved** |
| Cost | ~$150 fab + panel | ~$120 can + ~$60 face | ✅ **panel + monitor** |
| Lead time | ~1 week | Off the shelf | ✅ **same day** |
| Low profile (MR19) | ✅ 2.5″ | ⚠️ 3.85″ | ⚠️ ~2.2″ recessed, worse proud |
| Looks built-in (MR13) | ✅ **best** | ✅ good | ⚠️ needs a surround |
| **Replaceable by a docent** | ❌ | ❌ | ✅ **yes** |

---

## Open questions Option C has to answer

1. **Does the display still swing?** The hinge is the defining feature of the
   whole exhibit (MR5, and the entire premise of the brief — swing it open, see
   the card cage). VESA-mounting to a *hinged carrier panel* preserves it. VESA
   mounting straight to the cabinet does **not**, and would gut the concept.
   **The carrier panel is not optional.**
2. **Where do the buttons live?** On the swinging panel (they travel with it), or
   fixed to the frame (they stay put while the screen opens)? Fixed is arguably
   better for visitors and changes what crosses the hinge.
3. **Where does the Pi live?** Behind the monitor on the carrier panel, or in the
   fixed cabinet? If it moves off the door, HDMI + USB cross the hinge instead of
   just 5 V — that reverses A7.2, and needs a service loop rated for it.
4. **Portrait rotation** — monitor rotated 90° on the VESA plate. Confirm the
   candidate's bezel and stand mount allow it cleanly.

---

## Recommendation

**Option C, with the monitor recessed into a bezel-sized window and a tan
surround.**

It removes the two highest-risk items in the project (de-casing and the window
cut), collapses fabrication to one hand-drillable panel, self-solves thermal and
enclosure, and is the only option a museum can maintain without us. Those are
decisive engineering advantages, and the aesthetic gap is mostly closable.

**But this is not purely an engineering call.** The concept Rick signed off on
("YES YES YES. This is just the job.") shows an integrated tan door, not a
commercial monitor in a frame. Changing that should go back to the docents before
it's locked — a mock-up photo would settle it in one conversation.

**Still gated on C1 either way.** Take Wednesday's measurement; then decide.
Nothing here obsoletes the [fab package](fab/) — if A or B wins, it's ready.

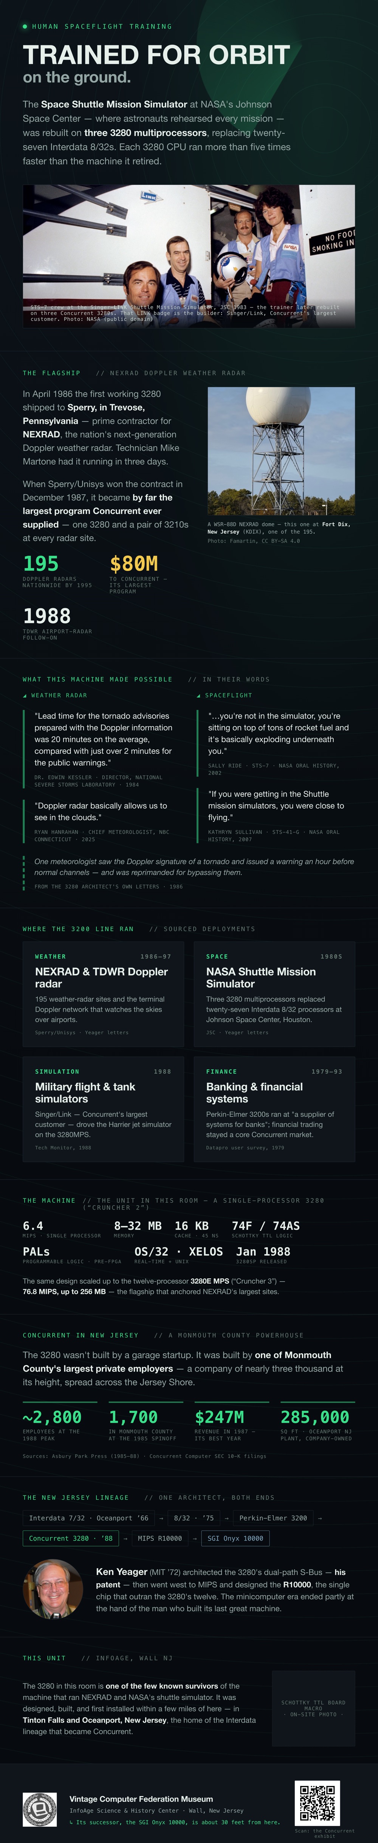
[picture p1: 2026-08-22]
src/kiosk-app/assets/posters/poster-D.jpg

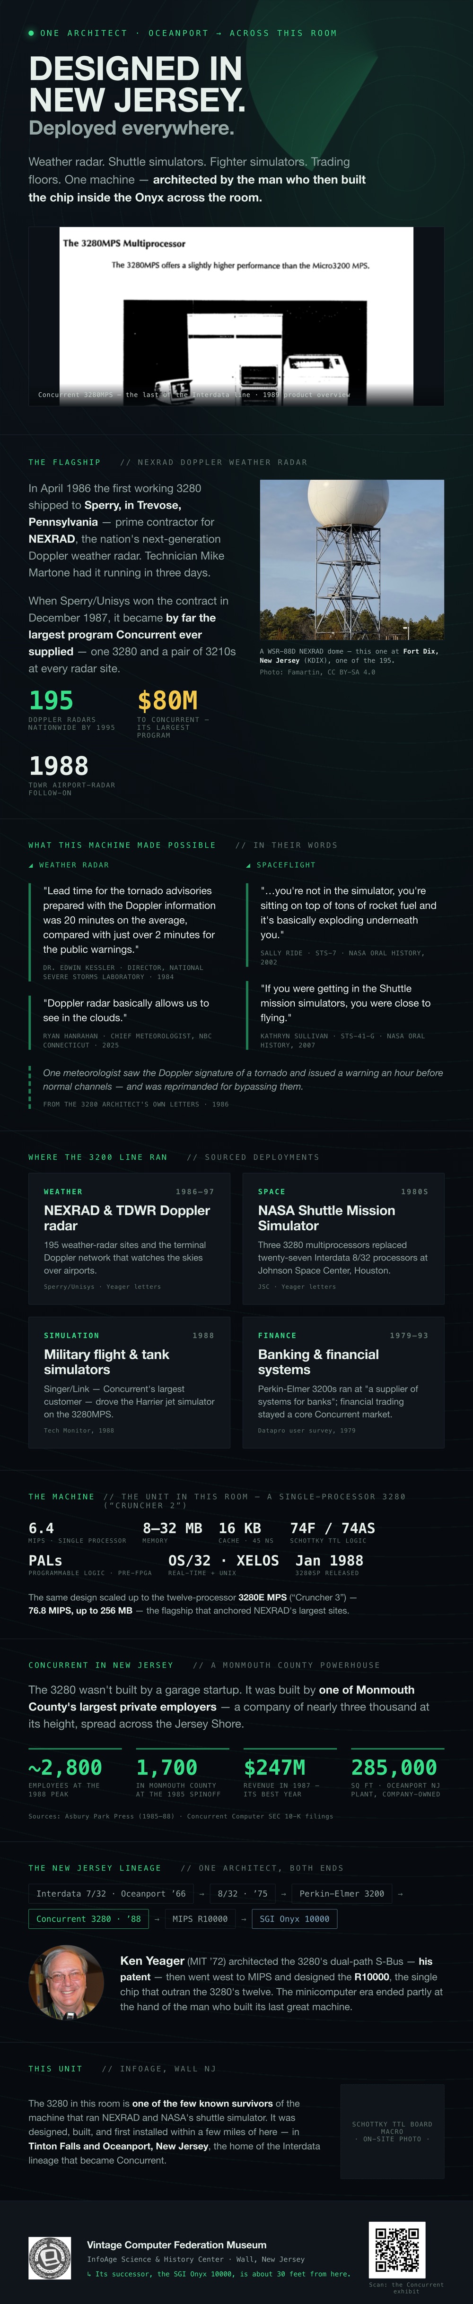
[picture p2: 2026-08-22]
src/kiosk-app/assets/posters/poster-C.jpg

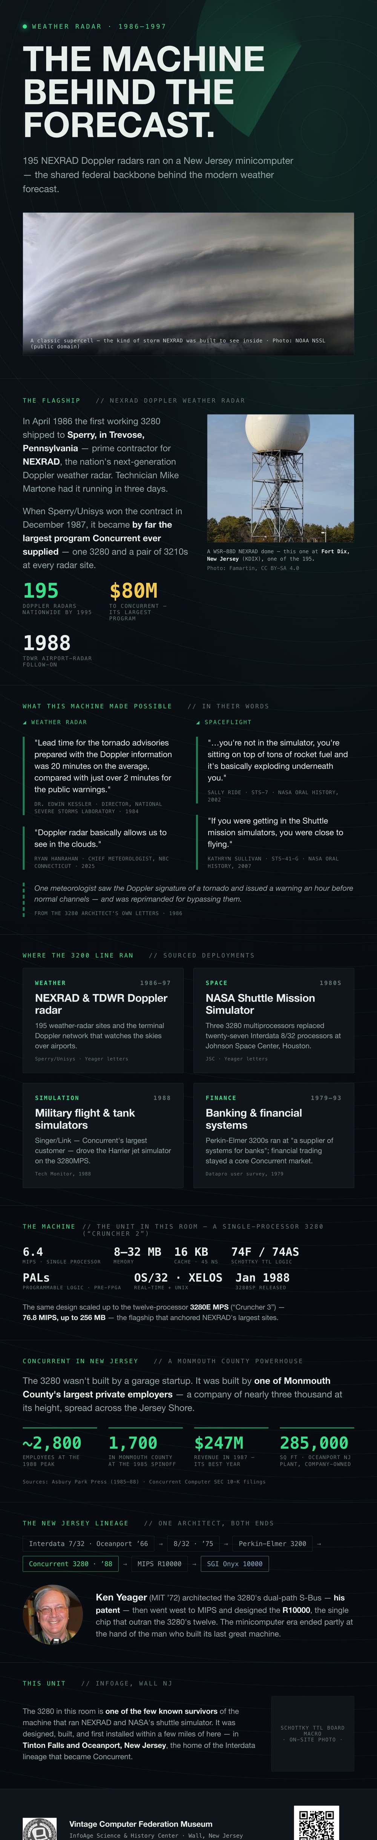
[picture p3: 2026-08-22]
src/kiosk-app/assets/posters/poster-A.jpg

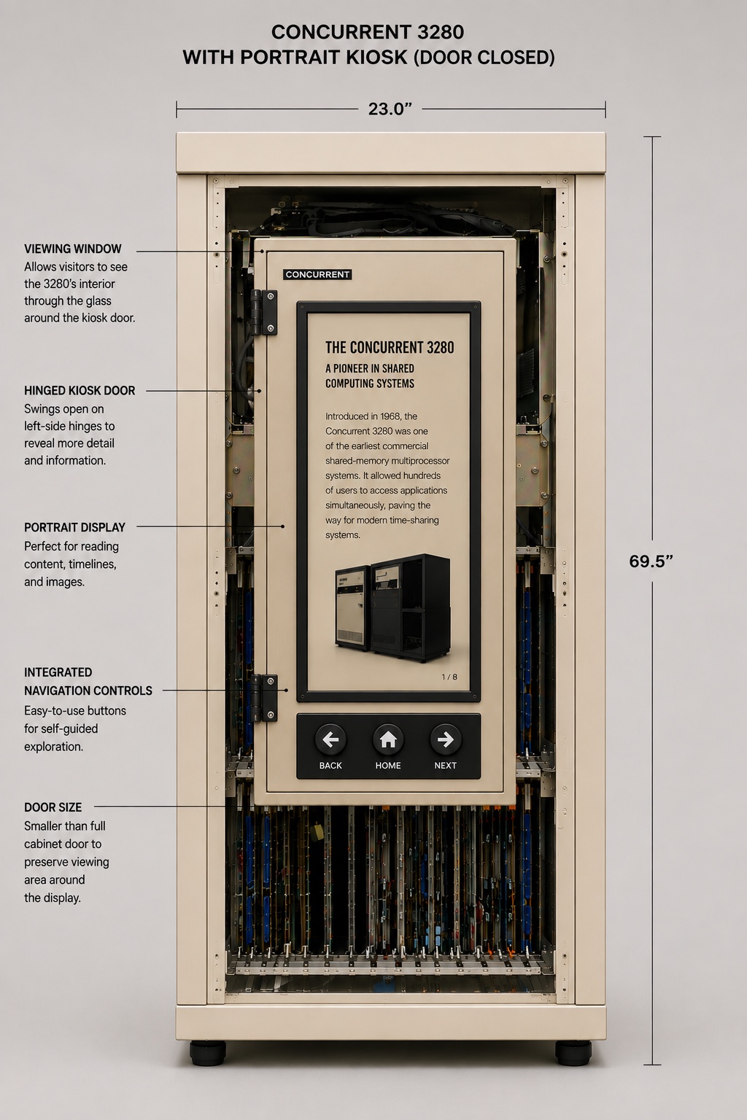
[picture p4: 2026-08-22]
src/kiosk-app/assets/renders/kiosk-concept.jpg

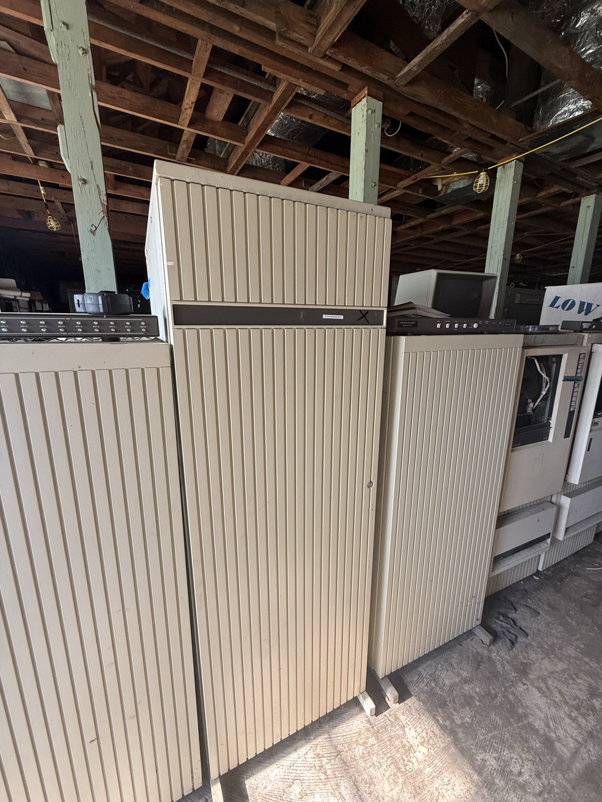
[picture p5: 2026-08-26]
mechanical/photos/me1-cabinets-in-warehouse.jpg

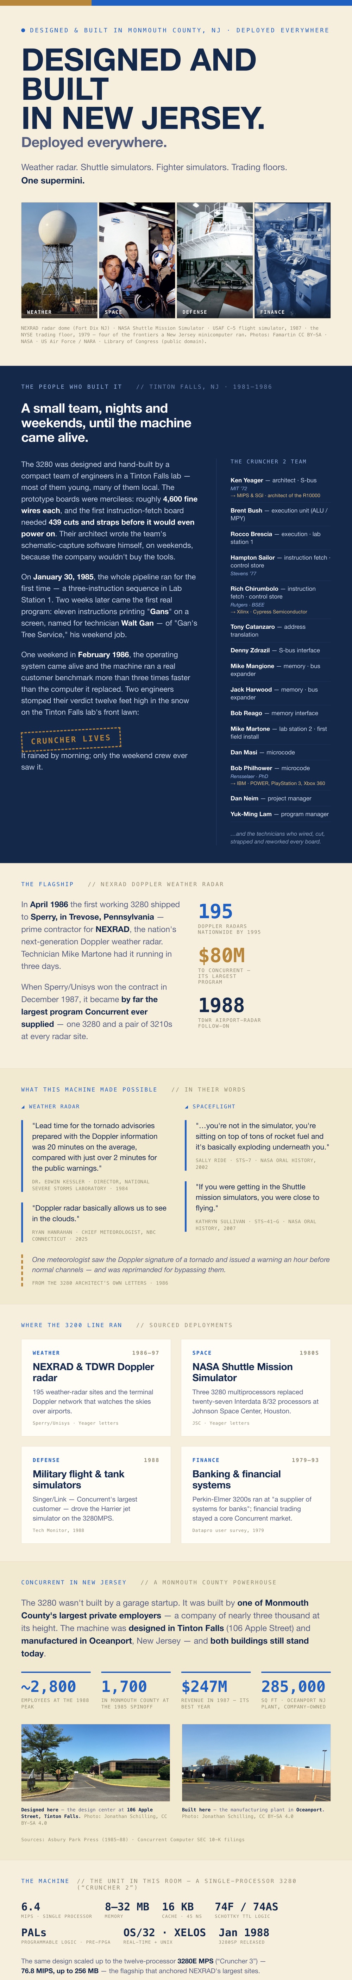
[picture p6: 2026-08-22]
src/kiosk-app/assets/posters/conceptC.jpg

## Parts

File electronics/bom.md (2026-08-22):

# Bill of Materials — v0 (pre-recon)

> **Status: CONCEPT / v0.** Salvage-first per
> [architecture §9](../docs/02-architecture.md). Quantities and sizes assume the
> 24″ panel baseline in
> [`../mechanical/dimensions-assumed.md`](../mechanical/dimensions-assumed.md) —
> both change if the measured opening or the salvaged panel differ. Prices are
> rough placeholders for the buy-new fallback; budget is not a constraint (PRD §15).

**Status key:** ✅ Have · 🔍 Salvage target · 🛒 Buy new · ⏸ Deferred

---

## Compute & storage

| Item | Qty | Status | Spec / note |
|---|---|---|---|
| Raspberry Pi 4 | 1 | ✅ Have | From the drawer. Mounts inside the door shroud (MR18) |
| Pi 4 PSU (USB-C 5 V 3 A) | 1 | 🔍 → 🛒 | Or the exhibit's own 5 V supply (see Power) |
| microSD card, primary | 1 | 🛒 Buy | 32 GB A2 endurance. **Do not salvage** (NFR4) |
| microSD card, golden spare | 1 | 🛒 Buy | Identical to primary; SW-D6 |
| Micro-HDMI → HDMI cable | 1 | 🔍 → 🛒 | Short, 1–2 ft; Pi 4 uses micro-HDMI |
| Heatsink / passive cooling | 1 | 🔍 → 🛒 | Enclosed vented shroud — passive preferred (MR14) |

## Display

| Item | Qty | Status | Spec / note |
|---|---|---|---|
| LCD panel, ~24″ 16:9 | 1 | 🔍 **Salvage — priority 1** | De-cased to bare panel + controller board (EL-5, A8.4) |
| LCD panel, backup | 1 | 🔍 Salvage | De-casing is one-way; a spare de-risks it |
| Panel controller board | 1 | — | Comes with the panel; relocate on standoffs |
| Panel power supply | 1 | 🔍 → 🛒 | Whatever the salvaged panel's board wants |

See [`salvage-recon.md`](salvage-recon.md) §1 for acceptance criteria and the
powered test to run **before** committing to a panel.

## Buttons & input

| Item | Qty | Status | Spec / note |
|---|---|---|---|
| Momentary pushbutton, 30 mm arcade | 5 | 🔍 → 🛒 | 3 mapped (BACK/HOME/NEXT) + 2 spare (ER3). All identical |
| Button harness wire | — | 🔍 → 🛒 | 22 AWG stranded, 5 colours + common |
| Crimp terminals (0.187″ spade) | 12 | 🛒 Buy | Standard arcade microswitch terminals |
| GPIO ribbon / connector | 1 | 🔍 → 🛒 | Pi header → button harness |

> 24 mm bodies (~1.1″ deep) instead of 30 mm (~1.4″) if the measured C1 clearance
> is tight — see `dimensions-assumed.md` §5.

## Power

| Item | Qty | Status | Spec / note |
|---|---|---|---|
| Mains PSU, 5 V 3–4 A | 1 | 🔍 → 🛒 | **Lives in the fixed cabinet**, not the door (A7.2) |
| USB-C cable, 3–6 ft | 1 | 🔍 → 🛒 | The only conductor crossing the hinge (MR10) |
| Strain relief grommets | 2 | 🛒 Buy | Both ends of the hinge service loop |
| Split loom / spiral wrap | 1 | 🔍 → 🛒 | Dress the service loop |
| AC timer or switched relay | 1 | 🔍 → 🛒 | Museum-hours scheduling (EL-4, NFR2) |
| IEC cord / power strip | 1 | 🔍 → 🛒 | |

## Mounting & structure *(mechanical, listed here for one-trip shopping)*

| Item | Qty | Status | Spec / note |
|---|---|---|---|
| 19″ blank rack panel | 1–2 | 🔍 Salvage | Becomes the fixed frame if mount candidate A wins |
| Cage nuts + rack screws | 12+ | 🔍 → 🛒 | Bring samples to test-fit on site (checklist §B4) |
| Sheet stock, door + frame | ~4 sq ft | 🔍 → 🛒 | Alu 0.050–0.080″ or ABS/HDPE, paintable |
| Continuous (piano) hinge | 1 | 🔍 → 🛒 | ≥ 24″. Hardest item to salvage |
| Hold-open stay or friction hinge | 1 | 🔍 → 🛒 | ~12 lb door (MR6) |
| Magnetic / ball-detent catch | 1–2 | 🔍 → 🛒 | Closed-position hold |
| Over-travel stop | 1 | — | Fabricated; protects the boards (MR7) |
| Nylon / felt contact pads | — | 🛒 Buy | **Required** at every artifact contact point (MR2) |
| Standoffs M2.5 / M3, nylon washers | — | 🔍 → 🛒 | Pi and controller board mounting |
| Tan paint + scrap for colour match | 1 | 🔍 Salvage | MR13 — grab a tan offcut if one exists |

## Deferred

| Item | Status | Note |
|---|---|---|
| Plexiglass board-protection panel | ⏸ Deferred | ME-10 / PRD §11 — later add-on |
| Spare-button LEDs + drivers | ⏸ Deferred | v1 buttons are unlit |
| WebSocket button transport | ⏸ Deferred | uinput synthetic keys chosen (A4.2) |

---

## What's actually blocking

Only two lines matter before the mechanical build can start:

1. **The panel** — its real outline, thickness and controller-board form factor
   set the door geometry. Everything in `mechanical/` waits on it.
2. **The mount hardware** — decided by what the cabinet offers (checklist §B, §E),
   not by what's in this table.

Everything else is cheap, standard, and substitutable — which is the point of the
"adaptable, standards-based parts" rule in architecture §9.

---

*Updated after each salvage run. Move items from 🔍 to ✅ as they come home, and
note make/model so a replacement can be sourced later.*

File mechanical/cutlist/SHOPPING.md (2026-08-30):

# Shopping list — 3280 kiosk box

> Generated by `make-cutlist.py`. Prices seen at Home Depot West Long Branch,
> 2026-08-29. Assumes the boards measure **0.750"** and the MDF **0.500"** —
> *measure before cutting.*

## Buy

| Item | Model | Qty | Price |
|---|---|---|---|
| 1x4 x 8 ft Kiln-Dried Whitewood Common (actual .750 x 3.5)<br>*P2 P3 -- the tube, at full width. 1 needed, 1 spare. SIGHT DOWN EACH BOARD* | 914681 | ×2 | $19.06 |
| 1x3 x 8 ft Kiln-Dried Whitewood Common (actual .750 x 2.5)<br>*P7 P8 P9 -- at full width. 2 needed, 1 spare* | 914649 | ×3 | $22.32 |
| ProWood 1/2 in. x 2 ft. x 4 ft. MDF Project Panel<br>*P4 rear cover* | 109097 | ×1 | $27.48 |
| Titebond II, 120 + 180 grit, #6 x 1-1/4 wood screws (40)<br>*assembly* | -- | ×1 | ~$20 |
| | | | **$68.86** |

**Zero rips.** Every board is used at its full width, so the only wood cuts are
**9 crosscuts** — a mitre saw does all of it.

**Home Depot cuts the MDF.** The rear panel is deliberately 0.250" undersize and
lands on a 2.500" ledge, so their ±1/8" cannot matter. Ask for:

- **P4 rear panel — 13.250 × 28.250**
- **P10 Pi tray — 4.000 × 3.000**

## Measure first

Calipers in four places on a board. If it differs, re-run:

```bash
python3 make-cutlist.py --ply <board> --rear <mdf>
```

## Cut — 1x4, at full width (3.5")

| Part | Width | Length | Qty |
|---|---|---|---|
| P2  SIDE PANEL | 3.500 | 30.000 | ×2 |
| P3  TOP / BOTTOM | 3.500 | 13.500 | ×2 |

## Cut — 1x3, at full width (2.5")

| Part | Length | Qty |
|---|---|---|
| P7  BUTTON RAIL | 13.500 | ×1 |
| P8  REAR CLEAT, VERT | 28.500 | ×2 |
| P9  VESA RAIL | 28.500 | ×2 |

## From the MDF — Home Depot cuts these

| Part | Size |
|---|---|
| P4  REAR PANEL | 13.250 × 28.250 |
| P10 PI TRAY | 4.000 × 3.000 |

## Order of operations

1. Crosscut **P2 ×2 to 30.000** — the only parts whose size never moves.
2. Dry-assemble with P3 and **measure the real cavity.**
3. Cut P3, P7, P8, P9 to what you measured, not to the tables above.
4. Glue and screw the tube. **Pilot every hole** — pine end grain splits.
5. P7 button rail, front-flush, centreline 24" below the top edge.
6. P8 rear cleats, **turned 90°** so they sit behind the monitor.
7. Threaded inserts — 15 on P1's pattern. **Epoxy them.**
8. P9 rails, monitor, Pi tray. **Then the foam seal onto the back of P1**,
   then P1, then the back panel.

## Not at Home Depot

- #8-32 brass threaded inserts for wood (15) — Rockler / McMaster
- #8-32 button-head pin-torx screws, black (15) — McMaster
- **30 mm anti-vandal switches (3)** — one of two gates on the face plate order
- **Foam tape, BLACK closed-cell neoprene or EPDM, 1/4" wide × 3/16" thick**
  — the light seal behind P1; 65" used, so a 10 ft roll is plenty.
  Check the weatherstripping aisle first. It must be black, closed-cell, and
  **no wider than 1/4"** — wider tape runs off the bezel and onto the glass.

## Before you buy the monitor

Three numbers decide whether a monitor fits this box at all. The picture is
centred on the plate, so the CASING is not — it shifts toward its thick edge.

| | limit |
|---|---|
| thick bezel — the "chin", a SIDE edge in portrait | **≤ 0.92"** |
| bezel on the long edges — top and bottom in portrait | **≤ 0.60"** |
| body thickness at its deepest | **≤ 2.12"** |

Plus: matte screen, VESA 100, and it must power itself back up after a mains
cut. Then measure the **lit rectangle** — that is what P1's window is cut from.

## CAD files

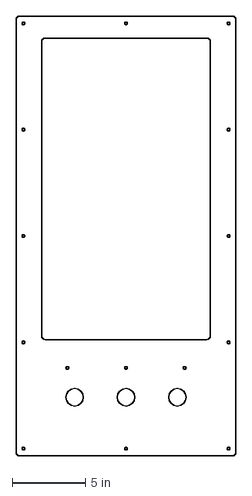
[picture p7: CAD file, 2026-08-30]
mechanical/fab-rev1/P1-face-plate.dxf
15.0 x 30.0 in

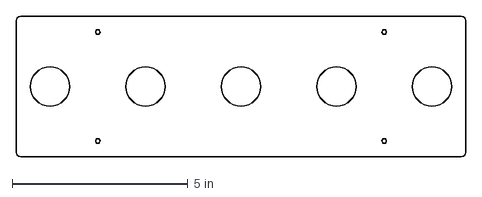
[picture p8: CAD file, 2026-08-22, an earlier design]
mechanical/fab/P3-button-plate.dxf
12.8 x 4.00 in

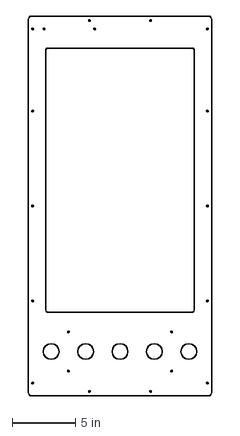
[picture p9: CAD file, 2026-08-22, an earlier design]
mechanical/fab/P1-face.dxf
14.5 x 30.0 in

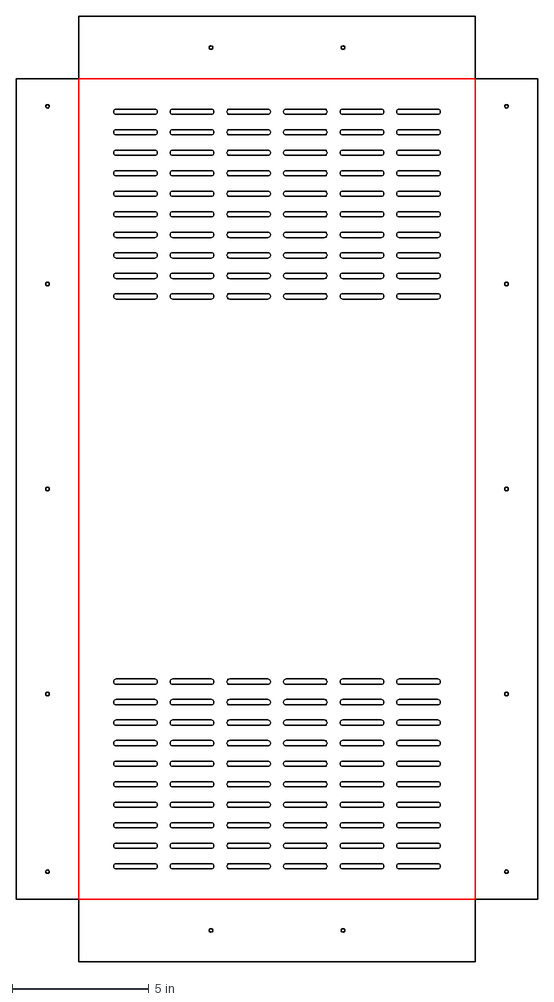
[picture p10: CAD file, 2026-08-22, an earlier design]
mechanical/fab/P2-shroud-flat.dxf
19.1 x 34.6 in

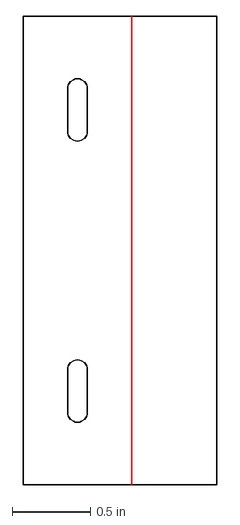
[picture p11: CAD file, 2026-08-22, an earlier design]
mechanical/fab/P4-panel-bracket.dxf
1.24 x 3.00 in

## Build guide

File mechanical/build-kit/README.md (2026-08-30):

# Build kit — the 15 × 30 box

> ⚠️ **Concept.** Nothing has been built. Everything here is generated from
> [`../fab-rev1/_p1.py`](../fab-rev1/_p1.py), so the cookbook, the DXF and the
> cut list cannot disagree.

**[`3280-K-box-cookbook.pdf`](3280-K-box-cookbook.pdf)** — 22 pages, Letter.
Print it and build from it.

```bash
./make-pdf.sh          # regenerates + verifies 22 Letter pages
python3 _kit.py        # kit contents + 13 checks, and the monitor buy criteria
```

---

## What's in the book

| | |
|---|---|
| 1 | Cover — the finished box |
| 2 | Safety: glasses and mask · work flat on a blanket · no hammer · pilot every hole · two people |
| **3** | **Step 0 — measure the monitor's lit rectangle.** Before P1 is ordered |
| **4** | **Kit A — wood as bought**, with model numbers |
| **5** | **Kit B — the eight parts**, drawn to relative scale |
| **6** | **Kit C — fasteners**, F1–F8 at 1:1 with counts |
| **7** | **Kit D — glue and finish**, plus the all-six-faces rule |
| **8** | **Kit E — the twelve tools** |
| 9 | How to measure: one end · square the line · blade on the waste side |
| 10 | The nine crosscuts, laid out on each board |
| 11–19 | Assembly, one step per page |
| **20** | **The light seal** — foam onto the back of P1, with the front-end section |
| 21 | Face plate on, then the back |
| 22 | Done — and don't hang it on the machine yet |

Wordless except where a human has to measure something. The only numerals are
dimensions, counts and part codes.

## Kit contents

**Wood** — 1×4 × 8 ft (914681) ×2 · 1×3 × 8 ft (914649) ×3 · ½″ MDF 2×4 (109097)
×1. Home Depot cuts the MDF; you never handle a sheet good.

**Parts, all crosscuts** — P2 side 3½ × 30 ×2 · P3 top/bottom 3½ × 13½ ×2 ·
P7 button rail 13½ · P8 rear cleat 28½ ×2 · P9 VESA rail 28½ ×2 · P4 rear panel
13¼ × 28¼ (MDF) · P10 tray 4 × 3 (MDF) · P1 face plate 15 × 30 (ACM, ordered).

**Fasteners and seals — 91 pieces**

| | | |
|---|---|---|
| F1 | wood screw #6 × 1¼ | ×40 |
| F2 | threaded insert #8-32 brass | ×21 |
| F3 | screw #8-32 × ½ button head | ×15 |
| F4 | thumbscrew #8-32 × ½ | ×6 |
| F5 | bolt M4 × 12 + washer | ×4 |
| F6 | switch, 30 mm anti-vandal | ×3 |
| F7 | inlet, IEC C14 fused | ×1 |
| F8 | foam tape, black neoprene, ¼ × 3⁄16, 10 ft | ×1 |

F2 and F3 are **derived from P1's hole count**, and `_kit.py` checks it — if the
face plate ever changes, the kit count follows.

**Glue and finish** — G1 PVA wood glue · G2 five-minute epoxy (the 21 inserts,
nothing else) · G3 sanding sealer or primer · G4 satin black.

**Tools** — mitre saw · tape · combination square · pencil · drill/driver ·
bits (7/64 pilot, 3/8 insert, countersink) · insert driver · clamps ×4 ·
sandpaper 120 + 180 · safety glasses · dust mask · brush.

**Also bring** — blue tape; a rag and denatured alcohol, both for squeeze-out
and for wiping the back of P1 before the foam goes on (it will not stick to a
dusty ACM face); and cardboard for the printed P1 mock-up.

## The three rules the book keeps repeating

1. **Cut P2 first, dry-fit, measure the real cavity.** Then cut everything else
   to what you measured. The tables are a prediction; the box is the truth.
2. **Pilot every hole.** Pine end grain splits, and the corner screws go into it.
3. **Seal all six faces**, inside included. A panel sealed on one side cups
   toward the unsealed one, and a cupped rear panel opens a gap at the face plate.
4. **The face plate never touches the monitor.** The P9 rails set the panel's
   position 1/8″ behind the ACM; the foam seal is 3/16″ thick and lands at 33 %
   compression. It is a light seal, not a clamp — see page 20.

## Not in the kit

The **monitor** — ungated, and it must survive a power cut and be matte.
The **Raspberry Pi and PSU**. The **mounting adapter**, still undesigned with
0.382″ of the ADA §307.2 budget left.

**Two things gate P1's release**, and both are cheap to clear:

1. The **⌀30.5 mm switch cutout**, against the datasheet of the switch you
   actually buy.
2. The **monitor's lit rectangle**, measured with a tape off a white screen.
   The window is now cut 3/16″ *smaller* than the picture so that no bezel shows,
   which means P1 can no longer be ordered before the monitor exists. Page 3.

The box itself is gated on neither. Buy the wood and start.

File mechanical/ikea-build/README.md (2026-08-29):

# Variant K — building the kiosk box out of IKEA

> ## 🗄 SHELVED 2026-08-29
> **Not the build route.** The kiosk box is built per the released package —
> ½″ Baltic birch, sheets [300 / 301 / 302](../dwg/). Variant K is kept for the
> finding in §1, which is the part that outlives it.
>
> **Why it was shelved:** the idea was only worth having if IKEA sold something
> we could use *directly*. It doesn't — §1 below is the proof — and once it
> reduced to "buy pine and cut it yourself," IKEA stopped being special. A
> quarter sheet of Baltic birch is better material than knotty IVAR pine, and
> §4 already conceded that. The $39 was never the point.
>
> **What to take from it:** §1 generalises past IKEA. *No* off-the-shelf shallow
> cabinet can work, whoever makes it, because ADA §307.2 allows the kiosk
> 4.000″ of total projection and the shallowest wall cabinets on the market are
> 6¾″ deep. When someone suggests buying an enclosure — and someone will —
> that is the number that settles it.
>
> ⚠️ **Concept.** Nothing here was cut or built.

**The short answer: you cannot buy the kiosk at IKEA, but you can buy the wood
there for $39, and one $12 shelf makes the entire box.**

Two deliverables:

| | |
|---|---|
| **[`3280-K-assembly-manual.pdf`](3280-K-assembly-manual.pdf)** | 15-page IKEA-style manual — shopping, cut plans, hardware, six assembly steps. Print it. |
| **[`_geom_k.py`](_geom_k.py)** | the geometry, with 16 self-checks. `python3 _geom_k.py` |

Everything except **P1, the face plate** — which is CNC-routed by SendCutSend
from 3 mm ACM, exactly as [`../fab-rev1/`](../fab-rev1/) already specifies.

---

## 1. Why no IKEA product can *be* the enclosure

I checked this before designing around it, because if a $60 cabinet worked, the
whole cut plan below would be wasted effort. It doesn't, and the reason is a
single number.

**ADA §307.2 caps the kiosk at 4.000″ of projection.** Its leading edge lands at
34.75″ AFF, above the 27″ threshold where the protruding-objects rule starts
applying. The enclosure takes 3.250″ and the mounting adapter gets the remaining
0.750″. That budget is what kills every candidate:

| | Depth | |
|---|---|---|
| **Our budget** | **3.250″** | |
| ENHET wall cabinet — IKEA's shallowest | 6¾″ | 2× over. Blows §307.2 on its own. |
| BESTÅ frame | 15″ | not close |
| RÖDALM / former RIBBA frames | ~2″ | too *shallow* for a 1.8″ monitor, and it's thin MDF — it will not carry 24 lb or hold a panel-mount switch |

Cabinets are too deep, frames are too shallow, and nothing sits in between. It
is not a near miss.

## 2. What IKEA *is* good for

**IVAR shelves are solid pine, ¾″ thick, untreated, and cheap.** That is real
material — not particleboard, not veneered MDF — and IKEA is one of the few
places that sells it in small flat pieces instead of 8-foot boards.

| Buy | Size | Price | For |
|---|---|---|---|
| **2 × [IVAR shelf 83×30](https://www.ikea.com/us/en/p/ivar-shelf-pine-30318163/)** (303.181.63) | 32⅝ × 11¾ × ¾″ | $12.00 ea | shelf A → the box tube · shelf B → every cleat + the Pi tray |
| **1 × [IVAR shelf 83×50](https://www.ikea.com/us/en/p/ivar-shelf-pine-80318165/)** (803.181.65) | 32⅝ × 19⅝ × ¾″ | $15.00 | shelf C → the rear panel |
| 1 × [FIXA / TRIXIG stick-on floor protectors](https://www.ikea.com/us/en/p/fixa-stick-on-floor-protectors-set-of-20-gray-00431151/) | 1⅝″ hex felt, ×20 | ~$5 | soft, non-marring bumpers on the kiosk's back — see §6 |
| | | **$39** | wood only |

Prices seen on ikea.com/us, 2026-08-28, both shelves on sale. IKEA does not cut
material for you — assume you are ripping it yourself.

**One 83×30 shelf makes the whole four-sided box.** Rip it into three 3.132″
strips: two become the full-height sides, the third yields both the top and the
bottom with 4.9″ to spare. That is a genuinely tidy result and it is why this
variant is worth writing down.

## 3. What changes, and what deliberately doesn't

Baltic birch ½″ becomes IKEA pine ¾″. **The envelope does not move** —
15.370 × 28.690 × 3.250″. P1, the ADA placement maths, sheet 100 and the
adapter's 0.750″ budget all key off those numbers, so changing them would
invalidate the released drawing package. Variant K changes only what is inside.

Three consequences fall out of the extra ¼″ of wall:

**The face plate still lands on solid wood.** P1's mount holes sit 0.625″ in from
the edge. A ¾″ wall plus a ¾″ cleat glued flush behind it presents a continuous
1.500″ landing band, so every insert has material all round it. No hole moves.

**The VESA rails are gone.** They no longer fit the depth chain, so the monitor
bolts straight through the ¾″ rear panel on 12 mm M4 standoffs. That is stiffer
than two ½″ rails, it is one part fewer, and it turns the rear panel into a
**lift-out service module** — undo six thumbscrews and the monitor, the Pi and
the tray all come out together on the bench.

The trade: you can no longer reach behind the monitor without unbolting it, and
the panel is heavy and awkward while it is loose. That is a two-person job, and
it is why the manual opens with the two-people page.

```
0.000  P1, 3 mm ACM
0.118  ─ 0.100 bezel clearance
0.218  monitor front
2.018  monitor back
       ─ 0.482 cable gap  (12 mm standoff + 0.010 shim)
2.500  rear panel front
3.250  rear panel back = back of the box
```

**Weight is a wash.** 24 lb finished, against ~23 lb for the birch build — pine
is lighter per cubic inch, and we use more of it.

## 4. The two honest downsides

**Solid softwood moves with humidity; plywood barely does.** The rear panel is
the piece at risk — 13.7″ across the grain, in a building that is not climate
controlled. Mitigations, all of them in the drawings: cut it with the **grain
running the long way** (manual page 6), it is edge-glued stock rather than a
single board, it gets 0.100″ of clearance per side across the grain against
0.050″ along, and it is sealed on all six faces. If this still worries you, buy
that one piece as ½″ Baltic birch and leave the rest IKEA — nothing else in the
design changes.

**Pine is soft, and IVAR is knotty.** Threaded inserts hold less well in
softwood edge grain than in birch ply, so **epoxy them in** rather than trusting
the threads. Lay the cuts out to keep knots away from the 21 insert positions —
the cut plan leaves enough spare material to choose.

## 5. Sequence

1. Buy the three shelves. Check each one for cup and twist **in the store** —
   sight down the length. Reject bowed ones.
2. Cut per manual pages 5–6.
3. Assemble per manual pages 9–14.
4. Bench-test the whole kiosk. No 3280 involved.
5. **Then** design the mounting adapter. Still undesigned, still has 0.750″.

## 6. About the felt pads

They go on the **kiosk's** back, never on the machine, as the soft interface
between our enclosure and the 3280's original textured paint. They are a
suggestion for the adapter designer, not a decision — the interface material is
that subsystem's call, and long-term contact with an artifact's finish deserves
the museum's opinion before anything is stuck down.

## 7. Files

```
_geom_k.py        geometry + 16 self-checks
_draw.py          line-art primitives (isometric, IKEA man, bubbles)
make-manual.py    generates the 15 pages; refuses to pass if anything falls off a page
make-pdf.sh       build + verify the PDF is 15 Letter pages
manual/*.svg      the pages
```

Change a dimension in `_geom_k.py`, run `./make-pdf.sh`, and the manual redraws.

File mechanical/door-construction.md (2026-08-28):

# Door Construction — ME-4 Spec

> ## ⛔ SUPERSEDED FOR REV 1
> The kiosk is no longer a replacement door integrated into the cabinet. It is a
> **self-contained enclosure surface-mounted on the closed factory door** — see
> [`rev1-standalone-kiosk.md`](rev1-standalone-kiosk.md) and the
> [interactive design study](rev1-design-study.html).
> This document describes the **Rev 2** concept and is kept for provenance.
> Don't build from it.

> **Status: CONCEPT / spec.** Material and method are decided (2026-08-22);
> final geometry is not. The dimensions here inherit from
> [`dimensions-assumed.md`](dimensions-assumed.md) and are **assumed until ME-1
> and the salvaged panel land.** Do not order parts against this yet — see §9.

**Decision:** the door face, rear shroud and button plate are **laser-cut 5052
aluminum, outsourced to a job shop**. Small parts are 3D printed. Finishing and
assembly happen locally.

**Reads with:** [`dimensions-assumed.md`](dimensions-assumed.md) ·
[`../docs/01-prd.md`](../docs/01-prd.md) §9 (MR5, MR8, MR12–MR19) ·
[`../docs/02-architecture.md`](../docs/02-architecture.md) §8

---

## 1. The governing idea: the door is a box

A 14.5″ × 30″ sheet of anything thin is floppy. Rigidity comes from the **closed
box section** formed when the face and the rear shroud are joined around the
perimeter — not from either part alone.

**Consequence:** the shroud is a structural member, not a cover. It gets designed
and toleranced with the face, and the two are never considered separately. A door
assembled face-first with the shroud "added later" will sag and rack.

---

## 2. Why aluminum, and why outsourced

**Why aluminum**

- **It matches the artifact.** The 3280's cabinet is painted sheet metal. An
  aluminum door has the same sheen, edge quality and sound. Wood and plastic read
  wrong at the distance a docent stands.
- **It solves the thermal problem** (§5). A Pi 4 *and* an LCD backlight inside a
  sealed 2.5″ box is a real risk. Aluminum gives a conduction path; plastic and
  wood do not.
- **It's light enough.** 5052 at these gauges lands the door around 14.5 lb —
  fine for a continuous hinge.
- **Fire behaviour** is a non-issue in an exhibit enclosure.

**Why outsourced**

Mechanical is the highest-risk track and it isn't the builder's strong domain —
electronics is. Outsourcing the sheet metal converts the hardest fabrication step
into a **CAD step**. "Cut a clean 11.8″ × 20.9″ window in aluminum by hand"
becomes "check a drawing." That is the largest single risk reduction available on
ME-4.

This does not conflict with salvage-first (architecture §9): that policy governs
*parts* — monitors, buttons, hardware. Budget is explicitly not a constraint
(PRD §15). Fabricating the one component that has to look right is a different
question from buying a monitor that could have been scavenged.

**Rejected:** steel (~16 lb, too heavy for the hinge) · acrylic (cracks at
fastener holes under public abuse) · HDPE (won't take paint — kills MR13) ·
3D-printed face (5× any consumer bed; tiling means visible seams and warp).

---

## 3. Parts

### Outsourced — laser cut

| # | Part | Material | Operations | Finish as ordered |
|---|---|---|---|---|
| **P1** | Door face | 5052-H32, **0.080″** | Cut outline, screen window, button holes, badge recess, perimeter mounting holes | Raw, deburred — painted locally |
| **P2** | Rear shroud | 5052-H32, **0.063″** | Cut flat blank + vent pattern, then **bent** to a shallow tray | Raw, deburred |
| **P3** | Button plate | 5052-H32, **0.080″** | Cut outline + 5 button holes (3 used, 2 blanked) | **Black anodized** |
| **P4** | Panel retention brackets | 5052, 0.063″ | Cut + bent L-brackets, slotted holes | Raw |

**P3 is deliberately a separate part.** Spares can be re-drilled or the plate
swapped without touching the painted tan face. It also gets a crisper black from
anodizing than from paint.

### 3D printed

| # | Part | Note |
|---|---|---|
| S1 | LCD panel retention clips | Clamp the panel chassis edge on foam |
| S2 | Pi 4 mount / standoff carrier | Positions the Pi against the shroud for thermal contact |
| S3 | Controller-board standoff carrier | |
| S4 | Hinge spacers / shims | Set the door's standoff from the frame |
| S5 | **Over-travel stop** | MR7 — protects the boards. Print in PETG, not PLA |
| S6 | Button-plate backing / light block | |

### Bought

Perimeter joining angle or standoffs, M3 fasteners, closed-cell foam gasket tape,
thermal pad, nylon washers, self-etching primer, tan topcoat, satin black.

---

## 4. The stack — front to back

| Depth | Layer |
|---|---|
| 0.080″ | **P1 face**, tan, with the screen window |
| — | Satin-black bezel band, painted on P1 around the window |
| ~0.03″ | Foam gasket — light seal + compliance against the panel glass |
| ~0.60″ | **De-cased LCD panel** |
| ~0.40″ | Standoff / air gap |
| ~1.00″ | Controller board + Pi 4 on standoffs |
| 0.063″ | **P2 rear shroud**, vented, screwed on — removable for service (MR16) |
| **2.50″** | **Total target** |

**Window sizing.** The cut window is **0.06″ smaller than the active area
overall** (0.03″ overlap per side) so the bezel hides the panel's edge transition
and any backlight leak. Cutting the window exactly to the active area leaves a
visible seam.

**Panel retention — read this before touching a de-cased panel.** A bare LCD is
held in a thin metal chassis frame and the glass is fragile. **Never screw into
the panel** unless it has factory mounting tabs. Retain it by clamping the
*chassis edges* between the face and the P4 brackets, on foam. Use **slotted
holes** in P4 — the salvaged panel's real outline is the biggest unknown in this
design and the brackets have to absorb that variation.

---

## 5. Thermal

A Pi 4 and an LCD backlight in a sealed 2.5″ enclosure is the failure that shows
up three months after install, not on the bench. Two mitigations, both required:

1. **Conduction.** A thermal pad from the Pi's SoC to the P2 shroud makes the
   **entire shroud a heatsink**. This is the main reason the shroud is aluminum.
   S2 positions the Pi to hold that contact.
2. **Convection.** Vent pattern cut into P2 while it's flat — free, the laser is
   already running. **Intake low, exhaust high**, so it chimneys. As drawn
   in [`fab/`](fab/): two fields of 6 × 10 slots at 1.60″ × 0.20″ — 38.4 sq in,
   **8.8%** of the rear face, webs 0.47″. The soak test below is the real
   acceptance criterion; if it runs hot, open the fields up or add a fan.

**Verify on the bench** (part of EL-1 / IN-2): assembled and closed, run the app
for two hours and log `vcgencmd measure_temp`. Sustained temps under 70 °C are
fine; anything approaching 80 °C means more open area or an active fan.

---

## 6. Finish

Order the parts **raw and deburred, not powder coated** — job shops can't
custom-match a 1980s tan from a standard powder palette.

1. Degrease.
2. **Self-etching primer** — mandatory on aluminum; ordinary primer will peel.
3. **Tan topcoat**, matched from the scavenged scrap panel (salvage-recon §4).
   Automotive rattle can or airbrush; several light coats.
4. **Satin black** bezel band around the window, masked.
5. Clear coat if the exhibit gets handled hard — optional.
6. **CONCURRENT badge** in the recess (MR13).

P3 arrives black anodized and needs no finishing.

---

## 7. Weight

| Item | lb |
|---|---|
| P1 face, 0.080″ alu, less window | 3.4 |
| P2 shroud, 0.063″ alu | 4.0 |
| De-cased panel + controller board | 4.5 |
| Pi 4 + wiring | 0.5 |
| Buttons + P3 plate | 1.0 |
| Fasteners, angle, brackets | 1.0 |
| **Total** | **~14.5 lb** |

Supersedes the ~12 lb figure in drawing 02. CG sits roughly 7″ from the hinge
line → **~100 in-lb** moment. A continuous (piano) hinge handles this comfortably;
two butt hinges would be marginal and would let the free edge sag over time.
**Spec the continuous hinge.**

---

## 8. Working with the job shop

Candidates: SendCutSend, OSH Cut, Ponoko. All cut 5052, bend, tap, countersink,
deburr and anodize.

**File requirements**

- **DXF, one part per file**, units in inches.
- Closed vector paths, no overlapping or duplicate lines, no construction
  geometry, no dimensions or text in the cut layer.
- Bend lines on a separate layer, with the bend direction called out.
- Minimum hole diameter ≥ material thickness — all our holes clear this easily.
- Inside bend radius ≈ material thickness for 5052; include **bend relief** at
  the corners of P2 or it will tear.

**Specify on the order:** deburr all edges (public-safety, MR15) · P3 black
anodize · P1/P2/P4 raw for local paint · countersink any fastener that must sit
flush on the face.

**Tolerance reality.** Laser cut parts come in around ±0.005″ — far tighter than
anything else in this build. **The uncertainty is the salvaged panel, not the
fabrication.** That's why P4 has slotted holes and the panel is clamped on foam
rather than dropped into a tight pocket.

---

## 9. What's still blocked

Parts cannot be ordered until three things are known:

| Blocker | Source | What it fixes |
|---|---|---|
| **Real panel outline + thickness** | EL-5, after salvage | P1 window, P4 brackets, the whole depth budget |
| **Controller board footprint + cable lengths** | EL-5 | Interior layout, where the Pi sits |
| **C1 clearance** | ME-1 §C | Whether 2.5″ depth survives at all |

If C1 comes in under 2.5″, the escalation ladder in
[`dimensions-assumed.md`](dimensions-assumed.md) §5 applies and this spec is
revised before anything is cut.

---

## 10. Build sequence

1. **ME-1** — measure the machine; confirm C1 and the opening.
2. **EL-5** — salvage and power-test the panel, then de-case it. Measure the real
   outline, thickness, and controller-board footprint.
3. **Full-size cardboard mockup.** Cut the door outline from cardboard or
   hardboard and hold it in the opening. Checks ADA reach, sightlines, swing
   clearance and how much card cage stays visible — **before** spending on
   aluminum. Cheapest de-risking step in the whole project.
4. **CAD → DXF** for P1–P4.
5. **Order.** ~1 week turnaround.
6. **3D print** S1–S6 while the order is out.
7. **Finish** P1, P2, P4 — prime, tan, black bezel band, badge.
8. **Assemble** and bench-test: thermal soak, swing travel, hold-open, button feel.
9. **ME-5** hinge and stay; then **IN-1** install.

Step 3 is not optional. A cardboard door costs an hour and catches every
proportion mistake that would otherwise arrive as finished, painted metal.

---

**Fabrication package:** [`fab/`](fab/) — order sheet, DXFs, previews and the
parametric generator. Built against assumed numbers; see its §6 release gate.

*Tracks [ME-4](https://github.com/nickdnj/3280-kiosk/issues/29). Revised when
ME-1 and EL-5 data land.*

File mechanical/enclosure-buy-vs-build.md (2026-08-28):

# Buy-and-Modify vs. Fabricate — Door Enclosure

> ## ⛔ SUPERSEDED FOR REV 1
> The kiosk is no longer a replacement door integrated into the cabinet. It is a
> **self-contained enclosure surface-mounted on the closed factory door** — see
> [`rev1-standalone-kiosk.md`](rev1-standalone-kiosk.md) and the
> [interactive design study](rev1-design-study.html).
> This document describes the **Rev 2** concept and is kept for provenance.
> Don't build from it.

> **Decision status: OPEN, gated on C1.** Both paths are live. The measurement
> that picks between them is the same one that gates everything else — the
> closing clearance behind the cabinet's front face (ME-1 §C).
> **Do not buy anything before that number exists.**

**Reads with:** [`door-construction.md`](door-construction.md) ·
[`dimensions-assumed.md`](dimensions-assumed.md) §5 ·
[`measurement-checklist.md`](measurement-checklist.md) §C

---

## 1. The candidate category

Not digital-signage enclosures — those are built around a **cased** monitor and
run 4–8″ deep before you start, in a modern black-and-silver style that fights
the cabinet.

The right category is **shallow industrial / electrical enclosures**: nVent
Hoffman, Saginaw Control & Engineering, Rittal, Bud Industries, Hammond
Manufacturing. Single-door wall boxes, NEMA 1 or 12, sold in a wide size ladder
and finished in ANSI 61 gray — which sands and repaints to tan without argument.

What makes them interesting for us:

- A **hinged door and latch are already built in**, engineered and tested
- They ship with a **removable inner mounting panel** — exactly where an LCD,
  a controller board and a Pi want to live, and it comes out on the bench
- The body is rigid, square and already assembled
- Knockouts and gasketing are solved problems

---

## 2. The clever bit: run the box backwards

The obvious reading is "the enclosure's door becomes our door." That's wrong and
it wastes the product.

**Mount the enclosure body facing *into* the cabinet.** Then:

| Enclosure feature | Becomes |
|---|---|
| Solid back panel (now facing the visitor) | **The door face** — cut the screen window and button holes here |
| Inner mounting panel | **The LCD / controller / Pi carrier**, removable on the bench |
| Its own hinged, latched door (now facing rearward) | **Rear service access** — already hinged, already latched (MR16) |
| The body | The structural box and heatsink |

The whole enclosure then hinges on its left edge to the fixed frame. You get
MR16 service access and MR18 full enclosure for free, and the one surface you
have to modify is a **flat, solid, accessible back panel** — the easiest surface
on the whole product to work.

That's a real design, not a bodge.

---

## 3. What it does *not* save you

**The screen window.** You still have to cut a ~11.7 × 20.9″ rectangle to
±0.03″ with clean, square, deburred edges — and now you're cutting it in a
**formed box** instead of in flat sheet. That is harder, not easier: no laser
bed will take a 4″-deep box, so it becomes a jigsaw-and-file job, or it goes to
a router/mill with awkward workholding.

Avoiding that cut was the single biggest reason for outsourcing in the first
place. **Buying an enclosure does not avoid it.** It saves the forming, the box
assembly, and the hinge/latch engineering — all of which were the *easy* parts.

---

## 4. What it costs

### Depth — the gating cost

| Path | Door depth |
|---|---|
| Custom fabrication (as drawn) | **2.5″** |
| Shallowest common off-the-shelf enclosure | **~4″** |
| Typical off-the-shelf | 6–8″ |

Rule from [`dimensions-assumed.md`](dimensions-assumed.md) §5: **C1 ≥ door depth
+ 0.5″.**

| Measured C1 | What it means |
|---|---|
| **< 3.0″** | Custom fab only, and the escalation ladder applies |
| **3.0″ – 4.5″** | Custom fab only. Off-the-shelf won't close |
| **≥ 4.5″** | A 4″ enclosure fits — buy-and-modify is genuinely on the table |
| **≥ 6.5″** | The whole size ladder opens up; pick on proportions, not depth |

### Weight — disqualifying for steel

A 30 × 16 × 4″ enclosure in 16 ga steel (0.060″) has roughly 9.2 sq ft of skin at
about 2.45 lb/sq ft — **~23 lb of empty box**, before the door, mounting panel,
LCD, Pi and buttons. Call it 35–40 lb assembled.

Against a design budget of 14.5 lb and ~100 in-lb at the hinge, a steel box lands
near **250 in-lb** — cantilevered off a mount that is not allowed to put a single
hole in a museum artifact.

**Steel is out.** If this path is taken it has to be an **aluminum** enclosure
(~1/3 the weight, ~10–12 lb) — a smaller part of the catalogue and more
expensive, but the only version that's safe on a reversible mount.

Fiberglass and polycarbonate boxes are light and cheap but give up the thermal
conduction path (§5 of the build spec) and read wrong next to painted sheet
metal.

### Proportions

Standard sizes won't be 14.5 × 30. The nearest common footprints — 16 × 30,
16 × 24, 12 × 24 — change how much card cage stays visible around the door, which
is a stated design value (MR3). Not fatal, but it's a real aesthetic cost and it
has to be re-checked against the measured opening.

---

## 5. The hybrid — what I'd actually recommend if C1 allows

**Buy the box. Laser-cut only the face.**

- Buy a shallow **aluminum** enclosure for the body, hinge, latch, rear access and
  inner mounting panel
- Have **one flat part** cut — a face plate with the screen window, button holes
  and fixings — sized to the enclosure's actual back panel
- Bond or fasten the face plate over the enclosure's back panel, or replace that
  panel entirely if it's removable

This keeps the hardest operation (the window) on a laser bed where it belongs,
buys everything else off a shelf, and drops the fab package from four parts to
one flat plate — the cheapest, fastest, lowest-risk part to order.

It also survives failure gracefully: if the enclosure turns out wrong, you've
lost a box, not a design.

---

## 6. Honest summary

| | Custom fab (as drawn) | Buy + modify |
|---|---|---|
| Depth | **2.5″** | 4″ minimum |
| Weight | ~14.5 lb | ~10–12 lb alu, 35–40 lb steel ❌ |
| Proportions | Exactly as designed | Whatever the catalogue offers |
| Hinge / latch / access | Design + build it | **Already solved** |
| Screen window | **Lasered, flat, perfect** | Hand-cut in a formed box |
| Finish | Prime + tan | Prime + tan (same) |
| Thermal path | Designed in | Good, if aluminum |
| Lead time | ~1 week | Off the shelf |
| Risk concentration | The order | The window cut |

Neither is clearly better. **Custom fab wins on depth, proportions and the
quality of the hard cut. Buying wins on hinge/latch/access engineering and lead
time.** The hybrid in §5 takes the better half of each.

---

## 7. Before Wednesday

**Buy nothing.** The decision needs C1.

Useful now, costs nothing:

- [ ] Price shallow **aluminum** single-door enclosures near 14–16″ W × 24–30″ H
      × 4″ D. Note the shallowest depth anyone offers in aluminum
- [ ] Confirm whether their back panel is removable or welded — removable is
      worth a lot
- [ ] Check the secondary market; industrial enclosures turn up cheap used
- [ ] Ask CDL (question 7 of the
      [drawing package](fab/DRAWING-PACKAGE.md)) whether they'd rather cut a
      window in a box or bend a tray — their answer may decide this for us
- [ ] **Look for a suitable enclosure in the warehouse on Wednesday** — salvage
      beats buying, and an aluminum box on a shelf changes the maths

Then on Wednesday, C1 decides it. Take the §4 table with you.

---

## 8. Lead candidate — Leviton STRUCTURED MEDIA enclosure

Verified against the manufacturer spec sheet (Leviton B26 SS1431, rev. Feb 2026).
This is a **low-voltage structured-wiring can**, not a breaker panel — which
removes the weight, finish and identity problems of a load center in one move.

### The parts

| Part No. | Description | Size |
|---|---|---|
| **47605-28N** | 28″ **enclosure only** ← the one we want | **28.0″ H × 14.30″ W × 3.85″ D** |
| 47605-28W | Same can + flush-mount cover | 29.32 × 15.62 × 3.85 |
| **47605-28S** | 28″ **Premium Vented Hinged Door** | 29.32 × 15.62 × 0.25 |
| 47605-28D | 28″ Economy Hinged Door | 29.32 × 15.62 × 0.25 |
| 47605-F28 | 28″ Flush-Mount Cover (flat panel) | 29.32 × 15.62 × 0.20 |
| 47612-28B | **2″ depth extender bracket** | — |
| 5L000-L0K | Lock & key | — |

42″ versions exist (47605-42x) — too tall for us.

### Why it fits

| | Our design | 47605-28N | |
|---|---|---|---|
| Width | 14.50″ | **14.30″** | ✅ essentially exact |
| Height | 30.00″ | **28.00″** | ✅ 2″ short — absorbs into the layout |
| Depth | 2.50″ | 3.85″ | ⚠️ needs **C1 ≥ 4.35″** |
| Material | 0.080″ alu | **20-ga white powder-coated steel** | ✅ paints normally |
| Weight | ~14.5 lb | ~13.6 lb can + vented door | ✅ **on budget** |

**The face layout fits the 28″ can almost exactly.** Window 20.86 + reveal 0.60 +
button plate 4.00 = 25.46, leaving ~1.3″ top and ~1.2″ bottom margin in 28.0″.
Width: an 11.71″ window in 14.30″ leaves 1.30″ each side against the 1.40″ we drew.

### What it solves for free

- **Ventilated hinged door** (47605-28S) — MR14 + MR16 off the shelf. Leviton
  explicitly recommends it "when using active equipment inside enclosure," so
  powered gear in this box is an anticipated use, not a hack.
- **20-gauge, not breaker-panel gauge** — this is why the weight works. A load
  center of the same footprint runs ~26 lb because it has to carry bus bars.
- **White powder-coat**, not galvanised — ordinary primer adheres.
- **No electrical identity problem.** A structured-media can is a data enclosure.
  Nobody mistakes it for a live panel.
- Knockouts and self-healing grommets on top/bottom/sides for the hinge cable.
- **2″ extender bracket** if we ever need more depth; **lock and key** if the
  museum wants the rear secured.

### The catch, and the fix

The can's back panel carries a **grid of module-mounting holes**. Running the box
backwards puts that grid on the visitor-facing surface.

**Fix — and it is the §5 hybrid exactly:** laser-cut **P1 only**, resized to
14.30 × 28.0, and fasten it over the can's back. It hides the hole grid, carries
the exact window and button holes, and takes the tan finish. The fab package
drops from four parts to **one flat plate**, and P2/P4 disappear entirely.

### ⚠️ Reject the plastic ones

Legrand/On-Q's 30″ enclosures (ENP3050 and similar) are **plastic**. No thermal
conduction path for the Pi (§5 of the build spec), and they won't read right next
to painted sheet metal. Leviton's 47605/49605 series is steel — check the
material on every listing.

---

## 8. Where to browse

### What to filter on

> **Aluminium** · **14–16″ W × 24–30″ H** · **depth ≤ 4″** · hinged door ·
> removable back panel · NEMA 1 or 12 (indoor — no need to pay for 4/4X)

Depth is the filter that kills most results. Sort by it first. And **check the
material on every hit** — the catalogues are overwhelmingly steel, and steel is
disqualified on weight (§4).

### Best for filtering by actual dimensions

| Site | Why |
|---|---|
| [digikey.com](https://www.digikey.com) | Parametric search on **exact L × W × H and material** — the fastest way to find out whether a shallow aluminium box in our size even exists. Carries Hammond and Bud. |
| [mouser.com](https://www.mouser.com) | Same parametric approach, different stock |
| [mcmaster.com](https://www.mcmaster.com) | Browse by dimension, dimensioned drawings on every page, CAD downloads, ships next day |

### General industrial suppliers

| Site | Why |
|---|---|
| [automationdirect.com](https://www.automationdirect.com) | Clear specs, good prices, honest photos |
| [zoro.com](https://www.zoro.com) | Consumer-friendly front end on industrial stock |
| [grainger.com](https://www.grainger.com) | Widest catalogue, priced accordingly |

### Manufacturer catalogues — best drawings

| Site | Why |
|---|---|
| [hammfg.com](https://www.hammfg.com) | Hammond. Deep range of small/shallow boxes, aluminium options, excellent drawings |
| [hoffman.nvent.com](https://hoffman.nvent.com) | Hoffman. The industry default |
| [saginawcontrol.com](https://www.saginawcontrol.com) | Often cheaper than Hoffman for the same box |
| [budind.com](https://www.budind.com) | Bud Industries |
| [polycase.com](https://www.polycase.com) | Sells direct **and offers CNC modification of what they sell** — they could cut our window |

### A third path — custom one-off enclosure houses

Worth pricing, because budget is not a constraint (PRD §15) and these remove the
hard cut entirely:

| Site | Why |
|---|---|
| [protocase.com](https://www.protocase.com) | **Custom enclosures, quantity of one, ~2–3 day turnaround, finished and painted.** Send our drawings and get back the actual box. Removes the window-cut problem completely. |
| [frontpanelexpress.com](https://www.frontpanelexpress.com) | Machined aluminium **front panels** with cutouts and engraving, one-offs, free design software. A direct fit for the §5 hybrid — buy a box, get P1 made here. |

### Laser cutting (already in the fab package)

[sendcutsend.com](https://www.sendcutsend.com) ·
[oshcut.com](https://www.oshcut.com) · [ponoko.com](https://www.ponoko.com)

### Secondary market

eBay and industrial surplus dealers — search *"aluminum electrical enclosure
hinged"*. Industrial enclosures turn up cheap and undamaged, and it beats buying
new on the salvage-first rule. **And check the warehouse first.**

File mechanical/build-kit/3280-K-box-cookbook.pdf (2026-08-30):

3280-K

## BOX — BUILD COOKBOOK

CONCEPT — NOT A SHIPPED PRODUCT

15 × 30 × 3-5/8"

## 9 crosscuts · no rips

≈ 24 lb

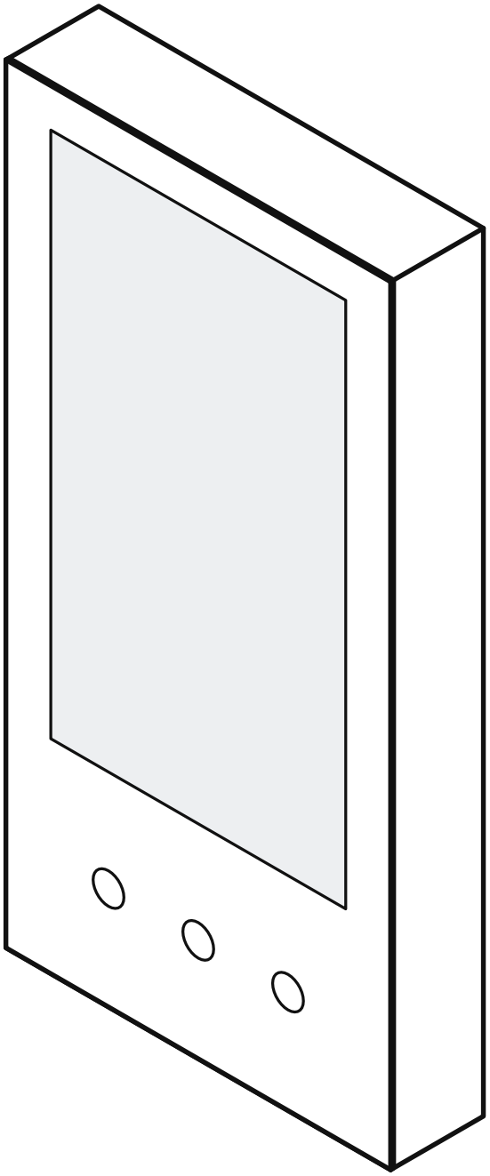
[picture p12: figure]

!

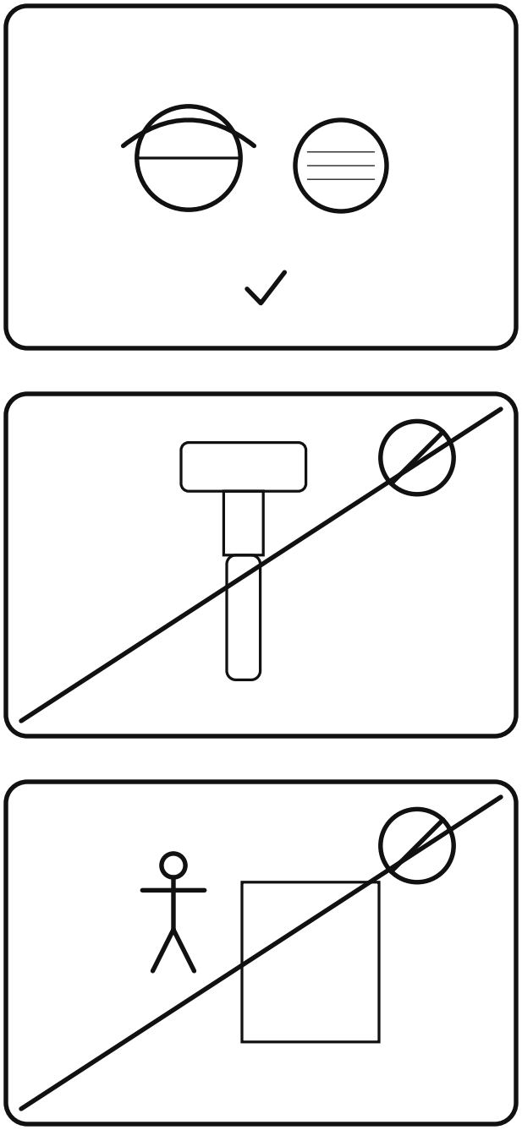
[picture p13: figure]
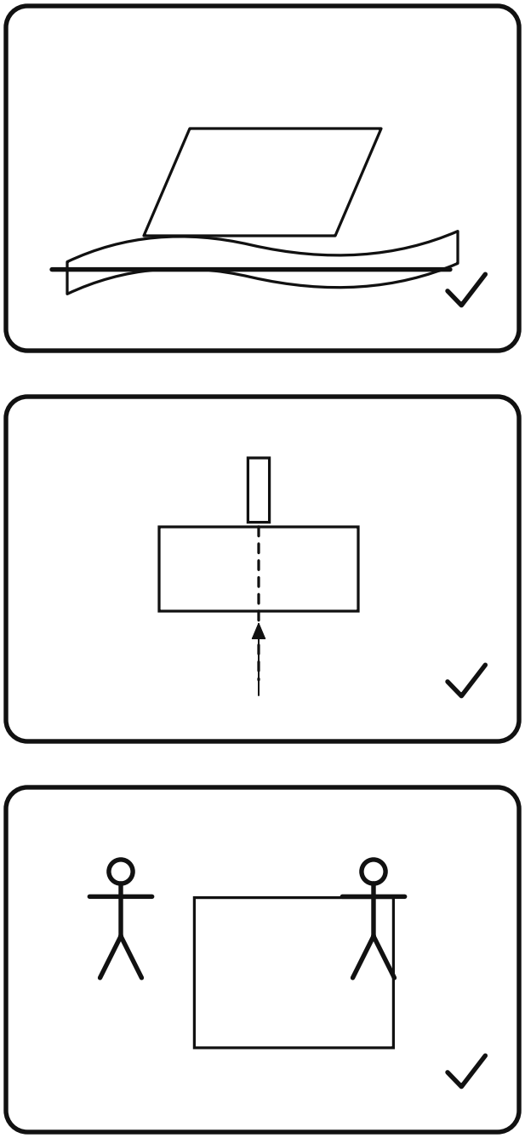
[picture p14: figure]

0

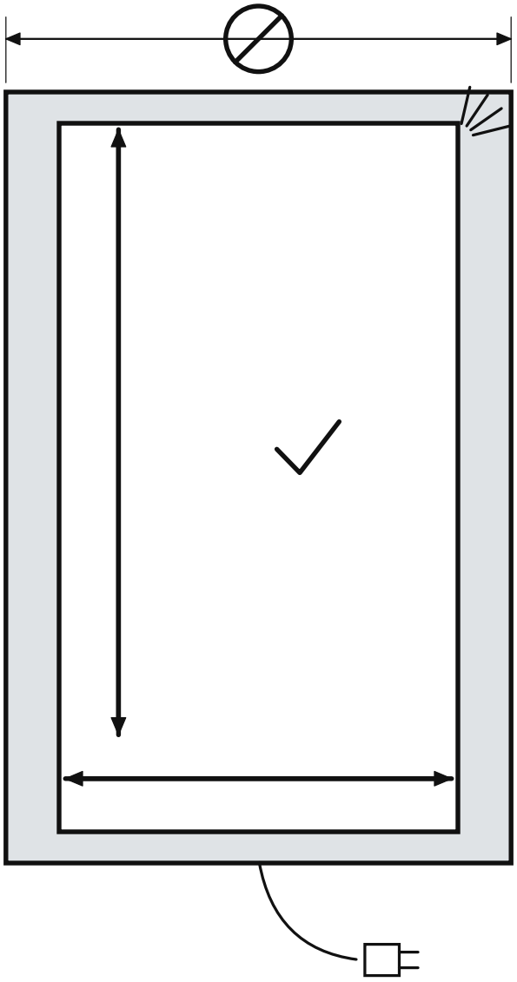
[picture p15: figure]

− 3/16 | =
− 3/16 | =

A

1×4 × 8 ft

914681 · .750 × 3.5
×2

1×3 × 8 ft

914649 · .750 × 2.5
×3

P4

P10

### ½" MDF 2 × 4

109097

### HOME DEPOT CUTS THIS

P4 13-1/4 × 28-1/4
P10 4 × 3

you never handle
a sheet good

B

2

3-1/2 x 30
1x4 ×2

3

3-1/2 x 13-1/2
1x4 ×2

7

2-1/2 x 13-1/2
1x3 ×1

8

2-1/2 x 28-1/2
1x3 ×2

9

2-1/2 x 28-1/2
1x3 ×2

4

13-1/4 x 28-1/4
MDF ×1

10

4 x 3
MDF ×1

1

15 x 30 (ordered)
ACM ×1

C

F1 | WOOD SCREW, #6 x 1-1/4, FLAT HEAD
| box, rail, cleats, rails. Pilot 7/64.

×40

F2 | INSERT, THREADED, #8-32, BRASS, FOR WOOD
| 15 front + 6 rear. Drill 3/8. EPOXY.

×21

F3 | SCREW, #8-32 x 1/2, BUTTON HEAD, BLACK
| holds P1. Pin-torx if you want it tamper-resistant.

×15

F4 | THUMBSCREW, #8-32 x 1/2
| holds P4. Tool-free service.

×6

F5 | BOLT, M4 x 12 + FLAT WASHER
| monitor to P9, VESA 100.

×4

F6 | SWITCH, 30 mm ANTI-VANDAL, MOM. SPST-NO
| VERIFY the 30.5 cutout before P1 is cut.

×3

F7 | INLET, IEC C14, PANEL MOUNT, FUSED
| lower cavity, in the back or the bottom board.

×1

F8 | FOAM TAPE, NEOPRENE, BLACK, 1/4 x 3/16, 10 ft
| light seal on the BACK of P1. 65" used.

×1

D

G1 | WOOD GLUE, PVA (Titebond II)
| every wood joint
G2 | EPOXY, 5 MINUTE, 2-PART
| the 21 inserts, nothing else
G3 | SANDING SEALER or PRIMER
| ALL SIX FACES of every part
G4 | PAINT, SATIN BLACK
| outside + visible edges

## ALL SIX FACES

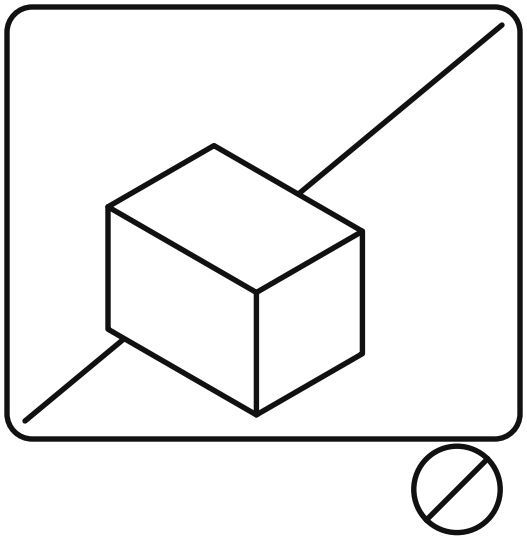
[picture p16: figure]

E

1

30

CUT

BLADE HERE

WASTE

2

1×4 #1 — 4 cuts

P2 | P2 | P3 | P3

1×3 #1 — 3 cuts

P8 | P8 | P9

1×3 #2 — 2 cuts

P9 | P7

# 9 CUTS

### CUT P2 FIRST DRY-FIT MEASURE THE REAL CAVITY

then cut everything
else to what you
measured

3

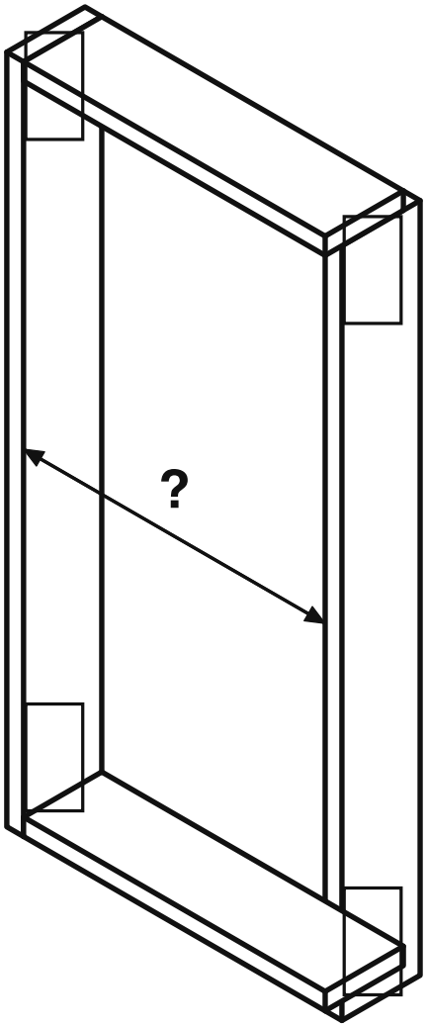
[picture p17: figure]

### CLAMP · MEASURE · THEN CUT

4

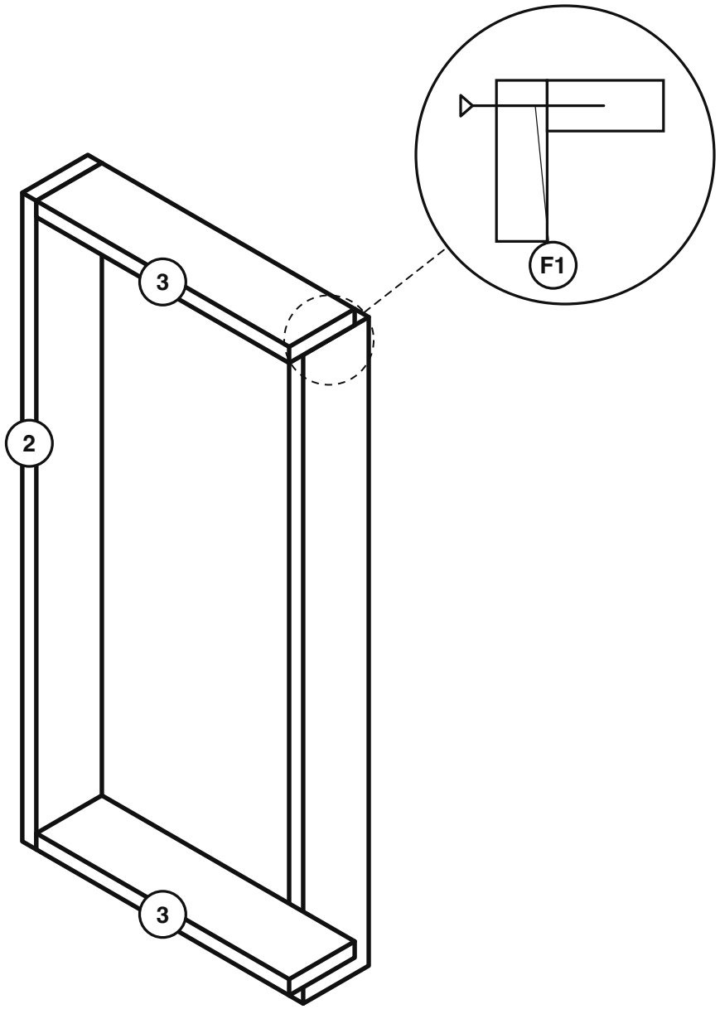
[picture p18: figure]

### PILOT 7/64 · GLUE · SCREW

5

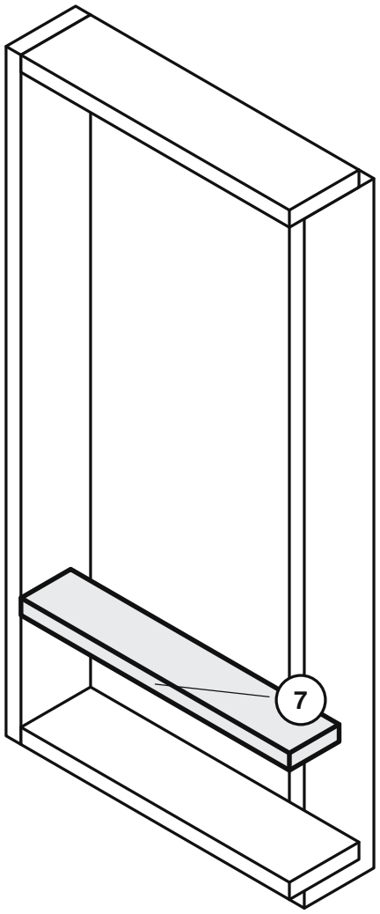
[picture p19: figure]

6

### FRONT FLUSH

6

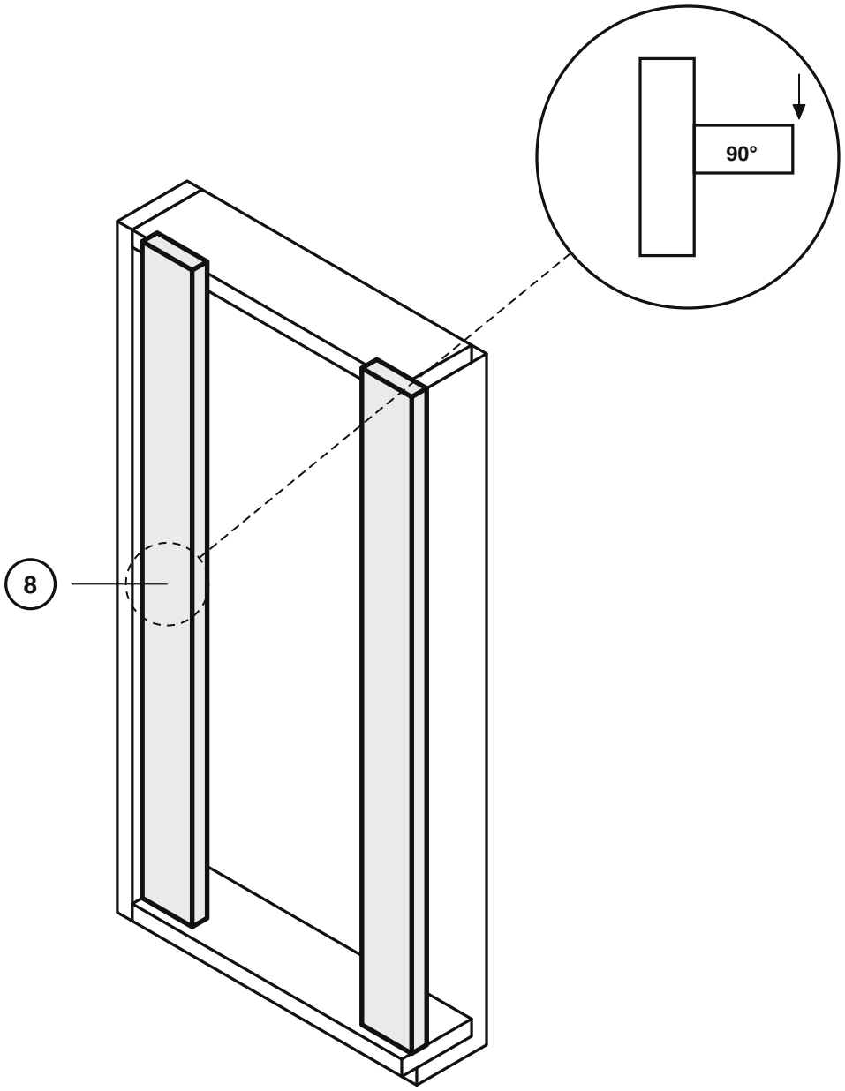
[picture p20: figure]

### TURNED FLAT — 3/4 DEEP, BEHIND THE SCREEN

7

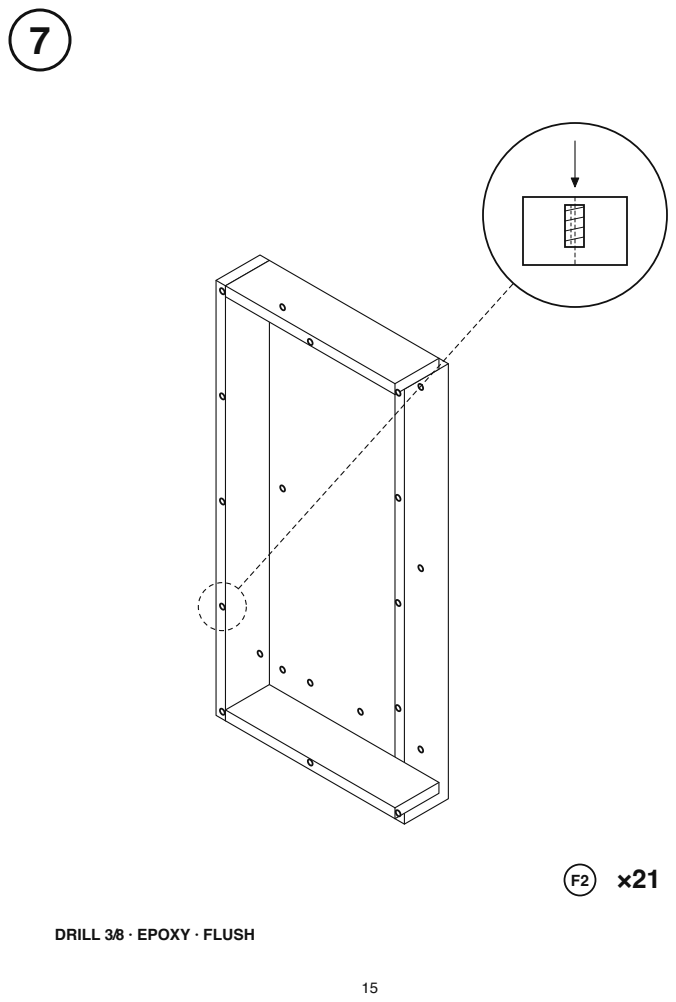
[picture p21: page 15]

DRILL 3/8 · EPOXY · FLUSH

8

### VESA 100

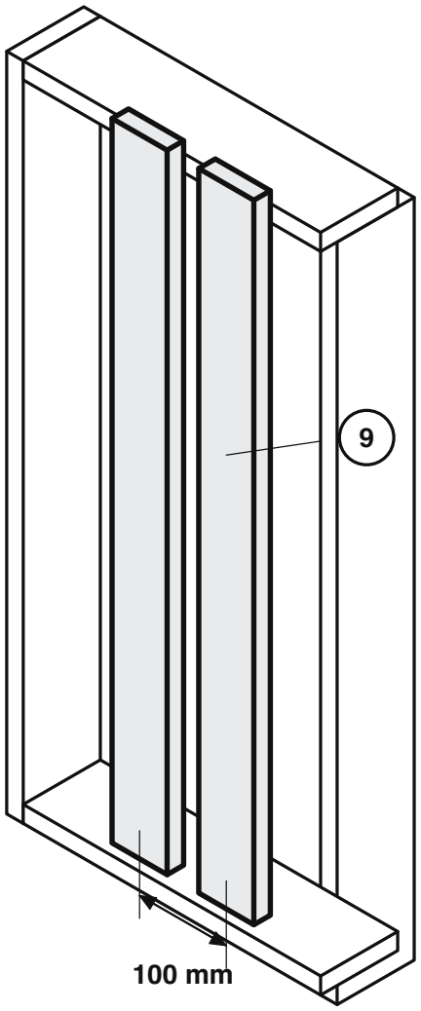
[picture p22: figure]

9

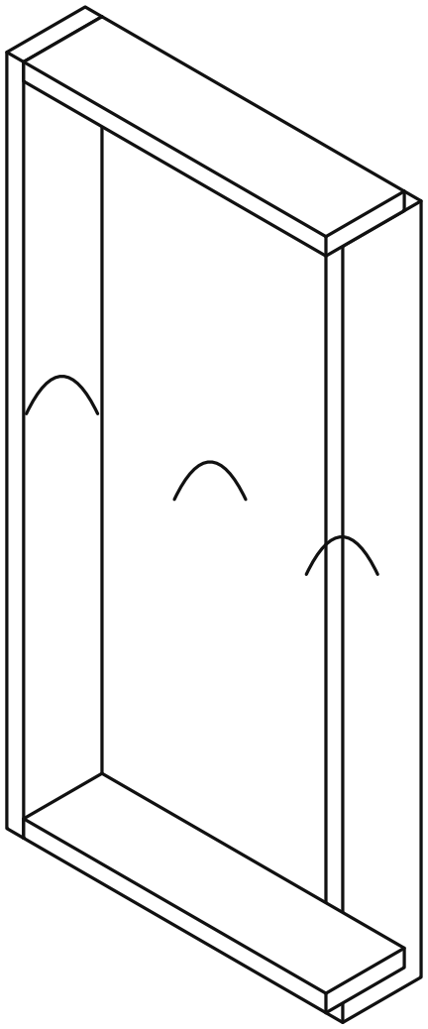
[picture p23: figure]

### SEAL ALL SIX FACES — INSIDE TOO

10

F5 ×4

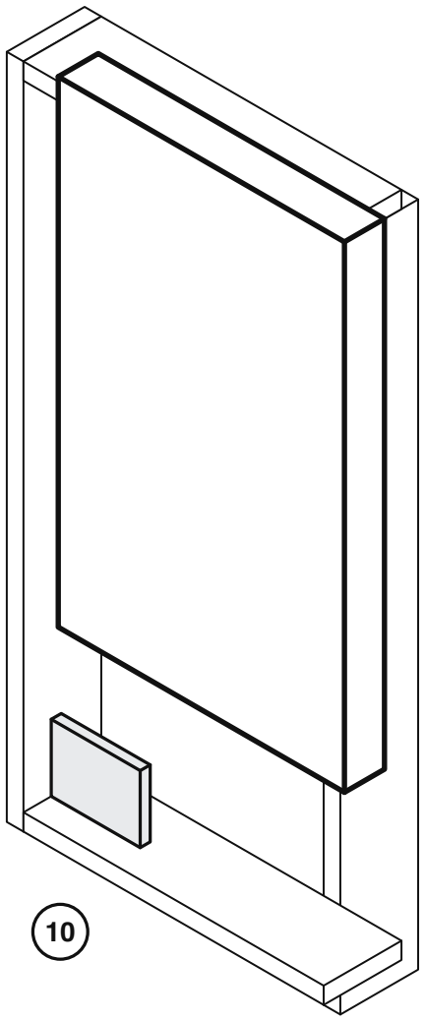
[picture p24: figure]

### MONITOR ONTO THE RAILS

11

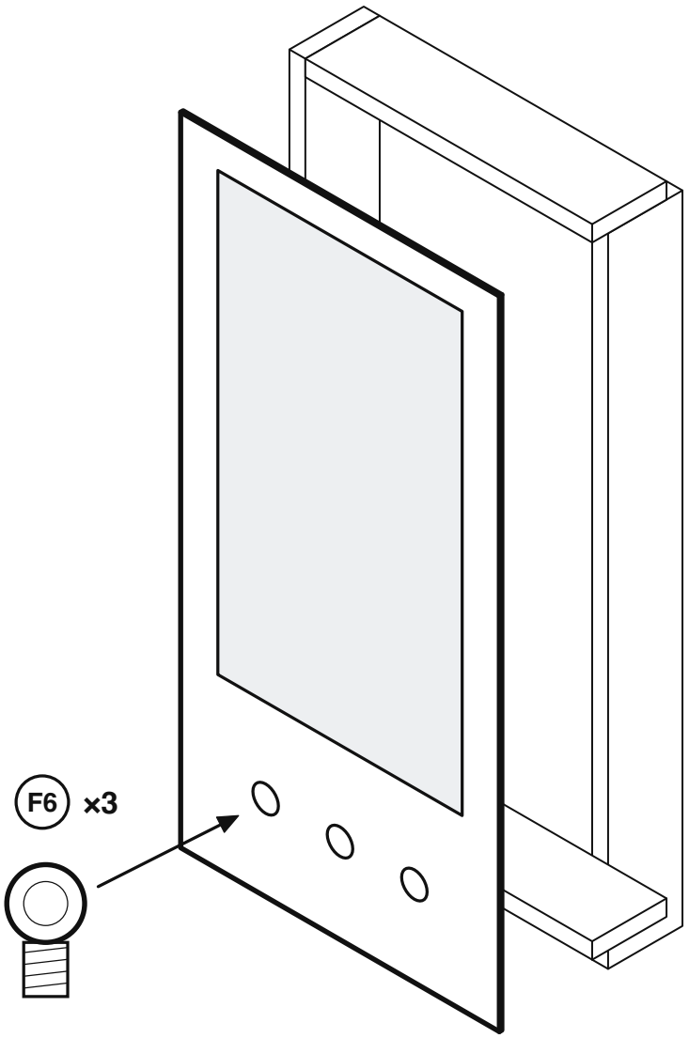
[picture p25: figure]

### SWITCHES FIRST, THEN WIRE

12

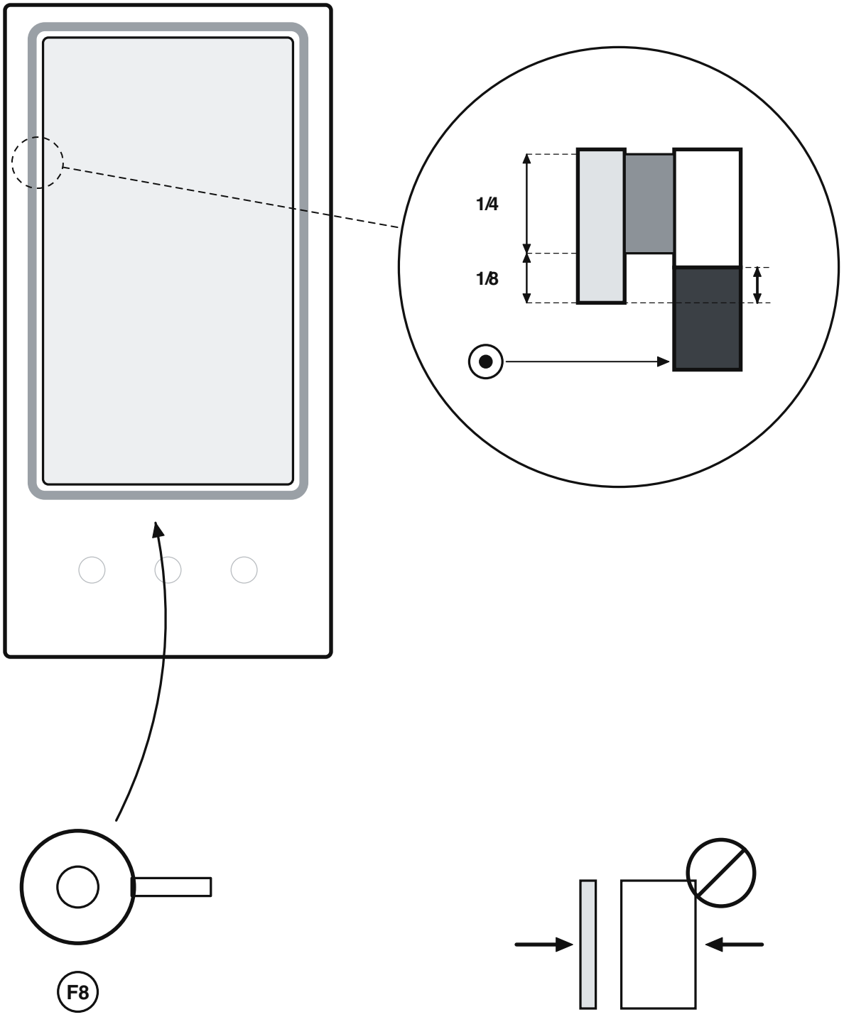
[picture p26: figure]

13

F3 | ×15
F4 | ×6

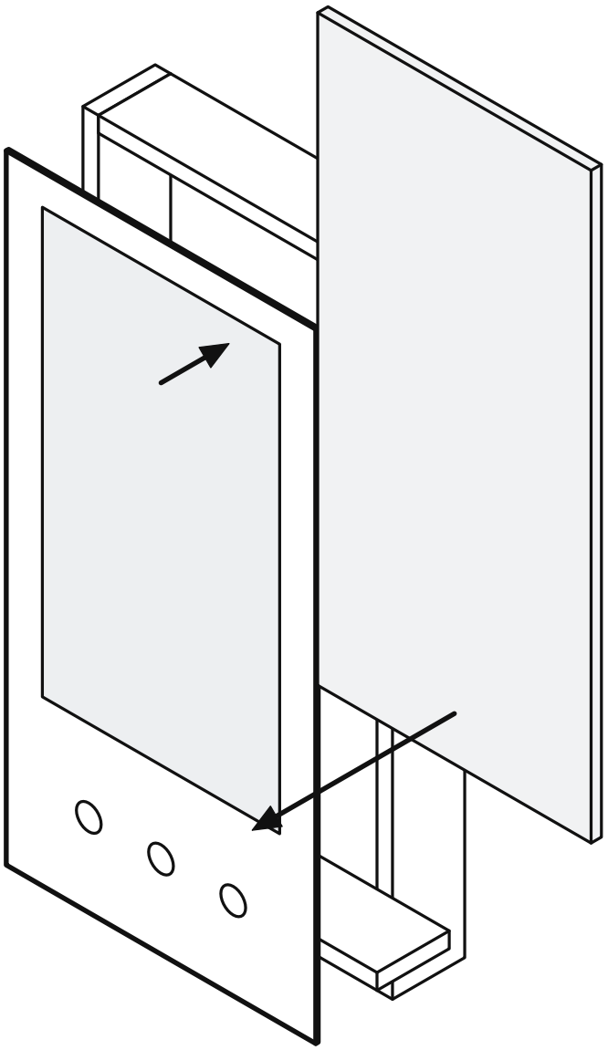
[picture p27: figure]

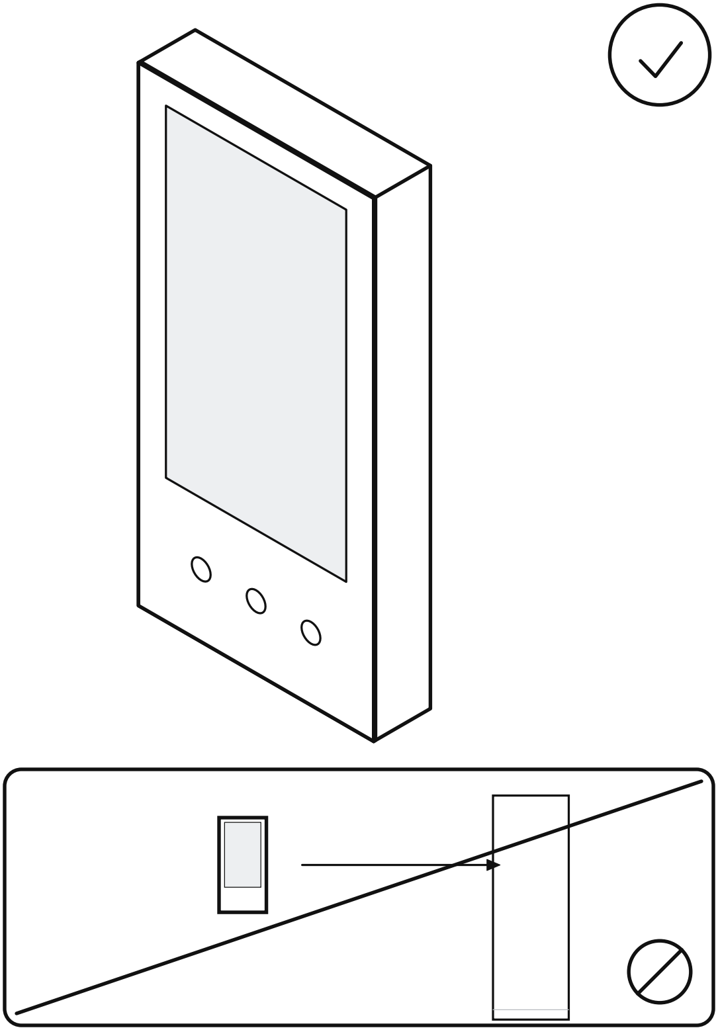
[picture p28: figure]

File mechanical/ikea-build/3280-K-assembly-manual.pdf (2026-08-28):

3280-K

## KIOSK ENCLOSURE

CONCEPT — NOT A SHIPPED PRODUCT

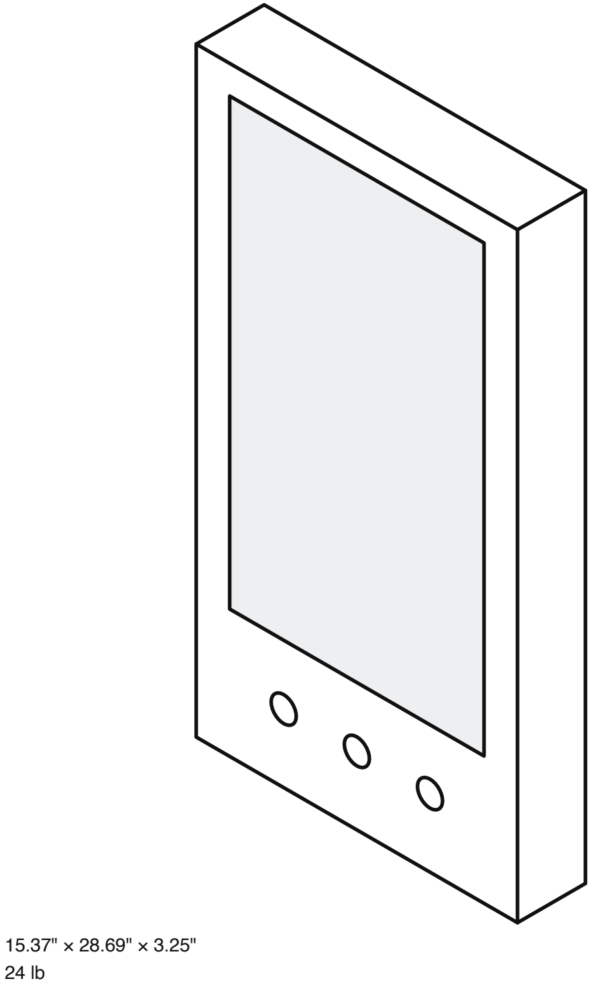
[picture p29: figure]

!

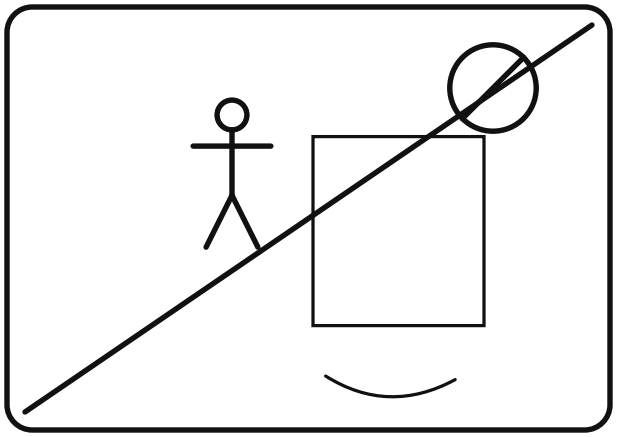
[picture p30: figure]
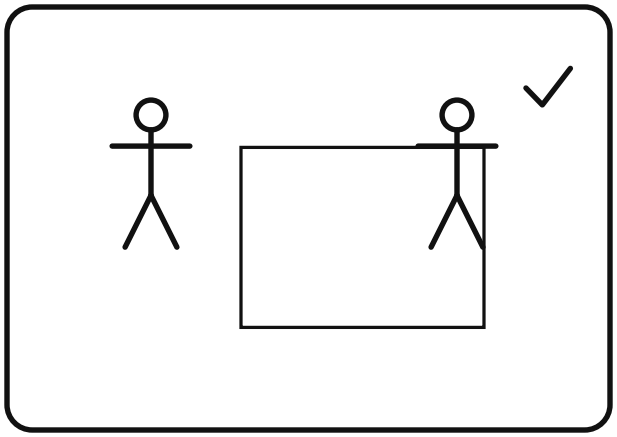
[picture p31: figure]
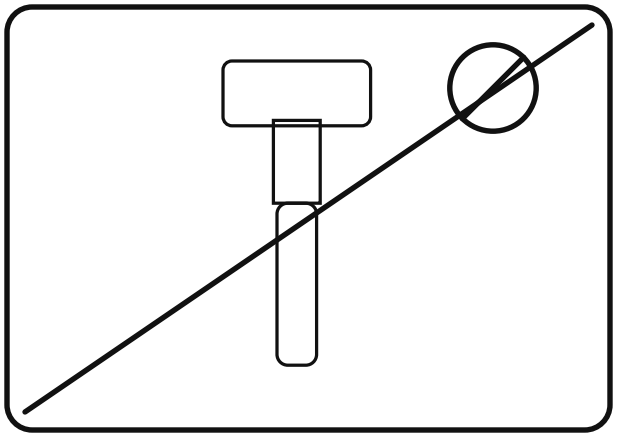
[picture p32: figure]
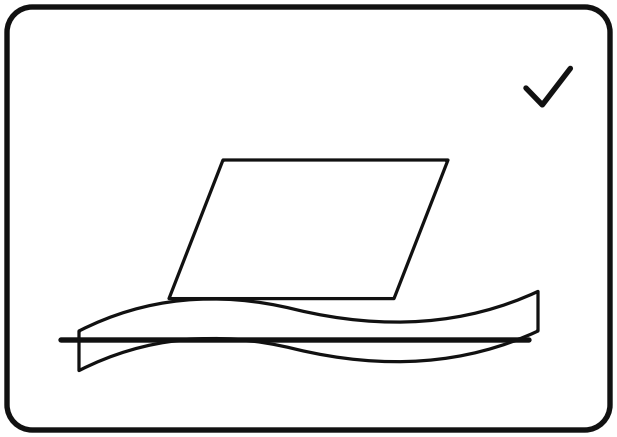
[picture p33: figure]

A

2

3.132 x 28.690 x 0.750 ×2

(A)

3

3.132 x 13.870 x 0.750 ×2

(A)

4

13.670 x 27.090 x 0.750 ×1

(C)

5 0.750 sq x 27.190 ×2

(B)

6 0.750 sq x 12.370 ×2

(B)
7 0.750 sq x 12.370 ×1

(B)
8 0.750 sq x 27.190 ×2

(B)
9 0.750 sq x 12.370 ×2

(B)

10

(B) 4.000 x 2.900 x 0.750 ×1

B

IVAR 83×30

303.181.63
$12.00 ×2

IVAR 83×30

303.181.63
$12.00 ×2

IVAR 83×50

803.181.65
$15.00 ×1

FIXA / TRIXIG

felt pads, ×20
$39.00

C

SHELF A IVAR 83×30 | 32.625" × 11.75" × 0.75"

K2

K2

K3 | K3
SHELF B IVAR 83×30 | 32.625" × 11.75" × 0.75"
K10 | K5
| K5
| K8
| K8
K6 | K6
K7 | K9
K9

D

SHELF C IVAR 83×50 | 32.625" × 19.625" × 0.75"

K4

GRAIN

E

H1 | INSERT, THREADED, #8-32, FOR WOOD | ×21
H2 | SCREW, #8-32 x 1/2, BUTTON HEAD, BLACK | ×15
H3 | THUMBSCREW / QUARTER-TURN, #8-32 | ×6
H4 | BOLT, M4 x 12 + WASHER | ×4
H5 | STANDOFF, M4 M-F, 12 mm, NYLON | ×4
H6 | SWITCH, 30 mm ANTI-VANDAL, MOM. SPST-NO | ×3
H7 | INLET, IEC C14, PANEL MOUNT, FUSED | ×1
H8 | SCREW, WOOD, #6 x 1-1/4 | ×40
H9 | GLUE, PVA, YELLOW | ×1

F

1

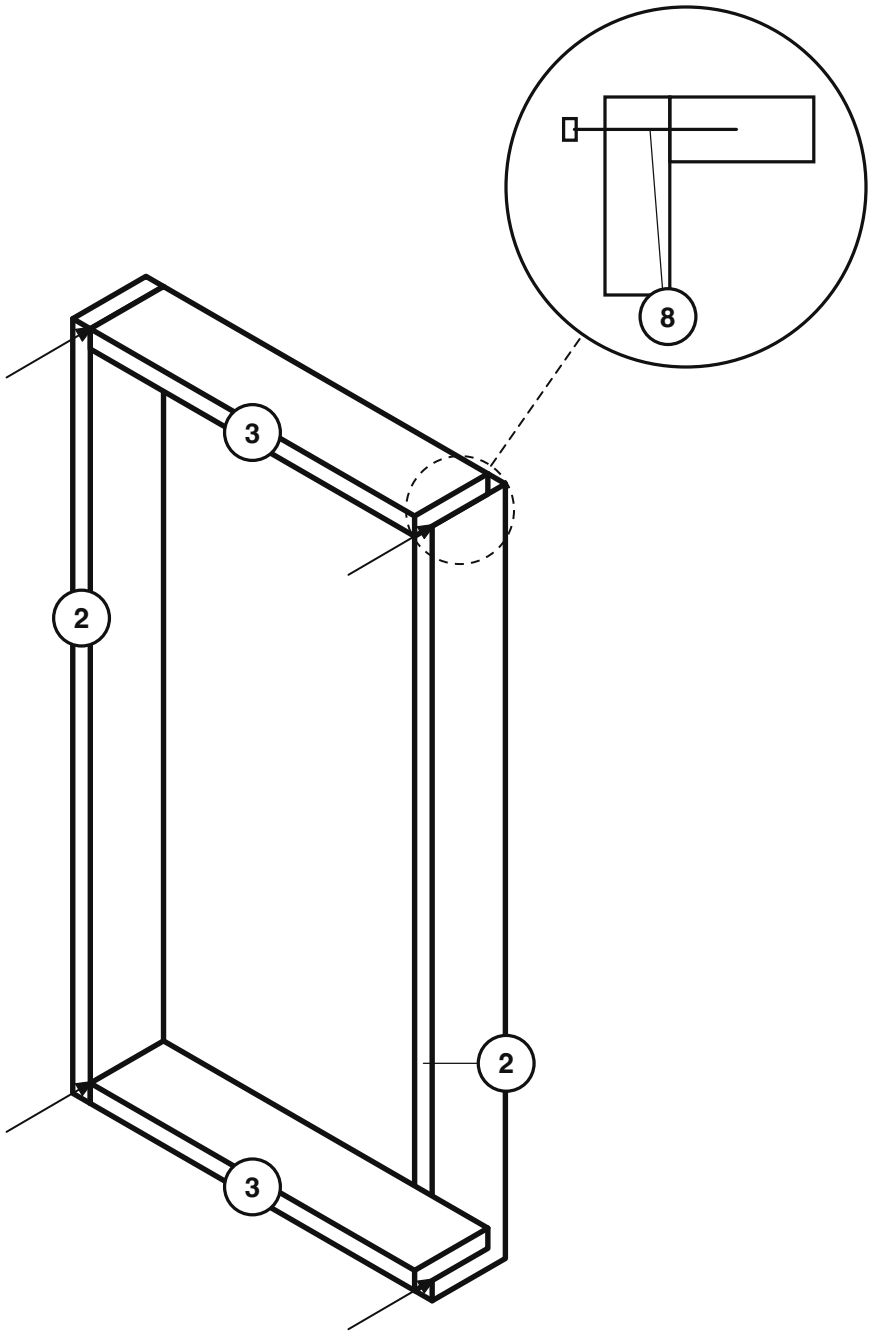
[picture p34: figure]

2

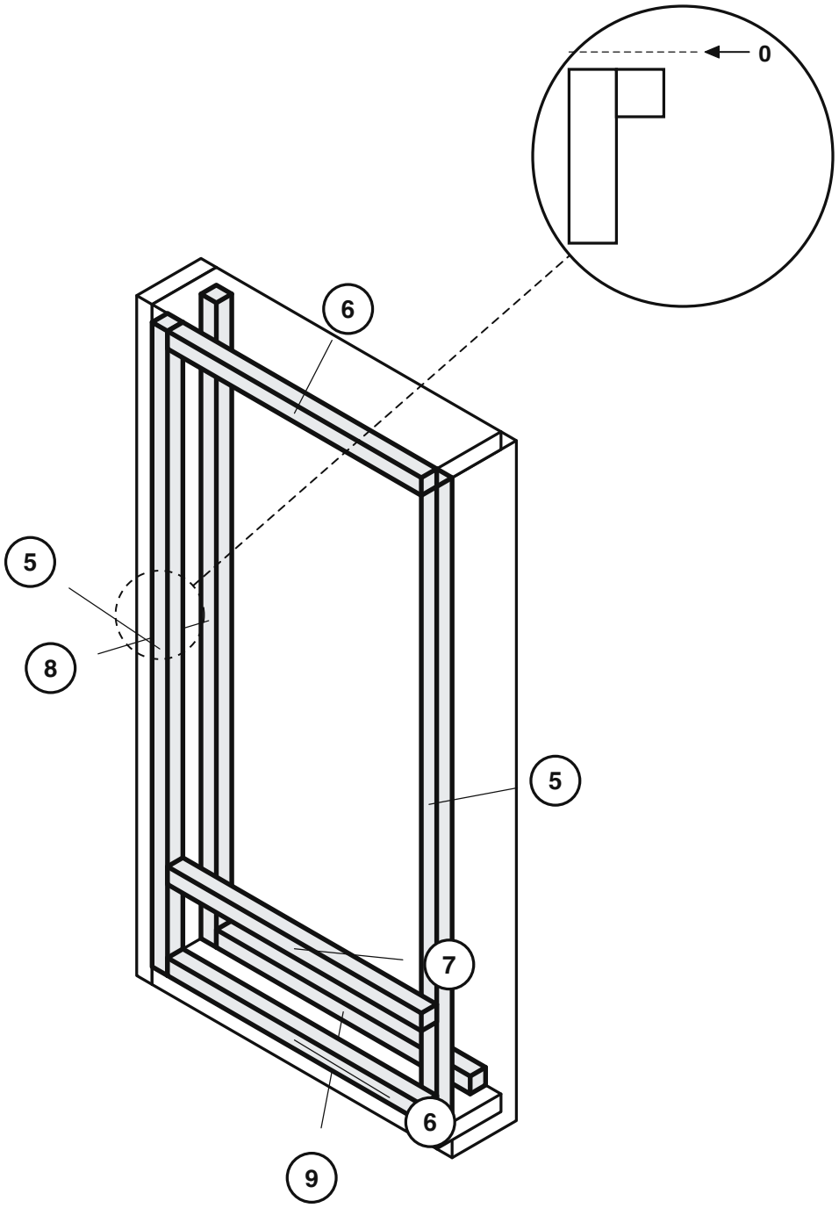
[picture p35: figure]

3

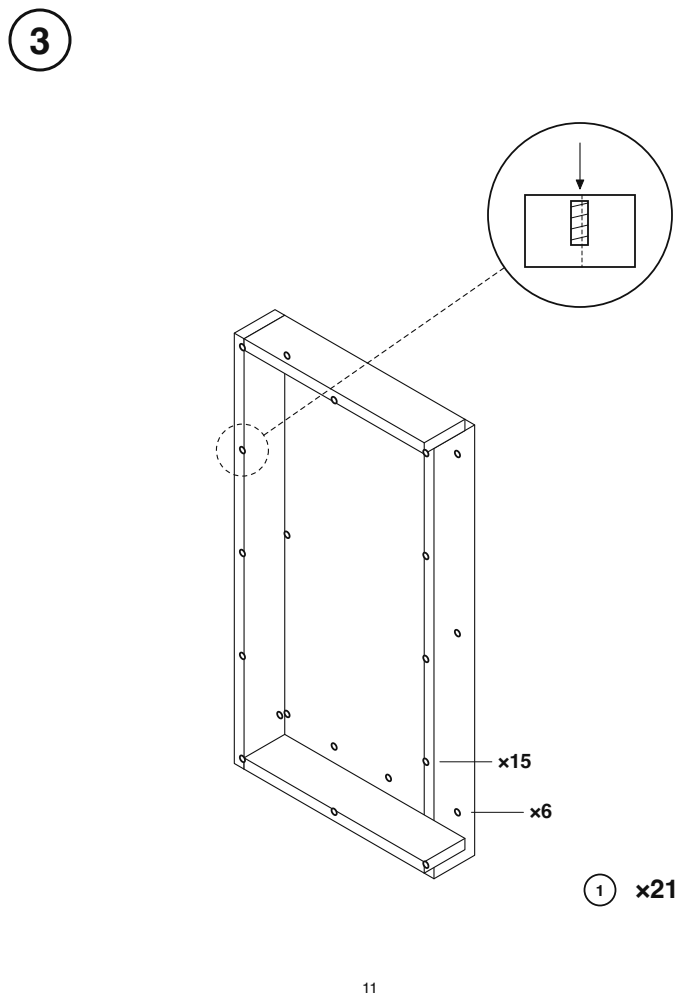
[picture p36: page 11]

4

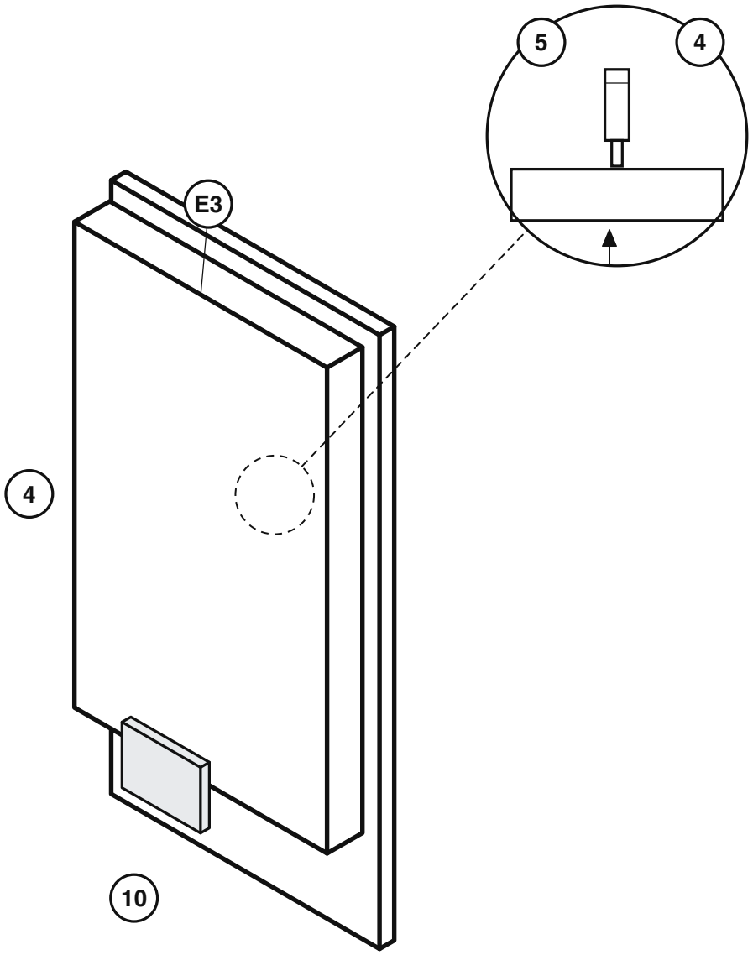
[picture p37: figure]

5

3 ×6

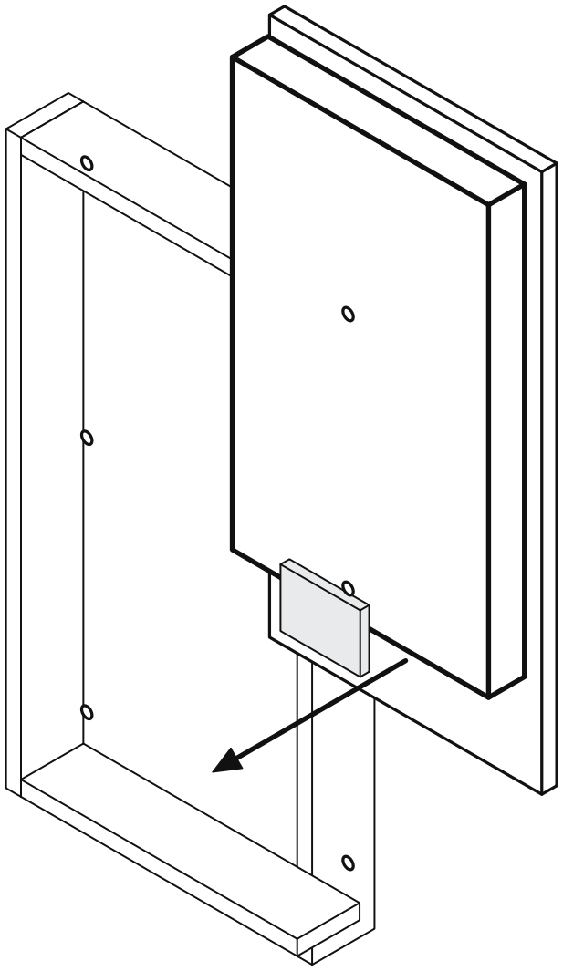
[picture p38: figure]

6

2 ×15

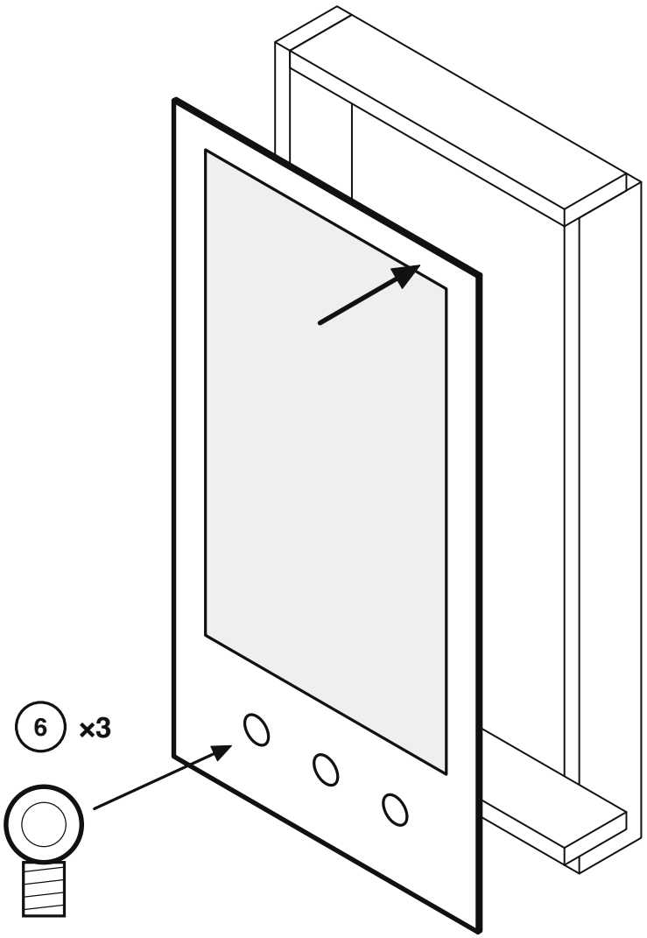
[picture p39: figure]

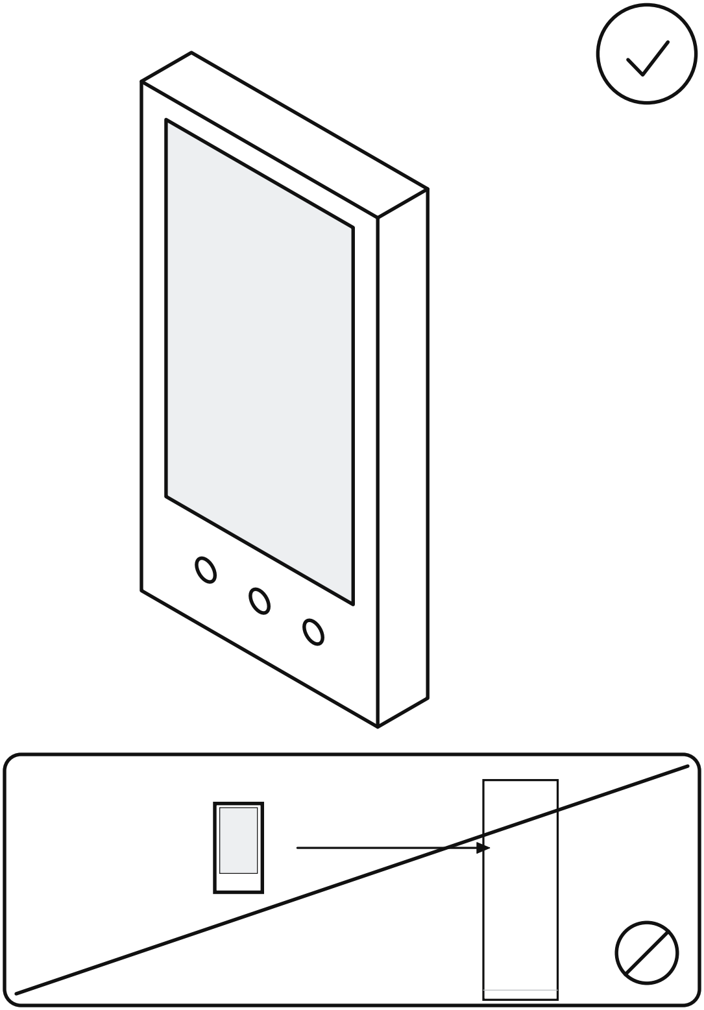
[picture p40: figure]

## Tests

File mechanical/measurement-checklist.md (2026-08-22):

# ME-1 Field Sheet — Measuring the 3280

> **Print this, or open it on your phone.** Fill the blanks in place, commit the
> filled copy, and [`dimensions-assumed.md`](dimensions-assumed.md) gets rewritten
> against it. Tracks [issue #26](https://github.com/nickdnj/3280-kiosk/issues/26).

**Date:** ______________  **Measured by:** ______________  **Present:** ______________

**Rule:** every number in inches to the nearest 1/16″. Where a dimension could
vary along its run (openings, clearances), measure it **three times — top,
middle, bottom** — and record all three. Design goes to the smallest.

---

## Take this with you

- [ ] Tape measure (25′) **and** a folding rule (rigid, for inside depths)
- [ ] Calipers (panel thickness, lip thickness, fastener diameters)
- [ ] Flashlight / headlamp
- [ ] Painter's tape + marker (label reference points, mark datum)
- [ ] **A rack screw + cage nut sample** to test-fit the rail holes
- [ ] Thread gauge or a few known screws (10-32, M6, 1/4-20)
- [ ] Phone (photos — see §G) + this checklist
- [ ] Small square or angle finder
- [ ] Bag + labels for any fastener that comes out

---

## A. Cabinet overall

| Ref | Measurement | Assumed | Measured |
|---|---|---|---|
| A1 | Overall width (outside, widest point) | 23.0″ | __________ |
| A2 | Overall height including feet | 69.5″ | __________ |
| A3 | Overall depth (front face → rear-most point) | 26–36″ | __________ |
| A4 | Top cap / header height | 4.5″ | __________ |
| A5 | Plinth + feet height (floor → opening bottom) | 8.0″ | __________ |
| A6 | Front opening **clear width** — top / mid / btm | 19.0″ | ____ / ____ / ____ |
| A7 | Front opening **clear height** — left / right | 57.0″ | ______ / ______ |
| A8 | Opening bottom, AFF | 8.0″ | __________ |
| A9 | Opening top, AFF | 65.0″ | __________ |
| A10 | Front frame face width — left / right / top / btm | ~2.0″ | ___/___/___/___ |
| A11 | Is the cabinet plumb and square? Note any rack/lean | — | __________ |

- [ ] Photographed straight-on with a tape measure in frame

---

## B. Rack rails — decides the mounting method

| Ref | Measurement | Answer |
|---|---|---|
| B1 | EIA-310 19″ rails present at the front? | ☐ Yes ☐ No |
| B2 | Rail face-to-face clear distance (expect 17.75″) | __________ |
| B3 | Hole pattern: ☐ square (cage nut) ☐ tapped 10-32 ☐ tapped M6 ☐ other: | __________ |
| B4 | Hole pitch — does a rack screw sample thread in? | ☐ Yes ☐ No |
| B5 | Rail setback from the cabinet front face plane | __________ |
| B6 | **Free (unoccupied) rail run** — from ______″ AFF to ______″ AFF | __________ |
| B7 | Is the card cage itself mounted to these rails? | ☐ Yes ☐ No |
| B8 | Rail condition — stripped holes, rust, bent sections? | __________ |

> **If B1 = No or B6 is too short for a 30″ door,** mount candidate A is out —
> fall through to B (straddle) or C (existing points).

- [ ] Photographed rail hole pattern close-up with tape for scale

---

## C. Closing clearance — ⚠ THE CRITICAL ONE

**C1 = cabinet front face plane → the frontmost object inside the opening.**
Board edges, connectors, ribbon cables, card-puller handles, anything.

| Ref | Measurement | Assumed | Measured |
|---|---|---|---|
| C1a | Clearance at **top** of opening | 3.0″ | __________ |
| C1b | Clearance at **middle** of opening | 3.0″ | __________ |
| C1c | Clearance at **bottom** of opening | 3.0″ | __________ |
| C2 | **Smallest of the three** ← design to this | 3.0″ | __________ |
| C3 | What *is* the frontmost thing? (describe + photo) | — | __________ |
| C4 | Loose cabling hanging forward of the boards? | — | ☐ Yes ☐ No |
| C5 | Can loose cabling be safely dressed back? | — | ☐ Yes ☐ No ☐ Ask VCF |

**Decision gate — now decides TWO things.** Door depth budget is **2.5″**, needs
C2 ≥ **3.0″**. C2 also picks custom fabrication vs. buying an enclosure and
modifying it (see [`enclosure-buy-vs-build.md`](enclosure-buy-vs-build.md) §4):

- [ ] C2 < 2.5″ → **stop and re-plan the door** (dimensions-assumed.md §5)
- [ ] C2 = 2.5″–3.0″ → custom fab, drop to 24 mm buttons, re-check
- [ ] C2 = 3.0″–4.5″ → **custom fab as drawn.** Off-the-shelf enclosures won't close
- [ ] C2 ≥ 4.5″ → custom fab *or* a 4″ off-the-shelf enclosure — buy-and-modify is live
- [ ] C2 ≥ 6.5″ → full enclosure size ladder available; choose on proportions

**Also on Wednesday:** look for a usable shallow **aluminium** enclosure in the
warehouse. Salvage beats buying, and steel is too heavy for the hinge.

- [ ] Photographed the card cage from a side angle showing protrusion depth

---

## D. Hinge side (left) and swing

| Ref | Measurement | Answer |
|---|---|---|
| D1 | Clear space to the LEFT of the cabinet (need ~18″) | __________ |
| D2 | What's to the left? (wall / exhibit / walkway) | __________ |
| D3 | Existing hinge points or holes on the left frame? | ☐ Yes ☐ No |
| D4 | Front frame lip — depth / thickness (for clamping) | ______ / ______ |
| D5 | Is the lip continuous along the opening? | ☐ Yes ☐ No |
| D6 | Anything that would foul a door swinging to ~100°? | __________ |

- [ ] Photographed the left frame edge / hinge area close-up

---

## E. Existing attachment opportunities

| Ref | Measurement | Answer |
|---|---|---|
| E1 | Existing threaded holes on the front frame — count, size, spacing | __________ |
| E2 | Can a straddle bracket grab the frame lip cleanly? | ☐ Yes ☐ No |
| E3 | Original doors/panels present but removed/removable? | __________ |
| E4 | Paint/finish condition at contact points (chipping? flaking?) | __________ |
| E5 | Any prior non-original modifications already on the cabinet? | __________ |

- [ ] Photographed every candidate hole/point

---

## F. Finish, environment, install context

| Ref | Measurement | Answer |
|---|---|---|
| F1 | Tan finish — is there a scrap/spare panel we can take for color matching? | ☐ Yes ☐ No |
| F2 | Nearest AC outlet — distance and location | __________ |
| F3 | Visitor approach side / traffic flow | __________ |
| F4 | Ambient light on the screen — window glare, spotlights? | __________ |
| F5 | Floor: level? carpet or hard? | __________ |
| F6 | Does the cabinet move, or is it staying put? | __________ |
| F7 | Neighbouring exhibits and their clearances | __________ |

> **F1 matters more than it looks** — a removable tan scrap taken to a paint
> store closes MR13 (finish match) cheaply. If one exists, grab it.

---

## G. Photo list (do all of these)

- [ ] Straight-on front, whole cabinet, tape measure in frame
- [ ] All four corners of the front opening
- [ ] Left frame edge / hinge area, close-up
- [ ] Rack rail hole pattern, close-up with tape
- [ ] Card cage from a side angle — **showing how far forward the boards sit**
- [ ] Anything protruding forward of the board edges
- [ ] Inside of the top cap and the bottom plinth
- [ ] Rear of the cabinet
- [ ] Every label / nameplate / serial tag
- [ ] Wide shot showing the cabinet in its exhibit context

Drop them in `mechanical/photos/` named `me1-<subject>.jpg`.

---

## H. Sign-off

- [ ] All A–F blanks filled
- [ ] All G photos taken
- [ ] C2 recorded and the decision gate ticked
- [ ] Mount candidate chosen: ☐ A rail ☐ B straddle ☐ C existing ☐ combination
- [ ] Panel size confirmed: ☐ 24″ ☐ 27″ ☐ other: __________
- [ ] Nothing was removed from the cabinet, or: removed items bagged + labelled
- [ ] `dimensions-assumed.md` updated with the measured column
- [ ] Issue #26 closed with the filled sheet linked

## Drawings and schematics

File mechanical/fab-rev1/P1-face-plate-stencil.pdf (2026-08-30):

## P1 Face Plate — 1:1 cardboard stencil

2 columns × 4 rows = 8 sheets, plus this page. Finished size 15 × 30 inches. Window 11.5 × 20.5625.

1 · PRINT
1. Print this file on US Letter. In the print dialog set Scale: 100% (not “Fit to page”) and Margins: None.
2. Check the red bar on sheet 1 with a ruler. It must measure exactly 4.000 inches. If it doesn’t, the printer scaled the page — fix the setting and print again. Everything downstream depends on this.

2 · ASSEMBLE
1. Lay the sheets out using the tile map in each header — the filled square shows where that sheet goes.
2. Each sheet has a shaded overlap band with a dashed red line and two red registration crosses. Slide the next sheet until its crosses sit exactly on top of the ones underneath, then tape.
3. The 1 inch grid is the real check. Grid lines must run straight across every joint, and the printed coordinates ( x,y from the top-left corner of the plate) must agree on both sides of the tape.
4. Tape on the front so the tape doesn’t lift when you cut.

3 · CUT
Heavy dashed = cut out and discard: the screen window and the three buttons.
Small circles with crosses = mounting holes. Mark only — don’t cut them.
Heavy solid = the outside profile. Cut this last, so the sheet stays stable while you do the interior.

4 · TRANSFER
1. Tape the assembled stencil to cardboard. Corrugated works; foam board is better if you want it to stand up.
2. Trace the outside profile and both voids, then cut the cardboard.
3. Hold it up against the 3280 with the bottom edge 34 inches above the floor. That puts the button centres at 38.000 AFF, which is where the ADA reach range put them.

The window is provisional. It is cut 3/16″ smaller than the monitor’s lit rectangle so the face plate masks the bezel entirely — you should see illuminated LCD and no monitor frame at all. That means the window size depends on the monitor, and no monitor has been measured yet. These sheets use a nominal 23.8″ panel. Good enough to judge proportion on the machine; not the number to fabricate from.

What this is for. Proportion is the argument this whole design turns on — whether the kiosk reads as an added interpretation device or as a monitor wearing a cabinet. A photograph of cardboard taped to the real machine settles that in a way no drawing can. Take one from six feet away, straight on, and from about 45° to the side.

Generated by | make-stencil.py | from the same geometry as | P1-face-plate.dxf . Grid coordinates are inches
from the top-left corner of the plate. Overlap 3.200″ vertical, 0.800″ horizontal.

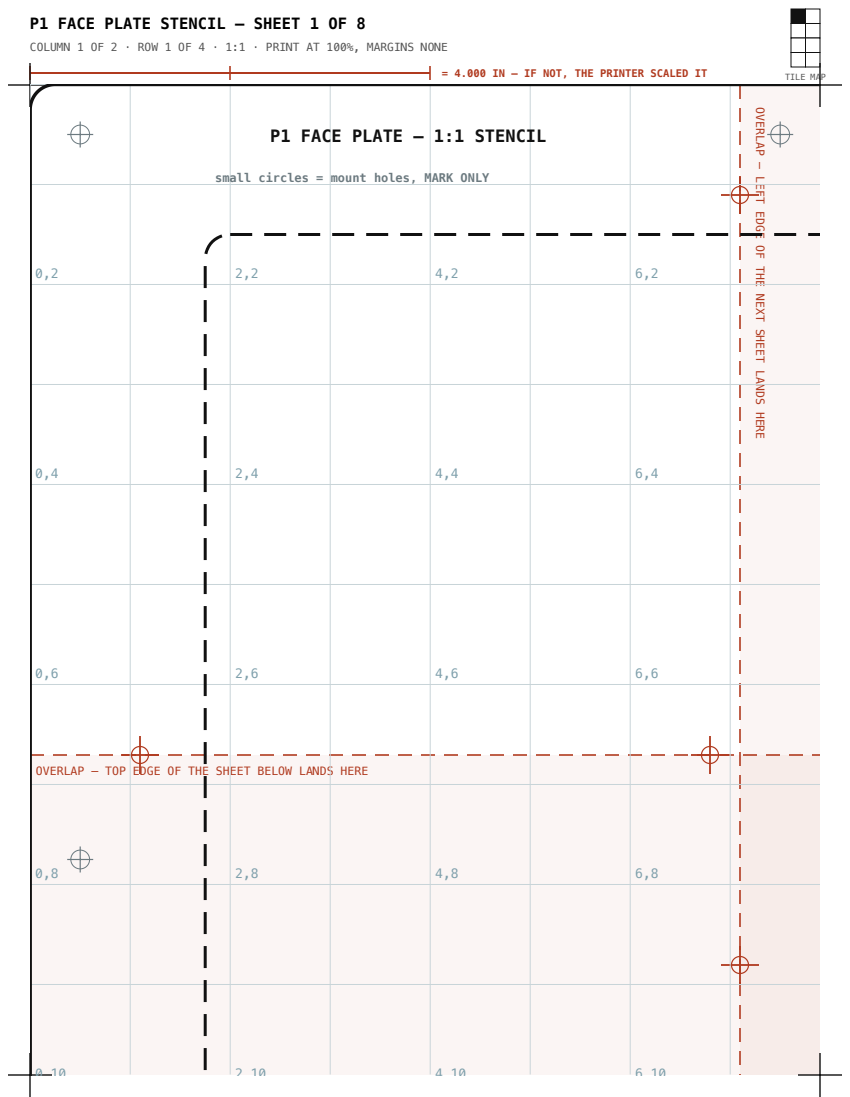
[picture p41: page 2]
= 4.000 IN — IF NOT, THE PRINTER SCALED IT; TILE MAP; OVERLAP — TOP; EDGE OF THE SHEET BELOW LANDS HERE; P1 FACE PLATE —; 1:1 STENCIL; small circles =; mount holes, MARK ONLY

P1 FACE PLATE STENCIL — SHEET 1 OF 8

COLUMN 1 OF 2 · ROW 1 OF 4 · 1:1 · PRINT AT 100%, MARGINS NONE

OVERLAP — LEFT EDGE OF THE NEX

T SHEET LANDS HERE

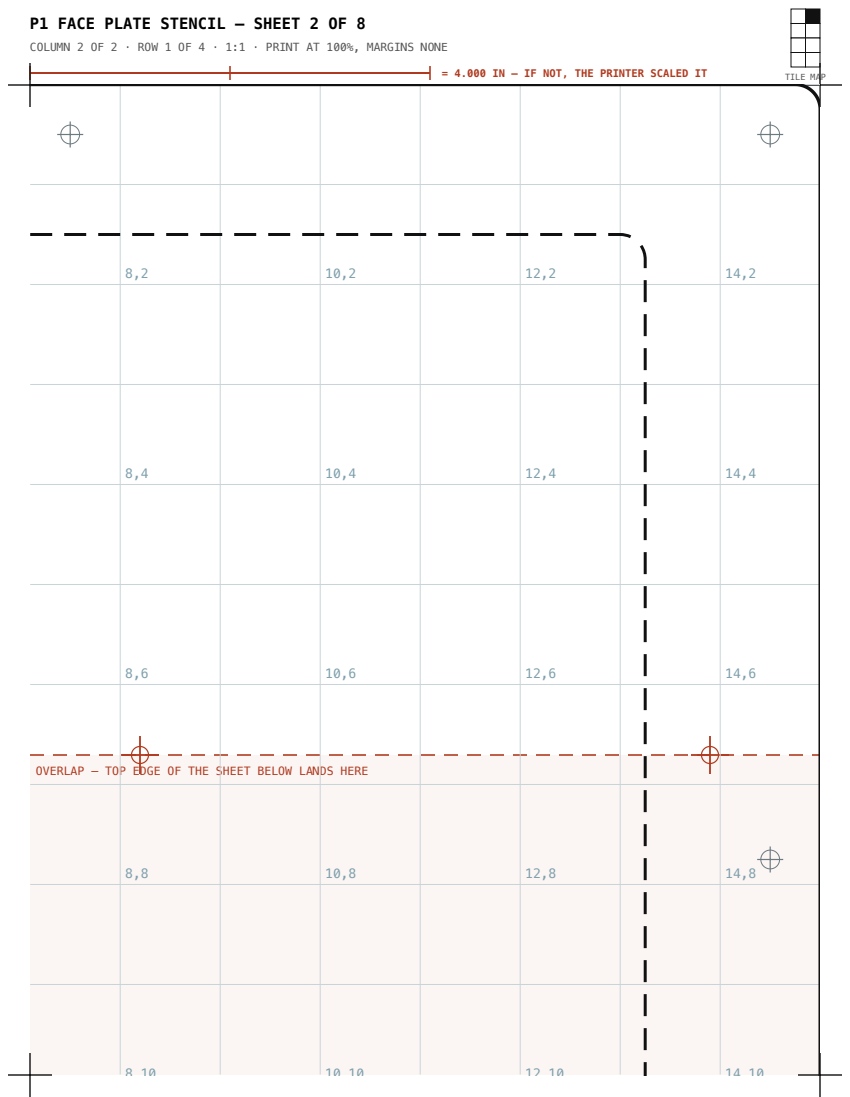
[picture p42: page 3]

P1 FACE PLATE STENCIL — SHEET 2 OF 8

COLUMN 2 OF 2 · ROW 1 OF 4 · 1:1 · PRINT AT 100%, MARGINS NONE

OVERLAP — TOP EDGE OF THE SHEET BELOW LANDS HERE

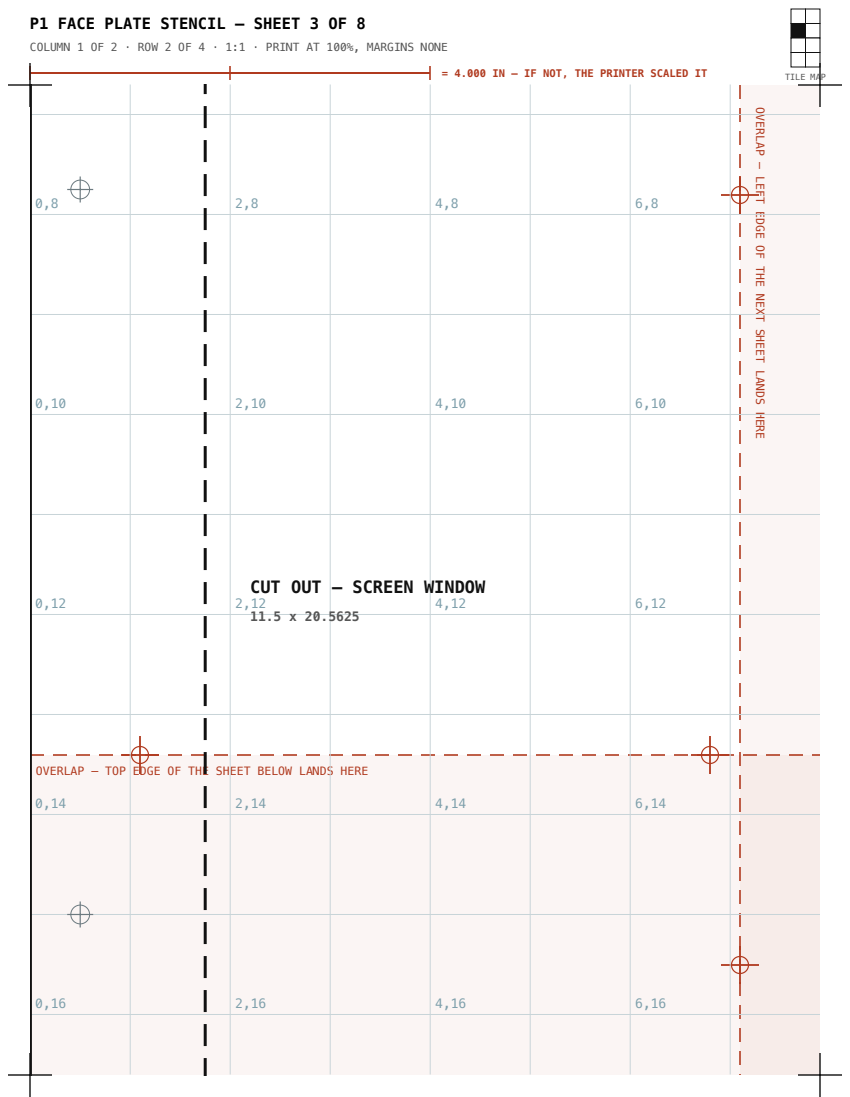
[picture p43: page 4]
OVERLAP — TOP; EDGE OF THE SHEET BELOW LANDS HERE; CUT OUT; — SCREEN WINDOW

P1 FACE PLATE STENCIL — SHEET 3 OF 8

COLUMN 1 OF 2 · ROW 2 OF 4 · 1:1 · PRINT AT 100%, MARGINS NONE

OVERLAP — LEFT EDGE OF THE NEX

T SHEET LANDS HERE

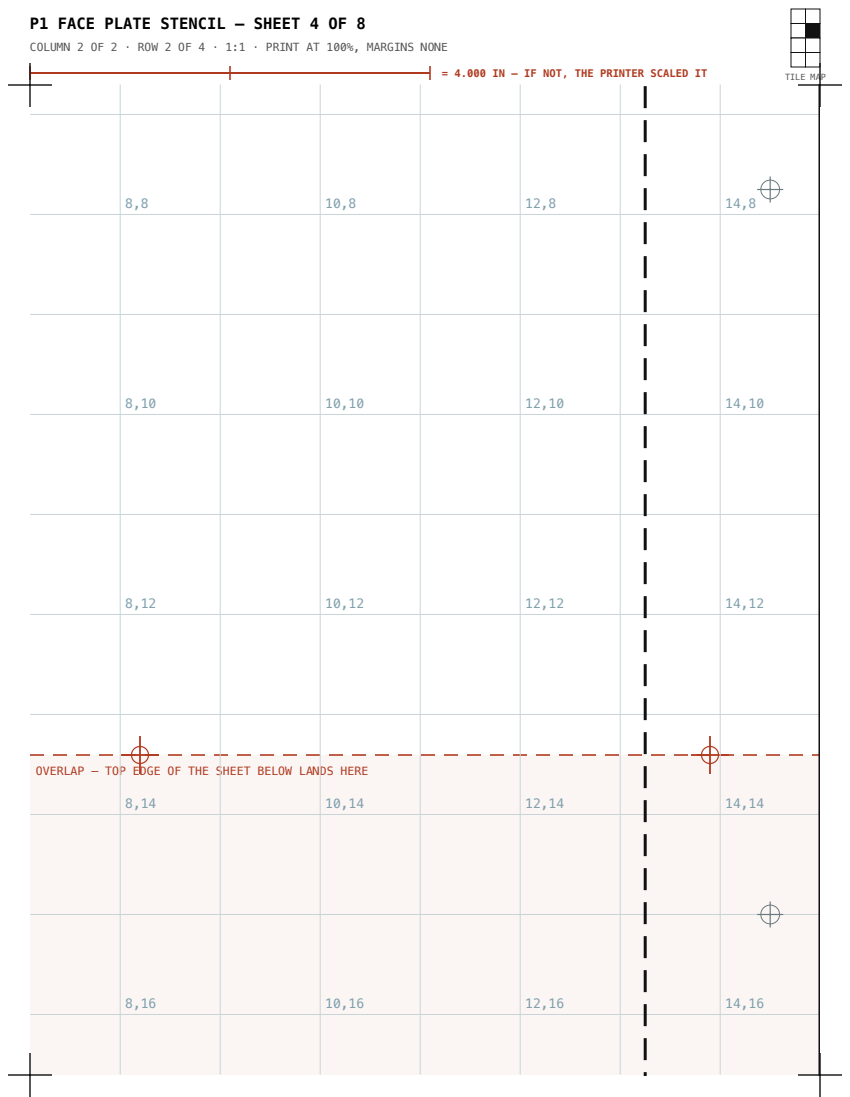
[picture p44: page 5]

P1 FACE PLATE STENCIL — SHEET 4 OF 8

COLUMN 2 OF 2 · ROW 2 OF 4 · 1:1 · PRINT AT 100%, MARGINS NONE

OVERLAP — TOP EDGE OF THE SHEET BELOW LANDS HERE

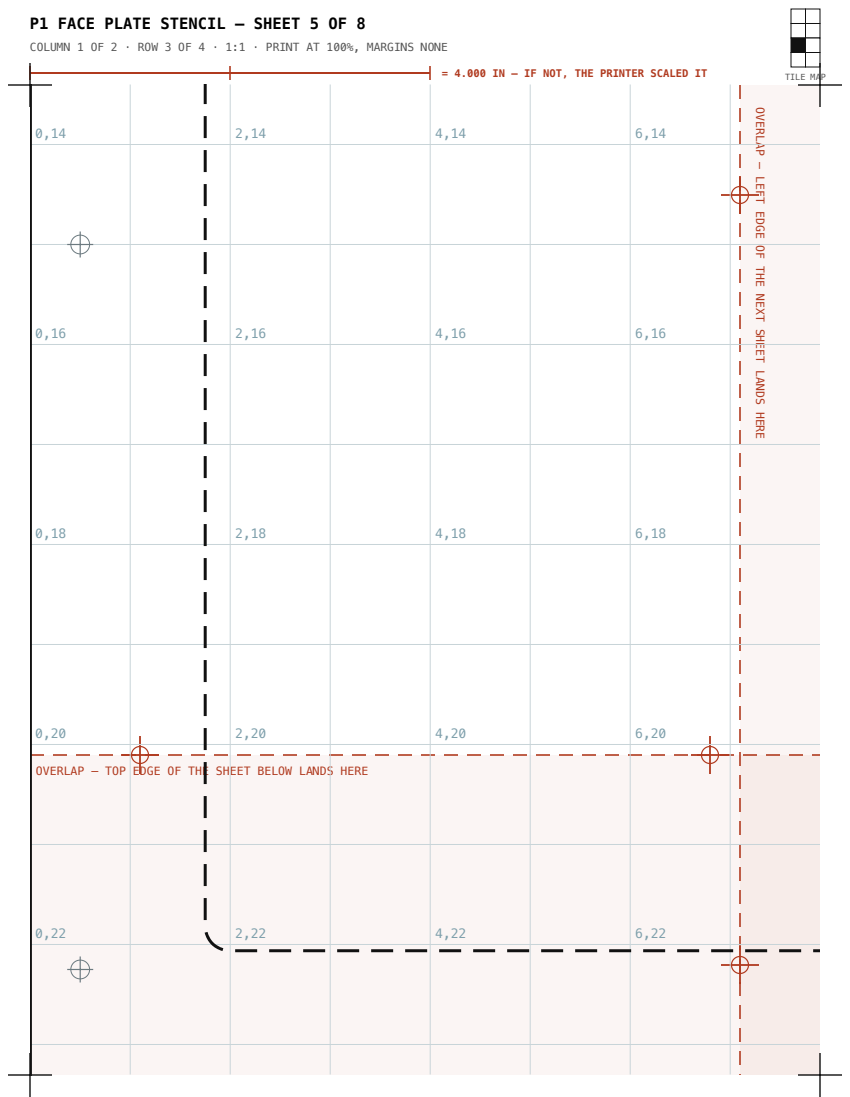
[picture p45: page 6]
OVERLAP — TOP; EDGE OF THE SHEET BELOW LANDS HERE

P1 FACE PLATE STENCIL — SHEET 5 OF 8

COLUMN 1 OF 2 · ROW 3 OF 4 · 1:1 · PRINT AT 100%, MARGINS NONE

OVERLAP — LEFT EDGE OF THE NEX

T SHEET LANDS HERE

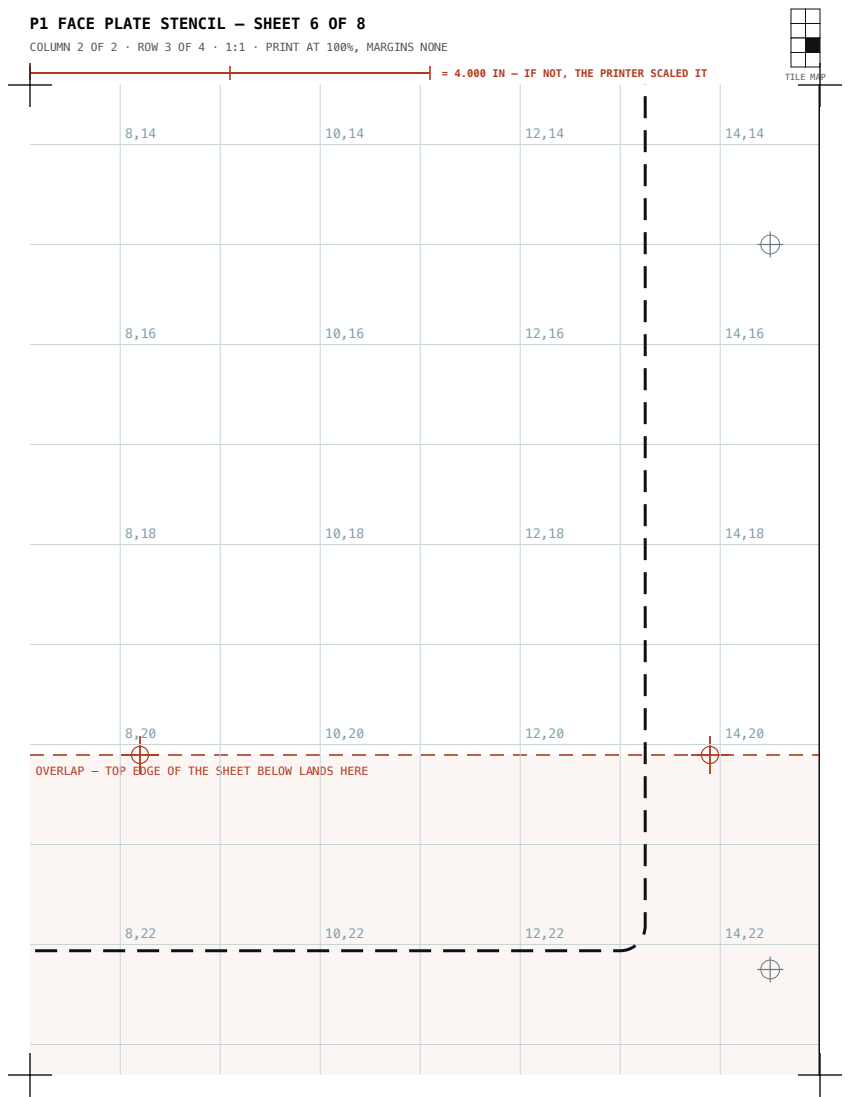
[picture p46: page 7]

P1 FACE PLATE STENCIL — SHEET 6 OF 8

COLUMN 2 OF 2 · ROW 3 OF 4 · 1:1 · PRINT AT 100%, MARGINS NONE

OVERLAP — TOP EDGE OF THE SHEET BELOW LANDS HERE

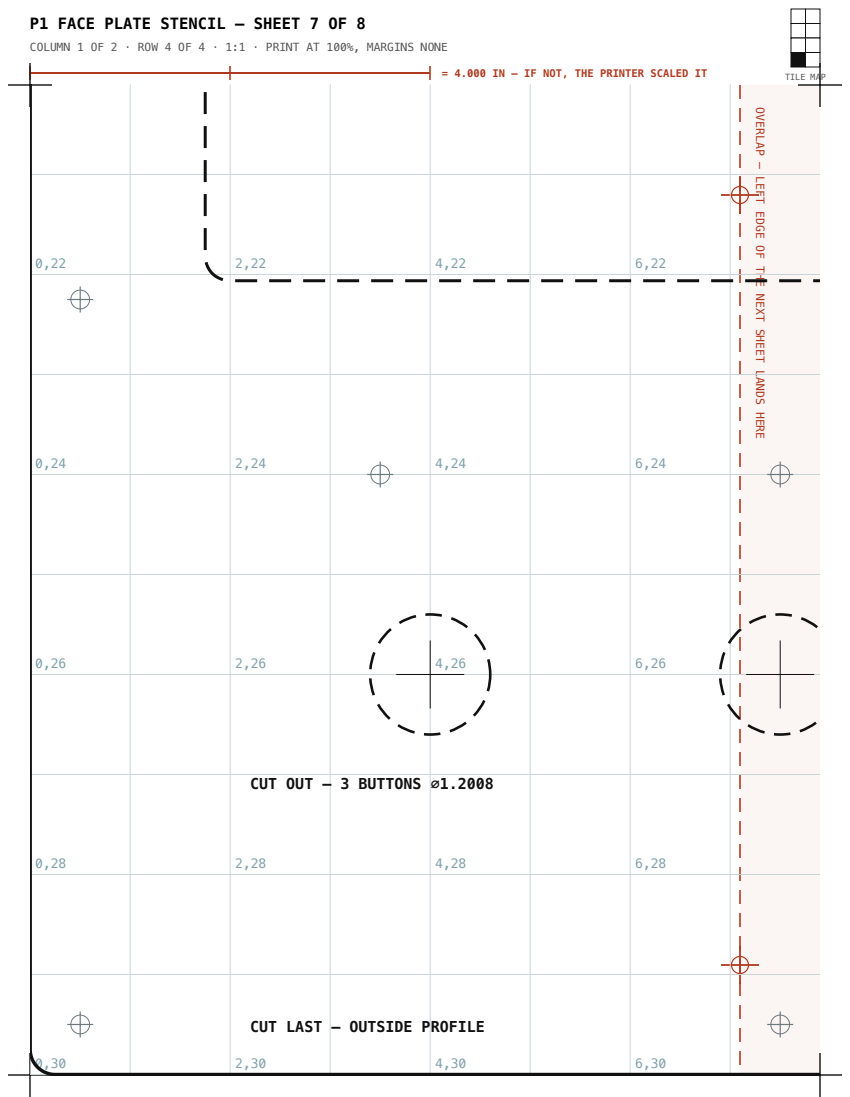
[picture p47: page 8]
CUT OUT —; 3 BUTTONS; CUT LAST; — OUTSIDE PROFILE

P1 FACE PLATE STENCIL — SHEET 7 OF 8

COLUMN 1 OF 2 · ROW 4 OF 4 · 1:1 · PRINT AT 100%, MARGINS NONE

OVERLAP — LEFT EDGE OF THE NEX

T SHEET LANDS HERE

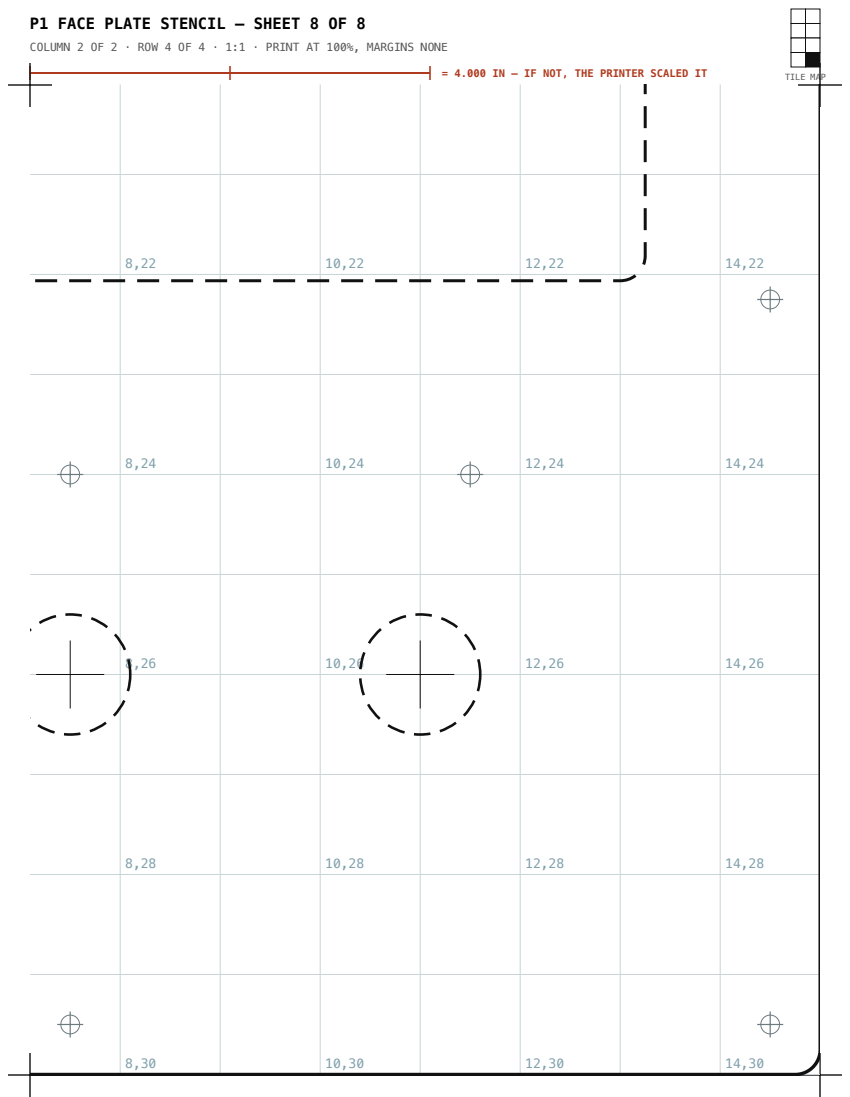
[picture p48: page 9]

P1 FACE PLATE STENCIL — SHEET 8 OF 8

COLUMN 2 OF 2 · ROW 4 OF 4 · 1:1 · PRINT AT 100%, MARGINS NONE

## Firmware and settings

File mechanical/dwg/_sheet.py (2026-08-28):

"""
Drawing-sheet framework — B-size (17 x 11) landscape, ANSI-style title block.

Everything is authored in PAPER INCHES. Model geometry is placed through
View(), which carries a drawing scale. That keeps line weights and lettering
constant across sheets no matter what each view is scaled to.
"""
import math, re

SW, SH = 17.0, 11.0          # sheet, inches
MARGIN = 0.35
TB_W, TB_H = 6.60, 1.85      # title block

# line weights, inches — ASME Y14.2 thick/thin convention
W_VIS, W_HID, W_DIM, W_CEN, W_PHAN, W_XTHIN = .020, .010, .008, .008, .008, .005
# lettering heights, inches
T_DIM, T_NOTE, T_LBL, T_HEAD, T_TITLE = .105, .105, .125, .155, .240

INK   = '#111111'
THIN  = '#444444'
ACC   = '#0E5A6B'
FLAG  = '#93331F'
GREY  = '#8A9095'

_AMP = re.compile(r'&(?!(?:#\d+|#x[0-9A-Fa-f]+|amp|lt|gt|quot|apos);)')
def esc(s):
    return _AMP.sub('&amp;', str(s)).replace('<', '&lt;').replace('>', '&gt;')

def f(v, p=4):
    return f"{v:.{p}f}".rstrip('0').rstrip('.') or '0'

class Sheet:
    def __init__(self, number, title, scale, material, finish, sheet_no, sheet_of,
                 rev='A', date='2026-08-28'):
        self.meta = dict(number=number, title=title, scale=scale, material=material,
                         finish=finish, n=sheet_no, of=sheet_of, rev=rev, date=date)
        self.o = []

    # ── primitives, paper inches, Y DOWN ─────────────────────────────────────
    def line(self, x1, y1, x2, y2, w=W_VIS, c=INK, dash=None, cap='butt'):
        d = f' stroke-dasharray="{dash}"' if dash else ''
        self.o.append(f'<path d="M{f(x1)} {f(y1)}L{f(x2)} {f(y2)}" stroke="{c}" '
                      f'stroke-width="{w}" fill="none" stroke-linecap="{cap}"{d}/>')
    def poly(self, pts, w=W_VIS, c=INK, fill='none', dash=None, close=True):
        d = 'M' + 'L'.join(f'{f(x)} {f(y)}' for x, y in pts) + ('Z' if close else '')
        da = f' stroke-dasharray="{dash}"' if dash else ''
        self.o.append(f'<path d="{d}" stroke="{c}" stroke-width="{w}" fill="{fill}"{da}/>')
    def rect(self, x, y, w, h, lw=W_VIS, c=INK, fill='none', dash=None, r=0):
        da = f' stroke-dasharray="{dash}"' if dash else ''
        self.o.append(f'<rect x="{f(x)}" y="{f(y)}" width="{f(w)}" height="{f(h)}" rx="{f(r)}" '
                      f'stroke="{c}" stroke-width="{lw}" fill="{fill}"{da}/>')
    def circ(self, cx, cy, r, lw=W_VIS, c=INK, fill='none', dash=None):
        da = f' stroke-dasharray="{dash}"' if dash else ''
        self.o.append(f'<circle cx="{f(cx)}" cy="{f(cy)}" r="{f(r)}" stroke="{c}" '
                      f'stroke-width="{lw}" fill="{fill}"{da}/>')
    def text(self, x, y, s, h=T_NOTE, c=INK, anchor='start', bold=False, mid=False,
             rot=None, mono=True, ls=0):
        fam = ('"Space Mono",ui-monospace,monospace' if mono
               else '"Archivo",Helvetica,Arial,sans-serif')
        tr = f' transform="rotate({rot} {f(x)} {f(y)})"' if rot is not None else ''
        db = ' dominant-baseline="central"' if mid else ''
        lsp = f' letter-spacing="{f(ls)}"' if ls else ''
        self.o.append(f'<text x="{f(x)}" y="{f(y)}" font-family={chr(39)}{fam}{chr(39)} '
                      f'font-size="{h}" fill="{c}" text-anchor="{anchor}"'
                      f'{" font-weight=\'700\'" if bold else ""}{db}{tr}{lsp}>{esc(s)}</text>')

    # ── dimensions ───────────────────────────────────────────────────────────
    def dim_h(self, y, x1, x2, label, above=True, ext_from=None, c=ACC):
        l, r_ = min(x1, x2), max(x1, x2)
        a = .055
        self.line(l, y, r_, y, W_DIM, c)
        for x in (l, r_):
            self.line(x, y-a, x, y+a, W_DIM, c)
            if ext_from is not None:
                self.line(x, ext_from, x, y + (a if y > ext_from else -a), W_XTHIN, c)
        self.text((l+r_)/2, y - .06 if above else y + .16, label, T_DIM, c, 'middle')
    def dim_v(self, x, y1, y2, label, left=True, ext_from=None, c=ACC):
        t, b = min(y1, y2), max(y1, y2)
        a = .055
        self.line(x, t, x, b, W_DIM, c)
        for y in (t, b):
            self.line(x-a, y, x+a, y, W_DIM, c)
            if ext_from is not None:
                self.line(ext_from, y, x + (a if x > ext_from else -a), y, W_XTHIN, c)
        ox = x - .07 if left else x + .07
        self.text(ox, (t+b)/2, label, T_DIM, c, 'middle', mid=True, rot=-90)
    def leader(self, x1, y1, x2, y2, label, anchor='start', c=INK, h=T_NOTE):
        self.line(x1, y1, x2, y2, W_DIM, c)
        self.circ(x1, y1, .022, W_DIM, c, c)
        self.text(x2 + (.07 if anchor == 'start' else -.07), y2, label, h, c, anchor, mid=True)
    def balloon(self, x, y, n, tx, ty):
        self.line(x, y, tx, ty, W_DIM, INK)
        self.circ(x, y, .022, W_DIM, INK, INK)
        self.circ(tx, ty, .145, W_DIM, INK, '#FFFFFF')
        self.text(tx, ty, str(n), T_DIM, INK, 'middle', bold=True, mid=True)
    def centre(self, cx, cy, r):
        e = r + .09
        self.line(cx-e, cy, cx+e, cy, W_CEN, GREY, dash='.10 .05 .02 .05')
        self.line(cx, cy-e, cx, cy+e, W_CEN, GREY, dash='.10 .05 .02 .05')
    def hatch(self, x, y, w, h, pitch=.07, c=GREY, ang=45):
        cid = f'h{len(self.o)}'
        self.o.append(f'<clipPath id="{cid}"><rect x="{f(x)}" y="{f(y)}" '
                      f'width="{f(w)}" height="{f(h)}"/></clipPath>')
        d = []
        n = int((w + h)/pitch) + 2
        for i in range(-n, n):
            d.append(f'M{f(x+i*pitch)} {f(y+h)}L{f(x+i*pitch+h)} {f(y)}')
        self.o.append(f'<path d="{"".join(d)}" stroke="{c}" stroke-width="{W_XTHIN}" '
                      f'fill="none" clip-path="url(#{cid})"/>')

    # ── frame + title block ──────────────────────────────────────────────────
    def frame(self):
        m = MARGIN
        self.rect(m, m, SW-2*m, SH-2*m, W_VIS, INK)
        self.rect(m+.09, m+.09, SW-2*m-.18, SH-2*m-.18, W_XTHIN, THIN)
        cols, rows = 8, 5
        for i in range(1, cols):
            x = m + i*(SW-2*m)/cols
            for yy in (m, SH-m-.09):
                self.line(x, yy, x, yy+.09, W_XTHIN, THIN)
        for i in range(cols):
            x = m + (i+.5)*(SW-2*m)/cols
            self.text(x, m+.075, str(cols-i), .085, THIN, 'middle', mid=True)
            self.text(x, SH-m-.045, str(cols-i), .085, THIN, 'middle', mid=True)
        for i in range(rows):
            y = m + (i+.5)*(SH-2*m)/rows
            ltr = 'EDCBA'[i]
            self.text(m+.045, y, ltr, .085, THIN, 'middle', mid=True)
            self.text(SW-m-.045, y, ltr, .085, THIN, 'middle', mid=True)
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

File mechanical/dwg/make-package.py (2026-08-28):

#!/usr/bin/env python3
"""
Rev 1 manufacturing drawing package — 12 sheets, B size (17 x 11), third angle.

    python3 make-package.py

Every dimension comes from _geom.py, which mirrors ../fab-rev1/make-cutfiles.py.
Change geometry there, re-run both.
"""
import os, sys
sys.path.insert(0, os.path.dirname(os.path.abspath(__file__)))
from _sheet import *
import _geom as G

OUT = os.path.dirname(os.path.abspath(__file__))
N = len(G.SHEETS)
def sheet(num, scale, mat, fin):
    i = [k for k, _ in enumerate(G.SHEETS) if G.SHEETS[k][0] == num][0]
    s = Sheet(num, G.SHEETS[i][1], scale, mat, fin, i+1, N)
    s.frame(); s.title_block()
    return s
def done(s, num):
    s.save(os.path.join(OUT, f'{num}.svg'))
    return num

# ═══ 000 · COVER ════════════════════════════════════════════════════════════
s = sheet('000', 'NONE', 'SEE BOM', 'SEE NOTES')
s.text(.7, 1.25, 'CONCURRENT 3280 EXHIBIT KIOSK', T_TITLE*1.5, INK, bold=True, mono=False)
s.text(.7, 1.75, 'REV 1 · STANDALONE ENCLOSURE · MANUFACTURING PACKAGE', T_HEAD, ACC,
       mono=False, bold=True)
s.line(.7, 2.0, 10.2, 2.0, W_VIS, INK)
s.text(.7, 2.35, 'DRAWING INDEX', .115, THIN, bold=True, ls=.02)
for k, (num, _short, title) in enumerate(G.SHEETS):
    y = 2.65 + k*.245
    s.text(.75, y, num, .105, ACC, bold=True)
    s.text(1.35, y, title, .105, INK)
    s.line(.7, y+.075, 6.6, y+.075, W_XTHIN, '#DDDDDD')
s.text(7.1, 2.35, 'GENERAL NOTES', .115, THIN, bold=True, ls=.02)
NOTES = [
 '1.  ALL DIMENSIONS IN INCHES UNLESS NOTED. THIRD ANGLE PROJECTION.',
 '2.  DATUM -A- IS THE FRONT FACE OF P1. DATUM -B- IS THE TOP EDGE OF P1.',
 '3.  CRITICAL: BUTTON CENTRELINE 25.440 BELOW DATUM -B-. WITH THE KIOSK BOTTOM',
 '     AT 34.750 AFF THIS PLACES THE CONTROLS AT 38.000 AFF, INSIDE THE ADA 2010',
 '     §308 REACH RANGE OF 15.000 TO 48.000. DO NOT CHANGE WITHOUT RE-DERIVING.',
 '4.  P1 IS CNC ROUTED FROM 3 mm ACM. IT CANNOT BE BENT, TAPPED, COUNTERSUNK',
 '     OR POWDER COATED. ALL FIXING IS THROUGH CLEARANCE HOLES INTO ITEM 11.',
 '5.  NEVER DRIVE A SCREW INTO A PLYWOOD EDGE. USE ITEM 11 THROUGHOUT.',
 '6.  MONITOR IS ALIGNED TO THE P1 WINDOW, NOT THE REVERSE. THE WINDOW IS 0.250',
 '     OVERSIZE PER SIDE ON THE NOMINAL 23.8" ACTIVE AREA AND CLEARS EVERY PANEL',
 '     SOLD AS "24 INCH" (23.6 TO 24.0 DIAGONAL). SHIM P9 IN DEPTH TO SUIT.',
 '7.  P1 FIXINGS (ITEM 12) ARE VISIBLE ON THE FRONT FACE. BLACK HEAD ON A BLACK',
 '     PANEL, TREATED AS AN INSTRUMENT-PANEL DETAIL. PIN-TORX SPECIFIED SO THEY',
 '     CANNOT BE CASUALLY REMOVED BY THE PUBLIC. ALTERNATE: BOND P1 WITH VHB',
 '     STRUCTURAL TAPE AND OMIT ITEMS 11/12 AT THE PERIMETER — NOT REVERSIBLE.',
 '8.  ⌀1.2008 (30.5 mm) BUTTON CUTOUT IS NOMINAL FOR A 30 mm ANTI-VANDAL SWITCH.',
 '     VERIFY AGAINST THE DATASHEET OF THE SWITCH ACTUALLY PURCHASED BEFORE',
 '     RELEASING SHEET 200. CONFIRM PANEL RANGE INCLUDES 3 mm AND ACTUATION',
 '     FORCE ≤ 5 lbf PER ADA §309.4.',
 '9.  NO TEXT IS CUT INTO P1. BACK / HOME / NEXT LEGENDS ARE APPLIED VINYL,',
 '     APPLIED AFTER ASSEMBLY. SEE SHEET 600.',
 '10. THE KIOSK MOUNTS TO THE CLOSED FACTORY DOOR OF THE CONCURRENT 3280. THE',
 '     MOUNTING ADAPTER IS A SEPARATE SUBSYSTEM, NOT IN THIS PACKAGE. TOTAL',
 '     PROJECTION FROM THE DOOR FACE TO REMAIN ≤ 4.000 PER ADA §307.2, LEAVING',
 '     0.750 FOR THE ADAPTER. NO FASTENER MAY ENTER THE HISTORIC CABINET.',
]
for k, ln in enumerate(NOTES):
    s.text(7.1, 2.65 + k*.185, ln, .092, INK)
s.rect(7.05, 8.05, 9.0, .95, W_VIS, FLAG, '#FFFFFF')
s.text(7.2, 8.35, 'CONCEPT PACKAGE — NOT RELEASED FOR PRODUCTION', .135, FLAG, bold=True)
s.text(7.2, 8.60, 'The Concurrent 3280 is a museum artifact. All mounting must be reversible,', .095, INK)
s.text(7.2, 8.80, 'non-destructive and removable. Nothing in this package fastens to the machine.', .095, INK)
s.default_tol(.7, 9.05)
done(s, '000')

# ═══ 100 · GENERAL ARRANGEMENT ══════════════════════════════════════════════
s = sheet('100', '1:4', 'ASSEMBLY', '—')
K = .25
fv = View(s, 1.35, 8.35, K)                       # front elevation
def outline_front(v, hidden=False):
    s.rect(v.x(0), v.y(G.OA_H), v.d(G.OA_W), v.d(G.OA_H), W_VIS, INK, '#FFFFFF', r=v.d(G.R_OUT))
    s.rect(v.x(G.WIN_X), v.y(G.OA_H-G.WIN_TOP), v.d(G.WIN_W), v.d(G.WIN_H),
           W_VIS, INK, '#F2F4F5', r=v.d(G.R_IN))
    for i in (-1, 0, 1):
        cx, cy = v.x(G.OA_W/2 + i*G.BTN_CC), v.y(G.OA_H - G.BTN_TOP)
        s.circ(cx, cy, v.d(G.BTN_DIA/2), W_VIS, INK, '#FFFFFF')
        s.centre(cx, cy, v.d(G.BTN_DIA/2))
outline_front(fv)
s.text(fv.x(G.OA_W/2), fv.y(-1.0), 'FRONT', T_LBL, INK, 'middle', bold=True)
s.dim_h(fv.y(G.OA_H)-.55, fv.x(0), fv.x(G.OA_W), '15.370', ext_from=fv.y(G.OA_H))
s.dim_v(fv.x(0)-.55, fv.y(0), fv.y(G.OA_H), '28.690', ext_from=fv.x(0))
s.dim_h(fv.y(G.OA_H-G.BTN_TOP)+1.15, fv.x(G.OA_W/2-G.BTN_CC), fv.x(G.OA_W/2), '3.500')
s.dim_v(fv.x(G.OA_W)+.42, fv.y(G.OA_H), fv.y(G.OA_H-G.BTN_TOP), '25.440', left=False,
        ext_from=fv.x(G.OA_W))
s.dim_v(fv.x(G.OA_W)+1.00, fv.y(G.OA_H), fv.y(G.OA_H-G.WIN_TOP), '1.350', left=False)
s.leader(fv.x(G.WIN_X+G.WIN_W), fv.y(G.OA_H-G.WIN_TOP-G.WIN_H/2), fv.x(G.OA_W)+1.60,
         fv.y(G.OA_H-G.WIN_TOP-G.WIN_H/2), 'WINDOW 12.170 x 21.240')

sv = View(s, 6.55, 8.35, K)                       # right side
s.rect(sv.x(0), sv.y(G.OA_H), sv.d(G.OA_D), sv.d(G.OA_H), W_VIS, INK, '#FFFFFF')
s.rect(sv.x(0), sv.y(G.OA_H), sv.d(G.T_ACM), sv.d(G.OA_H), W_VIS, INK, '#DDE3E6')
s.rect(sv.x(G.Z['rear_f']), sv.y(G.OA_H-G.T_PLY), sv.d(G.T_PLY), sv.d(G.OA_H-2*G.T_PLY),
       W_HID, INK, 'none', dash='.06 .04')
s.text(sv.x(G.OA_D/2), sv.y(-1.0), 'RIGHT SIDE', T_LBL, INK, 'middle', bold=True)
s.dim_h(sv.y(G.OA_H)-.55, sv.x(0), sv.x(G.OA_D), '3.250', ext_from=sv.y(G.OA_H))
s.line(sv.x(-.4), sv.y(G.OA_H-G.BTN_TOP), sv.x(G.OA_D+.4), sv.y(G.OA_H-G.BTN_TOP),
       W_CEN, FLAG, dash='.14 .06 .03 .06')
s.text(sv.x(G.OA_D)+.55, sv.y(G.OA_H-G.BTN_TOP), 'BUTTON DATUM', .095, FLAG, mid=True)
s.text(sv.x(G.OA_D)+.55, sv.y(G.OA_H-G.BTN_TOP)+.17, '38.000 AFF INSTALLED', .085, FLAG, mid=True)

tv = View(s, 1.35, 10.05, K)                      # top view
s.rect(tv.x(0), tv.y(G.OA_D), tv.d(G.OA_W), tv.d(G.OA_D), W_VIS, INK, '#FFFFFF')
s.rect(tv.x(0), tv.y(G.OA_D), tv.d(G.OA_W), tv.d(G.T_ACM), W_VIS, INK, '#DDE3E6')
for x in (G.T_PLY, G.OA_W-G.T_PLY):
    s.line(tv.x(x), tv.y(G.OA_D-G.T_ACM), tv.x(x), tv.y(0), W_HID, INK, dash='.06 .04')
s.text(tv.x(G.OA_W/2), tv.y(-.35), 'TOP', T_LBL, INK, 'middle', bold=True)
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

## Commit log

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2026-08-22 docs: v1 PRD — story-first kiosk, deep mechanical requirements
    Product requirements from the requirements interview. Electronics kept
    light (builder's high-confidence domain); mechanical specified in depth
    (highest risk), grounded in the two concept renders.
    Key decisions captured:
    - Both visitor + docent; NJ-origin story is the primary success goal.
    - Offline/standalone, silent, English-only, no touchscreen (v1).
    - Raspberry Pi + monitor + GPIO buttons; wire spares for future use.
    - Small hinged kiosk door in a fixed front frame; left hinge, holds open;
    open framing (no glazing); match-the-machine finish; ~24" portrait panel
    (confirm by measuring); reversible/non-destructive mounting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
2026-08-22 docs(prd): enclosed low-profile door — rear cover + Pi inside shroud
    Add MR18/MR19: the door is a fully enclosed assembly with a low-profile
    rear cover shrouding the monitor back, the Pi, and the button backs;
    vented and service-removable. Pi mounts inside the shroud, so only power
    crosses the hinge — settles the earlier Pi-on-door open question. Wire
    into ventilation (MR14), cabling (MR10), and depth/clearance (MR3/MR7).
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2026-08-22 docs(arch): split stable core (SD) from content on a swappable USB drive
    Nick's Pi 4 (has USB) drives a clean separation: OS + Chromium +
    controller are the stable core on the SD (read-only overlay), and the
    content lives on a removable USB drive mounted by label (KIOSK) at a
    fixed point. Updating content = edit/swap the stick; never re-image.
    - A2.5 content-on-USB (mount by label, deterministic mount point).
    - A2.6 graceful "content drive not found" state (no demo fallback).
    - Loopback server serves from the USB mount (A3.2); build deploys to USB
    (A5.1); usage logs written to the same stick so content-in/logs-out is
    one swap (A6.1/A6.3), append-only + fsync, yank/power-safe.
    - Block di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
2026-08-22 docs: v1 dev plan — epics/stories across SW/EL/ME/IN tracks
    Work breakdown traced to PRD/architecture IDs, sequenced to the PRD
    phasing. Four tracks (software, electronics, mechanical, integration) +
    milestones M1-M5. Mechanical is the critical path (measure -> door ->
    install); software runs alongside off the critical path. ~31 issue-sized
    stories with acceptance criteria, a proposed GitHub milestone/label/issue
    scheme, a risk register, and first actions (measure the machine first).
    Completes the PRD -> Architecture -> UX -> Dev-plan flow.
2026-08-22 docs(me1): assumed dimensions, drawings, field sheet, salvage list
    Field materials for the museum/warehouse trip, published ahead of ME-1 so
    the design can be discussed and shopped for before anything is measured.
    mechanical/
    - dimensions-assumed.md — v0 dimension set with provenance and confidence
    per number; resolves PRD open question 4 (ADA reach) under assumption;
    documents C1 (front face → frontmost obstruction) as the critical risk
    with a cheapest-first escalation ladder
    - measurement-checklist.md — ME-1 field sheet, sections A–H, phone-readable
    - drawings/ — four dimensioned SVGs: front elevation, door layout,
    plan section with swing + clearance, reversible mount ca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
2026-08-22 fab(me4): drawing sheets + shareable package for CDL
    Upgraded the fab previews into proper drawing sheets and wrapped them in a
    package aimed at makers who might fabricate this locally rather than a
    laser-cutting service.
    generate.py
    - Part now records a tagged feature schedule as geometry is built
    - sheet_svg() replaces the bare preview: sheet border, header, datum marker,
    overall dimensions, centre marks on every hole, feature schedule with X/Y
    coordinates, notes block and a title block (part/rev/material/thickness/
    qty/units/operations/finish)
    - enough to lay a part out by hand on a mill or drill press, not just to
    feed a laser
    DRAWING-PACKAGE.md — the shareable document: what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
2026-08-22 docs(me4): buy-and-modify enclosure option; C1 becomes a two-way gate
    Evaluates buying a shallow industrial enclosure and modifying it instead of
    fabricating the door from scratch.
    Key findings:
    - The useful configuration is to run the box backwards: solid back panel
    faces the visitor and takes the screen window, the inner mounting panel
    carries the LCD/Pi, and the enclosure's own hinged door becomes rear
    service access (MR16 + MR18 for free).
    - It does NOT avoid the screen window cut — and moves that cut from flat
    sheet onto a formed box, which is harder. Avoiding that cut was the main
    reason for outsourcing in the first place.
    - Steel is disqualified on weight: a 30x16x4 16ga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
2026-08-22 docs(me4): add sourcing section to the enclosure buy-vs-build doc
    Where to browse, what to filter on, and a third path worth pricing: custom
    one-off enclosure houses (Protocase, Front Panel Express) that remove the
    window-cut problem entirely.
2026-08-22 docs(me4): Leviton STRUCTURED MEDIA can as lead buy-and-modify candidate
    Verified against Leviton spec B26 SS1431 (Feb 2026). 47605-28N is 28.0 x
    14.30 x 3.85, 20-gauge white powder-coated steel, ~13.6 lb with the vented
    hinged door (47605-28S) — on our 14.5 lb budget, unlike a load center of the
    same footprint which runs ~26 lb because it carries bus bars.
    Width 14.30 vs our 14.50 is essentially exact, and the face layout (window +
    reveal + button plate = 25.46) fits the 28in height with margin to spare.
    Depth 3.85 is the only issue: needs C1 >= 4.35.
    The can's back carries a module-mounting hole grid, so it needs our P1 face
    plate over it — which collapses the fab package from four p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
2026-08-22 docs(me4): third display approach — cased monitor on a hinged VESA carrier
    Adds Option C: leave the monitor whole, VESA-mount it to a flat tan carrier
    panel, hinge that to the frame, buttons on a plate below.
    Eliminates the two highest-risk items in the project — de-casing the panel
    (one-way) and the screen window cut (hardest fab op) — and collapses
    fabrication to a single hand-drillable panel of round holes. Thermal and
    MR18 enclosure become self-solving because the monitor keeps its housing.
    Decisive advantage: a commercial monitor is replaceable by a docent. A
    de-cased panel bonded into a bespoke door is not, which matters against the
    project's transfer-ownership rule.
    Costs MR1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
2026-08-22 docs(me4): concept comparison drawing — all four display approaches
    Adds 06-option-comparison.svg: four cabinet elevations side by side (A
    custom door, B bought can, C1 monitor recessed, C2 monitor proud), each
    with a depth-behind-the-face bar and a scorecard covering fab parts,
    de-casing risk, hardest cut, docent-replaceability and how built-in it
    looks.
    Drawn to the assumed cabinet geometry rather than AI concept art, so the
    proportions are honest and the options are actually comparable.
    Headline finding the drawing makes visible: A, B and C1 look almost
    identical from the front. Recessing the monitor behind a bezel-sized cut
    preserves the approved concept — only C2 reads as bolted-o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
2026-08-26 docs(me1): first site visit findings — the cabinet has two doors
    Read off the 2026-08-26 photographs, not a filled field sheet. Provisional.
    Headline: the 3280 has a tan louvered outer door and a perforated
    zinc-plated inner door in front of the card cage. Every drawing in this repo
    assumes an open front opening with a visible card cage and a fixed frame
    spanning it. That geometry does not exist — the concept render invented it.
    Likely makes the project easier: there is already a hinged tan door of about
    the right size, so the cleanest mount is to hang our panel on its hinges and
    store the original. ME-2/ME-3 (reversible mount, fixed frame) may collapse
    entirely, and ME-10 plexiglass i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
2026-08-27 docs(me1): height discrepancy resolved — box vs overall
    The 67-7/8in tape reading is the cabinet box alone; the machine stands on
    feet below it. 67-7/8 + 3-1/8 = 71in, matching Concurrent's published
    overall height exactly. A 1989 catalogue and a warehouse tape measure
    closing to an eighth is strong mutual confirmation — both numbers are good.
    Use 71in for floor-relative work (ADA, sightlines, install) and 67-7/8in for
    anything referenced to the box.
    Corrects a real assumption: dimensions-assumed.md had the plinth+feet at
    8.0in. It is ~3-1/8in, so everything sits about 5in lower than drawn. That
    helps ADA reach by moving the buttons away from the 48in ceiling, but wants
    re-checking aga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
2026-08-27 docs(me1): Perkin-Elmer 3230 mechanical drawings — 19in rack confirmed
    Pulled the 3230 Installation and Maintenance Manual (47-004 R21, 1982) from
    bitsavers and extracted Chapter 3, Mechanical Configuration.
    Headline: Figure 3-1 gives PANEL SPACE 1292 mm (50.87in) x 482.6 mm (19in)
    and 711.2 mm (28in) upright to upright. 482.6 mm is exactly 19.00in — this
    is a standard EIA-310 rack. That revives mount candidate A: the fixed frame
    can be an off-the-shelf 19in rack panel on the existing uprights. Confirm by
    threading a rack screw into an upright (field sheet item B4).
    Also captured:
    - Door 13.045 F01, 54.32in x 24.3in, two spring latches at the top, foam
    gasket all around, vertical lou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
2026-08-27 docs(me4): monitor size validated — 27in IPS 1440p, 24in is undersized
    Rescales the concept to real cabinet geometry (24 x 71 overall, 3-1/8in
    base, ~19.75in clear opening) and validates monitor size against it.
    The correction that drives it: every earlier drawing assumed a 14.5in kiosk
    door inside a 19in opening. The machine has a ~24.3in louvered outer door
    covering the whole face, and the clean design replaces that door. So the
    usable face is 24.3in, not 14.5in. A 24in panel in portrait is 12.5in wide —
    51% of the door, with 5.9in of blank tan each side. It was the right answer
    to the wrong question.
    27in: 57% of door width, 13.9 x 24.7 outline, ~12 lb, IPS universal at this
    size. 3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
2026-08-27 docs(me4): derive door aperture from a uniform frame offset
    Per instruction, assume the frame offset is the same on all four sides. The
    measured clear opening then fixes everything else:
    offset = (24.00 - 19.75)/2 = 2.125in
    aperture = 19.75 x 63.625 (5.25-68.88in AFF)
    door = 24.30 x 68.175 (2.98in AFF), 0.15in overhang all round
    Self-consistency check passes: door height 68.175 = box 67.875 + 2 x 0.15,
    the same overhang the door already has in width (24.30 on a 24.00 cabinet,
    from the 3230 drawing). Two independently sourced numbers agreeing that way
    is good evidence the assumption is right.
    Consequence: the door is 68in tall, not the 30in every earlier drawing
    showed. M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
2026-08-27 drawings: rebuild the full set to measured geometry
    Replaces the pre-measurement drawings with a set generated from one shared
    geometry block (mechanical/drawings/make-drawings.py). Change a dimension
    there and every sheet regenerates — which is what we want, since C1 and the
    door height are still open.
    01 front-elevation whole thing at real scale; ADA band, screen and
    button heights, aperture and base callouts
    02 carrier-panel every feature dimensioned, with a schedule
    03 plan-section depth budget, swing envelope, the C1 requirement
    04 door-replacement as-found / door removed / carrier fitted, and why
    reu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
2026-08-28 docs: project status report for a parallel agent team
    Self-contained handoff. Covers what the project is, everything known about
    the machine with provenance separated four ways (measured / OEM / sibling
    model / derived), the design as it stands including the four decisions we
    reversed and why, the single open blocker, and the sources.
    Two sections matter most for anyone joining:
    - A repo map splitting current from superseded. Roughly half of mechanical/
    is obsolete but still present, and the 39 GitHub issues were written
    against the pre-measurement plan.
    - Parallel work boundaries. The software track is untouched and has no
    dependency on the cabinet, the monitor, or C1 — SW-A1 (con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
2026-08-28 mech: Rev 1 pivot — standalone kiosk, surface-mounted on the closed door
    The kiosk stops being a replacement door integrated into the cabinet
    aperture and becomes a self-contained product: enclosure, display, Pi,
    power and three buttons, built and bench-tested on a table, then hung on
    the front of the 3280's closed factory door. The machine is not opened,
    not drilled, not modified. The mounting adapter is deferred to its own
    subsystem — the enclosure only has to offer a flat back and a known weight.
    Why: the old design couldn't be tested until it was on the machine, was
    blocked on C1 (still unmeasured), loaded the artifact's original hinges,
    and failed by leaving the machine with no doo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
2026-08-28 mech: ADA reach drives kiosk placement — buttons become the datum
    Corrects the placement logic. The previous study fixed the button height at
    40" AFF for no stated reason and then declared the 32" a geometric failure.
    That was backwards: the button height is the design input, not an output.
    Now: ADA 2010 §308 sets the legal window (15"-48" AFF, same for unobstructed
    forward and side reach), a human-factors argument picks 38" inside it, and
    kiosk placement is derived from there.
    kiosk bottom = B - 3.25"
    kiosk top = B + KH - 3.25" <= 71.15" -> B <= 74.40" - KH
    Consequences:
    - 38" AFF is the Rev 1 target: 10" of margin under the ADA max, near elbow
    height standing, inside a s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
2026-08-28 mech: materials in plain English, real buy links, and the depth they save
    Rewrites the construction section for someone who doesn't already know what
    "composite panel or high-pressure laminate, bonded" means, and replaces the
    hand-waving with places you can actually order from.
    Added:
    - A four-card glossary. ACM is a metal sandwich with the colour baked on;
    HPL is Formica and is *not a board* (it's a 1/32" skin that has to be
    glued to plywood first); compact laminate is Formica thick enough to
    stand alone; Baltic birch is good plywood that still needs finishing.
    - Live buy links on every route: SendCutSend, Curbell, OnlineMetals,
    Midwest Airbrush, Wilsonart/Ledgeband, Fundermax, Mak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
2026-08-28 mech: Rev 1 cut files — P1 face plate and P2 button plate, ready to order
    Two DXFs for SendCutSend's ACM service, generated from the design study's
    geometry rather than redrawn by hand, so they can't drift from it.
    P1 face plate 15.37 x 28.69" window 12.17 x 21.24, button aperture
    11.87 x 3.00, 12 x 0.1875 mount
    P2 button plate 13.37 x 4.50" 3 x 30.5mm at 3.50" cc, 6 x 0.1875 mount
    R12 ASCII, LINE/ARC/CIRCLE only — no polylines, splines or text, which is
    what CNC quoting tools are least likely to misread.
    make-cutfiles.py self-checks on every run: all contours closed (verified by
    walking endpoints — every vertex used exactly twice), holes i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
    [P1-face-plate.dxf, P2-button-plate.dxf]
2026-08-28 mech: one-piece face plate — buttons cut straight in, P2 dropped
    Collapses the face plate and button plate into a single part, on the user's
    call after questioning why they were separate.
    The separate plate bought insurance against the switch cutout and charged
    three things for it:
    - Stiffness. Cutting both a 12.17 x 21.24 window AND an 11.87 x 3.00 button
    aperture out of one 3mm sheet left a 1.35" web as the only material
    joining the side rails below the screen. One piece leaves 2.25" above the
    buttons and 2.65" below.
    - Cost and assembly. Two parts on the invoice, six more holes, a second set
    of cleats, and a plate to align square in an aperture.
    - The wear argument didn't hold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
    [P1-face-plate.dxf, P2-button-plate.dxf]
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2026-08-29 mech(fab): record the P1 quote — ACM $61.43, aluminium priced and rejected
    Quoted both at SendCutSend today. ACM Black .118" with no secondary services
    comes to $61.43 and ships in about 3 days; 6061-T6 .125" deburred and powder
    coated to matte black comes to $214.72 and ships in about two weeks.
    Rejected the aluminium. It is not a bad part -- solid 6061 is stiffer and
    powder coat wraps the cut edges -- but the stiffness argument is already
    answered by the button rail, which carries the press load so the panel cannot
    flex under a thumb. 3.5x for stiffness we already have, with the monitor and
    the mounting adapter both still unfunded. The extra .007" was not the
    objection: it takes overall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
2026-08-29 mech: shelve the IKEA variant, keep the finding that outlives it
    The idea was only worth having if IKEA sold something usable directly. It
    doesn't. Once it reduced to "buy pine and cut it yourself" there was no reason
    to prefer IKEA over a lumber yard, and Baltic birch is better material than
    knotty IVAR pine anyway -- which the write-up already conceded. The box is
    built per the released package: 1/2" Baltic birch, sheets 300/301/302.
    Labelled rather than deleted, because one finding generalises well past IKEA:
    no off-the-shelf shallow cabinet can work at all. ADA 307.2 allows the kiosk
    4.000" of total projection and the shallowest wall cabinets made are 6-3/4"
    deep, while frames shallow e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
2026-08-29 mech: Home Depot buy plan and a thickness-parametric cut list
    Buy one 1/2" 4x8 PureBond birch sheet (833185, $59.98 at West Long Branch),
    take three breakdown cuts at the desk, cut every real dimension on a table saw.
    Two findings drove it. The nest is 0.096" too wide for a 24" handy panel, so
    one 2x4 cannot work -- and two ProWood birch 2x4s are $79.72, twenty dollars
    more than a full sheet of better plywood. The 4x8 is simultaneously the
    cheaper and the only workable option, and it leaves a complete spare set.
    Home Depot's panel saw is +/- 1/8", which is fine for breaking down a sheet
    and useless for parts that must meet a $61 face plate with fixed hole
    positions. So the three cuts are b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
2026-08-29 mech(cutlist): the chosen plan — birch 2x4 + MDF 2x4, and a generated store card
    Retargets the script at two 1/2" 2x4 project panels: ProWood birch 154153
    ($39.86) for the box and ProWood MDF 109097 ($27.48) for the rear cover, plus
    a hardwood 1x4 for cleats. $67.34 in panels.
    Consequences of the smaller panels, all now handled:
    - No cut desk at all. Two 2x4 panels fit in a car, so the script suppresses
    the Home Depot breakdown cuts entirely rather than printing advice that no
    longer applies. Their saw is +/- 1/8" and P1's hole pattern is fixed, so
    every dimension being cut by hand is the point, not a compromise.
    - Adds a check that P4 actually fits the second panel (14.332 x 27.65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
2026-08-29 mech(cutlist): --solid, for a 1x lumber frame with an MDF back
    Two 1x4 x 8 ft boards and one MDF 2x4 panel build the whole box. Board A rips
    once to 3.132 and yields the tube (85.1" of 96"); board B rips to 1.500 +
    0.750 + 0.750 and yields the VESA rails plus every cleat. P10 comes off the
    MDF -- 4.000" will not come out of a 3.5" board, which the script now checks.
    Three things this option changes, and the script had to learn all three:
    - The insert check inverts. With 3/4" solid walls P1's mounting holes land in
    the board's front EDGE, which is side grain with the drill axis crossing it
    -- strong. Plywood's edge is between plies and is the weakness every earlier
    variant was designe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
2026-08-29 mech(cutlist): finger-jointed primed pine — $52.37 and 0.719", not 0.750"
    Real West Long Branch stock picks the boards. PrimeLinx 1x6x8 radiata pine
    finger-joint PRIMED (280552, $16.37) and a 1x3x8 of the same (424600, $8.52)
    for the rails, plus the MDF 2x4 (109097, $27.48). $52.37 against $67.34 for
    the birch-and-MDF plan.
    Finger-jointed is the right choice here rather than a compromise. Common
    whitewood 1x6 is $2 cheaper and arrives bowed and knotty; finger-jointed stock
    is cut from selected short pieces, which relieves the internal stress that
    twists a board. A 28.69" side panel that must sit flat against a face plate is
    exactly the case that cares. It arrives primed, which we want any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
2026-08-29 mech(cutlist): crosscuts only — and the front cleats never fit the monitor
    The plan is now zero rips: the board's WIDTH becomes the box depth, so a 1x4
    gives a 3.5" deep tube by crosscut alone and a 1x3 supplies the button rail,
    rear cleats and VESA rails at full width. Nine crosscuts, a mitre saw, and
    Home Depot cuts the MDF -- the rear panel is deliberately 0.250" undersize and
    lands on a 2.500" ledge, so their +/- 1/8" cannot matter.
    The cost is depth. The enclosure is 3.618", leaving the mounting adapter 0.382"
    of the ADA 307.2 4.000" cap. That is the price of simplicity and it is tight.
    Along the way this turned up a real error that is NOT specific to the no-rip
    variant: the front c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
2026-08-30 mech: image-gen prompts for front, back, side and installed concept renders
    Four prompts plus a shared spec block, with proportions derived from
    fab-rev1/_p1.py rather than restated by hand. Image models follow ratios far
    better than inch dimensions, so every figure appears as both -- screen opening
    82% of the width, top edge 5% down, buttons 13% up from the bottom, spacing
    23% of the width, depth 24% of the width.
    The line that matters most is stated three times: the enclosure is EXACTLY
    twice as tall as it is wide. A 15 x 30 face is an unusual proportion and it is
    the first thing these models get wrong; everything else looks wrong once it is
    off. Includes a one-line correction to paste wh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
2026-08-30 mech: the window now overlaps the LCD — no bezel, a foam light seal, no shroud
    The window was cut generous, and the surplus landed on the monitor's own black
    bezel. Black on black, nothing shows -- except a bezel is not the same black as
    matte ACM, it has a different sheen, a moulded logo and a power LED, and there
    is always a shadow line at the transition. That reads as a monitor inside a
    hole, not as an instrument.
    So the rule is inverted. The window is now cut 3/16 SMALLER than the monitor's
    lit rectangle: the ACM masks the outer 3/32" of picture on every side and the
    bezel never appears. 11-1/2 x 20-9/16, down from 12-1/4 x 21-1/4. The masked
    strip is about 8 px of 1080 a side.
    Behin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
    [P1-face-plate.dxf]
2026-09-03 mech: Rev 3 concept — doors off, touchscreen on a conduit spine
    Rev 2 was finished, checked and buildable. It was also a couple of hundred
    dollars, a week of careful work, and a real chance of looking homemade. This
    throws the box away: both doors come off and go into storage, a length of steel
    conduit stands on the cabinet floor, and a 23.8" touchscreen hangs off it on a
    monitor arm with the card cage open behind.
    The three buttons move into the glass. Same BACK / HOME / NEXT, same docent
    screens, verbatim -- targets, never swipe. Gestures have no affordance, and
    swipe-only navigation fails WCAG 2.5.1 outright. Keeping the three commands
    means Rick's approved content survives the pivot u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
